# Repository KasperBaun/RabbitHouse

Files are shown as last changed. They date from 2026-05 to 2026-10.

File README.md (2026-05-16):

# OpenSCAD rabbit house

This repository contains OpenSCAD code for a rabbit house.  
The design includes a main house structure and an attached run for the rabbits to exercise.  

## Requirements
- The rabbits must have a cool place to hide should the weather be hot.
- The rabbits must have a dry place to hide should the weather be rainy.
- The rabbits must have a place to exercise and play. It should be possible for them to do binkies and run at full speed.
- The rabbits must be protected from predators, such as cats and birds of prey.
- The rabbits must be protected from the wind, especially in the winter.
- The rabbits must be protected from the sun, especially in the summer.
- The rabbits must have access to fresh air and natural light.
- The rabbits must have access to food and water.
- The rabbits must have access to a litter box or a designated area for waste.

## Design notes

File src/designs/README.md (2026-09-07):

# `designs/` — Active design source

L-shaped rabbit house + run. House gets a gable roof; yard gets a mesh lid
(or a mono-pitch for solid covers).
See `CLAUDE.md` (repo root) for full architecture, conventions, and zone split rules.

## Layout

```
designs/
  config.scad                # constants (RH_*, G_*) + roof-geometry helpers — read first
  ground.scad                # SHARED — grass / terrain
  roof_plates_skifer.scad    # cover: gable naturskifer (house only; per-layer entries)
  roof_plates_tagpap.scad    # cover: OSB + tagpap (house + yard)
  roof_plates_eternit.scad   # cover: C18 + Cembrit B7 (house + yard)
  roof_plates_polycarb.scad  # cover: polycarb slab (yard only)
  roof_plates_mesh.scad      # cover: welded-wire lid (yard default)
  house/                     # HUS-zone (X=0..2000, Y=0..3000) — gable roof + kælder
    foundation.scad basement.scad floor.scad framing.scad openings.scad
    roof.scad roof_gable.scad roof/haneband.scad
    roof_plates.scad cladding/cladding.scad + variants
  yard/                      # YARD-zone (X=2000..6000, Y=1000..3000) — mesh-top run
    foundation.scad framing.scad openings.scad
    roof.scad roof_plates.scad mesh.scad
```

## House cover options (`house_roof_cover` in `main.scad`)

| Cover | Roof shape | Slope | Materials |
|---|---|---|---|
| `skifer`  | Gable (35°) | n/a | genbrugs-naturskifer 30×60 i dobbelt dækning på 38×73 lægter + 25×50 afstandslister |
| `tagpap`  | Mono-pitch (4,6°) | 8 % fald | 18 mm OSB + 4 mm tagpap + alu sternkapsler |
| `eternit` | Mono-pitch (~14°) | 25 % fald (steeper eh_back) | 38×73 C18 lægter + Cembrit B7 |

## Yard cover options (`yard_roof_cover` in `main.scad`)

`mesh` (default — wire lid straight on the top plates), `polycarb`, `tagpap`, or `eternit`.

## Toggles

Top of `main.scad`: set `house_roof_cover`, `yard_roof_cover`,
`cladding_type`.
Comment/uncomment individual `Render*()` calls below to isolate a building system.

`PALETTE` is the palette vector threaded into every house `Render*()` call:
the cladding, casings, corner boards, soffit and vindskeder are painted black
as built, while structural timber (studs, spær, afstandslister, taglægter)
stays natural and the front door leaf is bare plywood.

With `house_roof_cover == "skifer"` the roof is rendered **step by step** — one
call per arbejdsplan work step (`RenderHouseRoofSpaer` → `-Udhaeng` → `-Sofit`
→ `-Undertag` → `-Afstandslister` → `-Laegter` → `-Stern` → `-Fodblik` →
`-Skifer` → `-Vindskeder` → `-Rygning`).
Comment calls in/out to preview each build stage.

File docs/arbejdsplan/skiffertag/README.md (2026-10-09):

# Skiffertag — byggeplan

> Saddeltag 35°, kip langs husets dybde. Genbrugs-naturskifer 30×60 cm i
> klassisk dobbelt dækning på lægter over diffusionsåbent banevareundertag.
> Reference: [`guide-naturskifertag.md`](../../../guide-naturskifertag.md) —
> **ved tvivl gælder guiden**, og ved konflikt med skiferleverandørens
> anvisning gælder leverandøren.

## Hvor er vi nu

| # | Skridt | Status |
|---|---|---|
| 1 | [Spær](01-spaer.md) | ✅ rejst |
| 1a | [**Udhængsspær + klodser**](01a-udhaengsspaer.md) | ⚠️ **ny — skal op før 1b/2** |
| 1b | [Sofit](01b-sofit.md) | ⚠️ **omprojekteret: 4 sider, ventilerede lameller** |
| 2 | [Undertag](02-undertag.md) | ⚠️ lagt, men skal **forlænges ud i gavludhænget** |
| 3 | [Afstandslister](03-afstandslister.md) | ⚠️ sat, men mangler **2 lister over udhængsspærene** |
| 4 | [**Lægter**](04-laegter.md) | ⬅️ **næste skridt — og det mest kritiske** |
| 5 | [Sternbrædder](05-stern.md) | ⚠️ lav stern — skal op **før L1** |
| 6 | [Tagfodsblik, fuglegitter + tagrende](06-fodblik.md) | ⚠️ blikket skal på **før L1** |
| 7 | [Sortering af sten](07-sortering.md) | kan gøres parallelt med 4–6 |
| 8 | [Læg skifer](08-skifer.md) | |
| 9 | [Dobbelt vindskede](09-vindskeder.md) | |
| 10 | [Rygning](10-rygning.md) | |

Skridtene matcher 1:1 `Render*`-kaldene i `src/main.scad` — kommentér de
efterfølgende kald ud for at se hvert byggetrin i 3D.

> **Ændring (2026-09-07): gavludhænget bliver bygget færdigt.** Udhænget blev
> båret alene af de udkragede lægter, og de ligger 28 mm over spærplanet. Derfor
> kunne undertaget ikke føres ud, og tagskægget var kun lukket ved de to
> tagfødder. Der kommer nu **ét udhængsspær pr. gavl i spærplanet**
> ([1a](01a-udhaengsspaer.md)); så løber undertaget helt ud, sofitten lukker
> **alle fire** tagskæg ([1b](01b-sofit.md)), og lægterne får anlæg i spidsen.
> Samtidig går stern og vindskede-underbræt fra 25×150 til **25×200**, så de
> dækker spærende + sofitlamel. Trin 1–3 står som bygget og skal
> eftermonteres/forlænges — se de enkelte sider.

> **Ændring (2026-10-09): lægteafstand 255 mm, lægter 38×73, tagrende.**
> Pladerne er hullet **245 mm fra overkanten** og sømmes derfor i lægten
> *under* den, overkanten hviler på. Med den gamle plan (225 mm) ville sømmet
> ramme pladen nedenunder. Planen er nu Komproments standard: 255 mm, pladens
> overkant midt på lægten, overlæg 90 mm. Der kommer tagrende, så forkanten
> ligger 50 mm forbi L1. Lægteplan: [04](04-laegter.md), rækker: [08](08-skifer.md).
> **Rækkefølgen ved tagfoden er stern → tagfodsblik → undertag ud over blikket
> → L1** — nummereringen 4–6 er historisk.

## Nøglemål (kontrolleret)

| Mål | Værdi | Kommer af |
|---|---|---|
| Taghældning | 35° | `G_PITCH_DEG` |
| Skråflade, spærende → kip | **1500 mm** | spærets overkant, jf. skæretegningen |
| Lægteafstand på skråfladen | **255 mm** | pladerne er hullet 245 mm fra overkanten |
| Overlæg (plade *n* over *n−2*) | **90 mm** | 600 − 2 × 255 |
| Rækker pr. tagflade | 7 = række 1 (skåret, skjult) + 4 hele + 2 skårne i toppen | |
| Plader pr. række | **11** | 3340 mm med 1–5 mm fuger |
| Lægter pr. tagflade | **7** (L1–L7), T1 **38×73** | |
| Gavludhæng, bærende | **145 mm** pr. side | udhængsspær + lægteudkragning |
| Udhængsspær + undertag, bredde | **3290 mm** | 3000 + 2 × 145 |
| Lægtelængde | **3290 mm** | 3000 + 2 × 145 udkragning |
| Skiferfladens bredde | **3340 mm** | 3000 + 2 × 170 (til vindskedens yderside) |
| Yderste tagkant | **3390 mm** | 3000 + 2 × 195 (overliggerens yderside) |
| Sofit, tagfod | 280 mm skråmål | 229 vandret / cos 35° — 5 lameller |
| Sofit, gavl | 97 mm | 145 udhæng − 48 mm beklædningstykkelse — 2 lameller |
| Stern / vindskede-underbræt | **25×200** | 63 stak + 95 spær + 21 sofit = 179 skal dækkes |
| Skiferforkant forbi spærenden (L1's underkant) | **50 mm** | 25 mm foran sternen, ned i tagrenden |

### Hvorfor 255 mm

Pladerne er hullet 245 mm fra overkanten. Hver plade sømmes derfor i lægten
under den, dens overkant hviler på, og sømmet skal gå fri af overkanten på
pladen nedenunder. Det kræver en lægteafstand over 245 mm — leverandøren
skriver "lægteafstand altid 255 mm".

| Lægteafstand | Sømmet i forhold til pladen under | Overlæg | Plader i alt |
|---|---|---|---|
| **255 mm** (valgt) | 10 mm fri | **90 mm** | **132** |
| 225 mm (den gamle plan) | 20 mm nede i pladen — umuligt | 150 mm | 168 |

Prisen er margen: 90 mm overlæg er guidens minimum ved 35°, ikke mere. Den
gamle plan forudsatte huller 25–40 mm fra overkanten; de 25–40 mm er afstanden
fra **side**kanten.

## De tre tjek — afklaret

**1. Skråfladen S = 1500 mm. ✅ Bekræftet — du skal ikke måle om.**
Den er regnet ud af dine egne skæretegninger,
[01-spaer-tegninger.html](01-spaer-tegninger.html): spæremnet er et
parallelogram med lige lange kanter på **1500 mm** og lodrette snit i begge
ender. Hælmærket sidder 280 mm fra fodenden langs underkanten, hvilket giver
280 × cos 35° = 229 mm vandret udhæng, og 1500 × cos 35° = 1229 mm vandret
fra fodende til kip — altså præcis kip 1000 mm inde fra vægydersiden.
Geometrien lukker.

> Fugleudskæringen sænker hele taget ~38 mm i forhold til den teoretiske
> linje (det står også på tegningen). Det er en ren lodret forskydning og
> ændrer **ikke** skråfladen — lægteplanen måles fra spærenden og er
> upåvirket.

**2. Sømdimension.** Måles når stenene er hjemme: 4–8 mm sten → 2,8×40
kobbersøm, tykkere/rustik → 3,0×50. Bestil ~500 stk. Det eneste ufravigelige
er at de skal være **kobber**, ikke galvaniserede.

**3. Ventilationsspalten. ✅ Afklaret — der skal ikke ændres noget.**
De 63 mm er rigeligt, fordi 70 mm-kravet slet ikke gælder dette hulrum.
Der er to hulrum i en tagkonstruktion, og de har hver sit krav:

| Hulrum | Krav | Dit tag |
|---|---|---|
| **Over** undertaget (afstandsliste → tagdækning) | **min. 25 mm** | 25 + 38 = **63 mm** ✅ |
| **Under** undertaget (undertag → isolering), kun i en *ventileret* konstruktion | 50 mm ved fast undertag, **70 mm** ved banevare | findes ikke her |

De 70 mm er afstanden mellem undertag og **isolering** — ikke mellem undertag
og skifer. Taget her har ingen isolering oppe mod undertaget (arbejdsplanens
§8 isolerer kun vægge og evt. gulv), så det nederste hulrum eksisterer ikke,
og kravet gælder ikke. Afstandslisten på 25 mm er nøjagtig det, en
banevare kræver ovenpå. **Lægterne kan gå på nu.**

### Det der derimod skal være i orden: at luften kan komme IND og UD

Spaltehøjden er ikke problemet — gennemstrømningen er. Kanalen der lufter er
de **25 mm mellem afstandslisterne, under lægterne**, og den skal være åben i
begge ender:

- **Tagfod (indtag):** kanalen løber ud under L1 til tagkanten.
  Tagfodsblikket ligger under undertaget og over den lave sterns top, så de
  25 mm under L1 står åbne. **Fuglegitteret skal sidde her — i
  afstandsliste-gabet under L1.** Sofittens spalter
  ([01b](01b-sofit.md)) sidder i et *andet* hulrum, under undertaget, og
  erstatter ikke gitteret her.
- **Kip (aftræk):** L7 sidder 10 mm under kippen. Kanalerne løber
  *under* lægterne og mødes i kippen mellem de to L7. De skal ud under rygningsbrædderne, der er
  klodset op på 15 mm lister — **lad rygningens ender være åbne** (eller brug
  en ventileret rygning), ellers står luften stille.

> **Hvis du alligevel isolerer taget:** læg isoleringen **helt op mod**
> undertaget (uventileret konstruktion) — det kræver at undertaget er
> diffusionsåbent, og at der er en tæt dampspærre indvendigt. Læg den
> **aldrig** med en luftspalte på under 70 mm under banevaren; med 95 mm spær
> ville der kun blive 25 mm isolering tilbage, og det er værre end ingenting.
> Der lå mineraluld i et spærfag ved tagfoden på billedet — afklar om det er
> isolering eller bare en prop.

## Lægteplan (skridt 4 — det kritiske)

Mål på skråfladen fra L1's underkant (= spærenden). Pladens overkant ligger
**midt på lægten**; pladen sømmes i lægten under. Klodser, tegninger og
fremgangsmåde: [04-laegter.md](04-laegter.md).

| Lægte | Midte | Pladens top hviler her | Sømmes her |
|---|---|---|---|
| L1 | 36,5 (underkant 0) | — | række 1 (345 mm, skåret af bunden) |
| L2 | **295** | række 1 | række 2 (hel) |
| L3 | **550** | række 2 | række 3 (hel) |
| L4 | **805** | række 3 | række 4 (hel) |
| L5 | **1060** | række 4 | række 5 (hel) |
| L6 | **1315** | række 5 | række 6 (470 mm, skåret af toppen) |
| L7 | 1453,5 (overkant 1490) | række 6 | række 7 (~255 mm = resten fra række 1, nye huller) |

Kontrollen på planen: hvert søm sidder 46,5 mm over lægtens underkant og
10 mm over overkanten på pladen nedenunder.

## Indkøb — det der mangler

| Materiale | Dimension | Køb | Skridt |
|---|---|---|---|
| Konstruktionstræ C24, udhængsspær | 45×95 mm | **2 stk à 3,6 m** (4 × 1500; klodser af afkortet) | 1a |
| Skruer, udhængsspær/klodser | 5,0×80 | 48 stk + 2 hulplader | 1a |
| Høvlet forskalling m/fas, sofitlameller | 21×45 mm (jem & fix 25×50) | **22 stk à 2,4 m** (~45 m brugt) | 1b |
| Insektnet, rustfrit/alu ≤ 2 mm | 300 / 100 mm bredt | ~7 m + ~6 m | 1b |
| Afstandslister, ekstra over udhængsspær | 25×50 mm | 4 stk à 1,5 m (6 m) | 3 |
| Taglægter T1 | 38×73 mm | **14 stk à 3,6 m** (14 × 3290 brugt) | 4 |
| Søm til lægter | 100 mm | ~170 stk (2 pr. lægte × spær) | 4 |
| Sternbrædder | 25×200 mm | 2 stk à 3,6 m | 5 |
| Tagfodsblik, sort/antracit | — | 7 m | 6 |
| Fuglegitter, ventileret, sort | — | 7 m | 6 |
| Tagrende m. rendejern, endebunde, nedløb | — | 2 × ~3,4 m | 6 |
| Opklodsningsliste | 10×25 mm trykimp. | 7 m | 6 |
| **Genbrugs-naturskifer** | 30×60 cm | **165 stk** (132 i taget + ~25 % genbrugsspild) | 7, 8 |
| **Kobbersøm, riflet** | 2,8×40 mm (se tjek 2) | **500 stk ≈ 1,5 kg** (308 brugt) | 8 |
| Kip-liste (kun hvis toprækken vipper) | 8×25 mm | 7 m | 8 |
| Vindskede, underbræt | 25×200 mm | 4 stk à ~1,9 m (8 m) | 9 |
| Vindskede, overligger | 25×150 mm | 4 stk à ~1,9 m (8 m) | 9 |
| Rygningsbrædder | 25×150 mm | 2 stk à 3,4 m | 10 |
| Opklodsningslister, rygning | 15 mm | rest-træ | 10 |
| Zink-rygning | — | 3,5 m | 10 |
| Skruer m. tætningsskive | — | 1 pak | 10 |

Brædderne til randafslutningen: **25×200 ca. 15 m** (stern + vindskede-underbræt)
og **25×150 ca. 15 m** (overligger + rygning) — køb hver dimension samlet. Beregningen af de 132 plader: 11 pr. række (3340 mm inkl. fuger),
7 rækker pr. tagflade, 2 tagflader = 154 stykker — men række 7 skæres af
resterne fra række 1, så der går 6 × 11 × 2 plader til.

**Køb ALDRIG galvaniserede søm til skiferen — kun kobber.** Et skifertag
holder 100+ år; galvaniserede søm gør ikke.

## Sikkerhed (gælder alle skridt)

- Arbejd fra stillads/platform og fra lægterne — **betræd aldrig færdig
  dækning**. Stenene revner usynligt under punktlast.
- Støvmaske + briller ved hugning/skæring af sten.
- Sten løftes op i små bundter; sortér altid på jorden (skridt 7).

## Valg der er truffet — og som guiden ville gøre anderledes

- **Tagrende ved begge tagfødder** (ændret 2026-10-09 — før var den fravalgt).
  Tagfodsblik og skiferforkant ender i renden, se [06](06-fodblik.md).
- **Ingen skiferkit i randzonen.** Guidens §6.6 anbefaler T-kitning af de 3
  yderste sten ved gavlene *selv med undertag*. Det er fravalgt her, fordi
  undertaget og den lukkede dobbelte vindskede tager fygesne og slagregn.
  Overlægget er nu 90 mm (minimum ved 35°), så margenen er mindre end i den
  gamle plan — genovervej kitning, hvis huset står vindudsat.

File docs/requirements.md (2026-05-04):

# Rabbit House — Requirements

One-line, ID-traceable requirements for the rabbit-house build modelled in this repo.
Each `REQ-NNN` is atomic so it can be cited from the PRD, code comments, or build notes.
Where a number is grounded in an external welfare standard, the source is cited inline.

Conventions:
- IDs are stable; never renumber. Add new ones at the end of their section.
- "Rabbit zone" = the meshed enclosure on the left/front (`rabbit_x0`..`rabbit_x1`).
- "Sleeping zone" = the insulated nest box / shelter inside the rabbit zone.

## A. Animal welfare & space

- **REQ-001** — The rabbit zone must give the rabbits continuous 24/7 access to a connected enclosure of at least 3.0 m × 2.0 m × 1.0 m. (src: RWAF minimum)
- **REQ-002** — The rabbit zone must allow each rabbit to take three full hops in a straight line and to stand fully upright on its hind legs without head contact. (src: RWAF)
- **REQ-003** — The structure must house at least one bonded pair; rabbits must never be kept singly in this build.
- **REQ-004** — The rabbit zone must provide separated functional areas for sleeping, eating, drinking, and toileting.
- **REQ-005** — At least one hiding shelter must be available per rabbit, plus one spare (the "n+1" rule), permanently accessible.
- **REQ-006** — The rabbit zone must include at least one elevated platform or lookout the rabbits can jump onto, for vertical enrichment.
- **REQ-007** — A safe digging substrate (sand pit or soil tray) must be available so the rabbits can dig without compromising the perimeter.

## B. Predator protection

- **REQ-008** — All boundaries between the rabbit zone and the outside world must be covered with welded wire mesh of aperture ≤ 25 mm × 13 mm and gauge ≥ 19 (≈ 1.0 mm wire). (src: The Rabbit House, RWAF)
- **REQ-009** — The rabbit-zone perimeter must defeat burrowing predators, either by a buried wire skirt ≥ 300 mm deep or a horizontal apron ≥ 500 mm wide pinned at ground level.
- **REQ-010** — Every gate, hatch, and door into the rabbit zone must use a two-stage lockable latch that resists raccoon, fox, and child opening.
- **REQ-011** — The sluice must operate as an airlock: the inner door and outer door must never be open simultaneously.
- **REQ-012** — The roof above the rabbit zone must fully enclose against aerial predators (hawks, owls) and climbing predators (cats, martens, rats).
- **REQ-013** — No mesh aperture, edge gap, or trim seam in the rabbit zone may exceed 12 mm at any point.
- **REQ-014** — Mesh must be fastened with screwed staples or wire, not stapled with a tacker, on faces a fox can pull at.

## C. Weather & climate (Nordic / temperate-maritime)

- **REQ-015** — The structure must shelter the rabbits from wind, driving rain, direct sun, and snow at all hours of the year.
- **REQ-016** — The sleeping zone must remain dry and draught-free during sustained west-/south-westerly wind and rain.
- **REQ-017** — The roof and overhangs must shed water away from every wall and away from the sleeping zone.
- **REQ-018** — The roof must support a snow load of at least 1.0 kN/m² without deflection, consistent with Nordic minimums.
- **REQ-019** — At least one shaded sub-zone with internal air temperature ≤ 25 °C must exist in the rabbit area at all summer hours; rabbits suffer heat stress above 25 °C.
- **REQ-020** — The build must include an insulated, draught-free nest box usable down to −10 °C ambient.
- **REQ-021** — The foundation must lift the floor ≥ 100 mm above finished grade to keep the floor dry in heavy rain. (existing: `base_height = 120 mm` — meets this.)

## D. Ventilation & air quality

- **REQ-022** — The rabbit zone must support continuous cross-ventilation without exposing the sleeping zone to direct draught. (src: RSPCA)
- **REQ-023** — High and low ventilation openings must exist on opposite walls so warm, ammonia-laden air can rise out and fresh air can replace it.
- **REQ-024** — No part of the rabbit zone may depend on a single closable opening as its only air exchange.

## E. Floor, drainage & substrate

- **REQ-025** — Surface water inside the rabbit zone must drain so no puddle persists more than 30 minutes after heavy rain.
- **REQ-026** — The site must slope (or be regraded to slope) away from the structure at ≥ 1:50 on all sides.
- **REQ-027** — The rabbit floor must be dig-proof: a solid slab, a buried mesh layer, or a wire base under any loose substrate.
- **REQ-028** — Every substrate in rabbit contact must be non-toxic, low-dust, and chew-safe.

## F. Materials & toxicity

- **REQ-029** — No pressure-treated, CCA-treated, or creosoted wood may be used anywhere a rabbit can chew, lick, or rub against it.
- **REQ-030** — All paints, stains, and sealants in the rabbit zone must be fully cured, food-safe, and free of lead, solvent VOCs, and zinc-rich primers in chew range.
- **REQ-031** — All mesh in the rabbit zone must be galvanised-after-welding (GAW) or vinyl-coated, with cut edges deburred or capped to remove zinc flakes and burrs.
- **REQ-032** — Any insulation reachable by rabbits must sit behind a chew-proof inner skin.
- **REQ-033** — No plant from the rabbit-toxic list (yew, oleander, foxglove, lily, ivy, rhododendron, laburnum) may grow within the rabbit zone or overhang it.

## G. Maintenance & human access

- **REQ-034** — A human must be able to walk fully upright into the rabbit zone through a door ≥ 800 mm wide and ≥ 1900 mm high. (existing sluice: 800 × 2100 mm — meets this.)
- **REQ-035** — Every surface inside the rabbit zone must tolerate hosing and standard pet-safe disinfectant for daily cleaning.
- **REQ-036** — Daily droppings clean-up and food/water refill must be achievable by one adult in ≤ 15 minutes.
- **REQ-037** — A removable or hinged-access tray, panel, or floor section must exist beneath any zone where droppings concentrate.
- **REQ-038** — All lighting fixtures and electrical cabling inside the rabbit zone must be either out of rabbit reach or shielded behind chew-proof conduit.

## H. Reserved (former human seating area)

The original Section H covered a human seating area included in the v1
design. That scope was removed in the v2 redesign. IDs `REQ-039` through
`REQ-042` remain reserved and will not be reused.

## H2. House-yard v2 (gabled shelter + polycarbonate run)

Added 2026-04-29 alongside the introduction of the `house_yard_v2` design.
The v2 right-side zone is no longer a human area — it is a 4 m × 3 m
mesh-walled rabbit run with a translucent roof, attached to a 2 m × 3 m
solid gabled rabbit shelter on the left.

- **REQ-049** — The airlock vestibule must double as bedding/hay storage and provide ≥ 0.5 m³ usable storage volume.
- **REQ-050** — The transparent run roof must be ≥ 10 mm twin-wall polycarbonate, UV-stable, and fixed with chew/pry-resistant fasteners that defeat the same predator load as REQ-008/REQ-012.
- **REQ-051** — The pet door in the house↔run partition must remain permanently passable; it is not a sluice and must not be lockable in service. The combined house+run is the rabbit zone of REQ-001.
- **REQ-052** — The house roof ridge runs along the X axis at Y=`width`/2; gable end walls are at X=0 and X=2000, both cladded as triangles. The X=2000 partition gable is the wind-bracing wall the run roof leans against. Eaves run along X at Y=0 (front) and Y=`width` (back).
- **REQ-053** — The run roof must drain to a gutter on the back (Y=`width`) edge; no water may discharge against the partition at X=2000.

## H3. House-yard v3 (unified mono-pitch + ground-plug yard)

Added 2026-05-03 alongside the introduction of the `house_yard_v3` design.
v3 keeps the v2 zoning (2 m × 3 m solid house + 4 m × 3 m mesh yard) but
replaces the gabled shelter and translucent run roof with **one continuous
mono-pitch roof** spanning the entire footprint, and replaces the v2 full
slab with a **slab-under-house-only + ground-plug-yard** foundation.

Updated 2026-05-04: human entry was rerouted through the yard (REQ-059..062),
and yard exterior siding was specified as mesh-only (no clad strip).

- **REQ-054** — A single mono-pitch roof must span the entire 6 m × 3 m
  footprint (house + yard) with no break at the partition. Drop runs
  front-to-back; the drainage gutter sits on the back (Y=`width`) eave.
- **REQ-055** — The concrete slab must extend ONLY under the house
  (X=0..`house_len`); the yard floor must remain natural ground.
- **REQ-056** — Yard corner posts must transfer load through concrete
  ground plugs (not the slab); each plug sits at least 40 mm below
  grade and 100 mm proud, with a steel post-base bracket isolating
  wood from soil moisture.
- **REQ-057** — The yard interior must be live grass at grade, with
  predator-proofing achieved by the perimeter buried apron skirt
  (REQ-009) — no buried mesh layer is required under the yard floor.
- **REQ-058** — Reserved (former back-wall driving-rain clad strip;
  removed in 2026-05-04 revision in favour of full-height mesh).
- **REQ-059** — The exterior of all three yard walls (front, back,
  right) must be welded-wire mesh only, with no klink-board cladding
  on any yard exterior face. Mesh must meet REQ-008 aperture/wire
  requirements (≤ 25 × 13 mm aperture, ≥ 1 mm wire).
- **REQ-060** — Vertical wood stiles (≈ 60 × 60 mm) must divide the
  mesh walls into approximately 1 m panels for structural rigidity
  and constructible mesh-stretching. The yard mesh door's own L/R
  frame stiles count toward this 1 m rhythm on the front wall.
- **REQ-061** — Human entry to the house must be through the yard:
  an exterior mesh door in the yard front (Y=0) leads into the yard,
  and a separate solid human door in the partition (X=`house_len`)
  leads from the yard into the house. The house has no door on its
  outside face (Y=0).
- **REQ-062** — REQ-011 (airlock semantics) is satisfied by the
  yard-as-vestibule: the yard mesh door is the "outer" stage and the
  partition human door is the "inner" stage, and they must not be
  open simultaneously when rabbits are unconfined in the yard.

## I. Safety

- **REQ-043** — No element reachable by rabbits or humans may have a sharp edge, exposed nail, splinter, or pinch point.
- **REQ-044** — All hinges, latches, and fasteners exposed to weather must be rated for outdoor use and remain free-moving for at least 5 years.
- **REQ-045** — No swallowable loose parts (screws, staples, wire offcuts) may be left in the rabbit zone after construction.

## J. Site, regulation & longevity

- **REQ-046** — Footprint and height must comply with the local jurisdiction's rules for unattached outbuildings before construction begins (in DK, sheds > 10 m² generally need a permit).
- **REQ-047** — The structure must respect the locally required setback distance from neighbouring property lines.
- **REQ-048** — The build must remain serviceable for ≥ 10 years with annual maintenance; every wear part (mesh, latches, lighting) must be replaceable without dismantling structural framing.

## References

- RWAF — Space Recommendations: https://rabbitwelfare.co.uk/space-recommendations/
- RWAF — Outdoor Housing: https://rabbitwelfare.co.uk/outdoor-housing/
- RSPCA — Rabbits' Housing Needs (2018): https://www.rspca.org.uk/documents/1494939/7712578/RSPCA+Rabbit+housing+advice+-+updated+May+2018+(on+website).pdf
- The Rabbit House — Wire Mesh Guide: https://www.therabbithouse.com/outdoor/rabbit-mesh.asp
- RSPCA Australia — Where should I keep my rabbits?: https://kb.rspca.org.au/knowledge-base/where-should-i-keep-my-rabbits/

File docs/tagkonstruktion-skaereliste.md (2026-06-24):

# Skæreliste — Tagkonstruktion

> Implementeret i `src/designs/roof_structure.scad` (`RenderHouseRoof()` + `RenderYardRoof()`) + `roof_plates_tagpap.scad` / `roof_plates_eternit.scad`. Materialelister i [tagkonstruktion_eternit.md](tagkonstruktion_eternit.md) og [tagkonstruktion_tagpap.md](tagkonstruktion_tagpap.md). Variant-sammenligning: [tagkonstruktion.md](tagkonstruktion.md).

Skæreliste pr. element. Mål er millimeter; positioner er i bygningens koordinatsystem (X = længde-akse, Y = front→bag).

## Zone-opdeling

Tag-spær og lookouts opdeles ved X=1500 (partition-linjen). Cover-lagene (OSB-dæk, tagpap, eternit) er én sammenhængende dæk — de straddler hl og holdes "fælles" i materialelisten.

| Zone | Tag-elementer der hører til | Render-modul |
| ---- | --- | --- |
| Hus  | Spær X ≤ 1200 (4 stk) + venstre vindskede + venstre lookouts (3) + venstre side-fascia/soffit + front+bag fascia/soffit [0..hl] | `RenderHouseRoof()`  |
| Yard | Spær X ≥ 1800 (9 stk) + højre vindskede + højre lookouts (3) + højre side-fascia/soffit + front+bag fascia/soffit [hl..ll] | `RenderYardRoof()` |
| Fælles | OSB-dæk (15 plader straddler hl); tagpap baner; alu-inddækning; eternit B7 plader + skruer (bølger straddler hl); C18 lægter | `RenderRoofPlates(cover)` |

## Konventioner

- **Fugleudskæring** (= bird's mouth): trekantet kile saves ud af spær-bunden ved bæreflader, så spæret får et fladt sæde på V1's og V2's *flade* toprem.
- På V3 og V5's *skrå* toprem (kun gable-spæret rører dem) er der ingen udskæring — toprem er allerede skåret til samme hældning som spær-bunden, så de matcher fladt mod fladt.
- "Bæreflade" = de 95 mm hvor spæret krydser en toprem.
- Sæde-snit = vandret savsnit, hæl-snit = lodret savsnit. Ved vores lave hældning (4,6°) er hæl-snittet 0 mm — det er reelt bare en lille kile.

## Sammendrag

| Vare | Antal | Hus | Yard | Fælles | Brug |
| --- | ----- | --- | ---- | --- | --- |
| **Træværk** | | | | | |
| Reglar 47×100×3000 mm gran C24 | 13 | 4 | 9 | | Spær (11 regulære + 2 vindskede) |
| OSB-3 plade TG4 18 mm 2397×600 mm | 15 | | | 15 | Tagdæk ~19 m² — plader straddler hl |
| Imp. stern 25×125×3600 mm gran | 6 | 1 | 3 | 2 | Sternbræt hele perimeter — front+bag straddler hl |
| **Tagdækning** | | | | | |
| Phønix Selvbyggerpap 1×5 m | 5 | | | 5 | Selvklæbende, ~5 m²/rulle |
| TagSealer 300 ml Phønix | 3 | | | 3 | Bitumen-fugemasse |
| **Sternkapsler (cap over sternbræt-top)** | | | | | |
| Sternkapsel lige alu 35×25×1000 mm | 13 | | | 13 | Front + bag eaves — sektioner straddler hl |
| Sternkapsel skrå kant alu 35×25×1000 mm | 6 | 3 | 3 | | Venstre side (hus) + højre side (yard) |
| **Beslag og fastgørelse** | | | | | |
| Vinkelbeslag 90×90×40 mm 20-pak | 3 | 1 | 2 | | ~14 brackets på hus-spær, ~34 på yard-spær |
| OSB/spær-skruer 5×80 mm | 250 | | | 250 | OSB på spær + vinkelbeslag-fastgørelse |
| Rustfri tagskruer m. EPDM-pakning | 1 pk  | | | 1 pk | Alu-profiler på OSB (~50 stk) |
| Galvaniseret tagpapsøm | 1 æsk | | | 1 æsk  | Selvbyggerpap på OSB (~150 stk) |

---

## Spær (13 stk — ALLE skæres identisk)

**Råstof:** 45×95×3000 mm gran C24, skæres til **2910 mm** langs slopen.

**Markering på hvert spær (mål fra front-ende):**

| Position på spær | Hvad det er |
| --- | --- |
| 0..220 mm | Front-overhang (stikker ud over V1) |
| 220..315 mm | V1 bæreflade — **fugleudskæring her**  |
| 315..2625 mm | Fri span over bygnings-indre |
| 2625..2720 mm | V2 bæreflade — **fugleudskæring her**  |
| 2720..2910 mm | Bag-overhang (stikker ud over V2) |

**Fugleudskæring (samme ved begge bæreflader, spejlvendt):**

| Mål | Værdi |
| --- | --- |
| Længde langs spær | 95 mm (= toprem-dybde) |
| Største dybde | 7,6 mm ved bæringens indre kant |
| Mindste dybde | 0 mm ved bæringens ydre kant |
| Form | Trekantet kile — sav vandret ind så dybden vokser jævnt |

Ved V1-bæringen er det den indre kant (mod bygningen, position 315 mm) der er 7,6 mm dyb; ved V2-bæringen er det den indre kant (position 2625 mm) der er 7,6 mm dyb. Med andre ord: kilen bliver dybere INDAD mod bygningens midte.

**X-positioner for de 13 spær (på tværs af bygningen):**

| Type | Antal | Zone | X-positioner |
| --- | ----- | ---- | --- |
| Vindskede V | 1 | Hus  | X = -220 |
| Gable V3 | 1 | Hus  | X = 0 (hviler også fladt på V3's skrå toprem hele vejen) |
| Indre (hus) | 2 | Hus  | X = 600, 1200 |
| Indre (yard)| 7 | Yard | X = 1800, 2400, 3000, 3600, 4200, 4800, 5400 |
| Gable V5 | 1 | Yard | X = 5955 (hviler også fladt på V5's skrå toprem) |
| Vindskede H | 1 | Yard | X = 6175 |

**Vinkelbeslag pr. spær:**

- **Regulære spær (11 stk):** 2 vinkelbeslag pr. bæreflade — én på hver side af spæret. Total 4 pr. spær = 44 stk.
- **Vindskede-spær (2 stk):** 1 vinkelbeslag pr. bæreflade på indersiden af spæret (ydersiden er i luften past toprem-forlængelsens ende). Total 2 pr. spær = 4 stk.

Horisontal flange skrues i toprem-toppen; vertikal flange skrues i spær-siden.

---

## OSB-tagdæk (15 plader TG4 18 mm 2397 × 600 mm)

Plader lægges med deres **lange side (2397 mm) PÅ TVÆRS af spær** (= langs X-aksen). Pladens **600 mm bredde matcher spær c/c 600 EXACT** — plade-kanter lander automatisk på spær-centerlinier uden trimning. TG4 har tand-og-not på alle 4 sider, så samlinger glider sammen og er selv-tætnende.

**Layout — 3 plader pr. række × 5 rækker:**

```
        ┌──────┬──────┬──┐  Y=2900 (bag-overhang slut)
        │  R5 (cut 500) │  ← cut sidste række til 500 mm
        ├──────┼──────┼──┤  Y=2400
        │  R4 (3 plader)│
        ├──────┼──────┼──┤  Y=1800
        │  R3           │
        ├──────┼──────┼──┤  Y=1200
        │  R2           │
        ├──────┼──────┼──┤  Y=600
        │  R1           │
        └──────┴──────┴──┘  Y=0 (front-overhang slut)
        X=0   X=2397 X=4794 X=6440
```

**Cuts pr. række (langs X = 6440 mm):**
- Plade 1: 2397 mm fuld (X=0..2397)
- Plade 2: 2397 mm fuld (X=2397..4794)
- Plade 3: skæres til 1646 mm fra fuld 2397 (X=4794..6440, spild 751 mm)

**Cuts langs Y (5 rækker à 600 mm = 3000 mm; tagflade er 2900 mm):**
- Rækker 1-4: 600 mm fulde
- Række 5: skæres til 500 mm bredde fra fuld 600 (spild 100 mm pr. plade i sidste række)

**Skruer:** 5×80 skruer c/c 150 mm langs alle plade-kanter (= langs samlingerne, gennem TG ind i spær) + c/c 300 mm i pladens midte. ~10 skruer pr. plade × 15 plader ≈ 150 skruer i alt.

- Tagflade total: 6440 × 2900 mm ≈ 18,7 m²
- Plade-areal: 2397 × 600 = 1,44 m² pr. plade
- 15 plader × 1,44 m² = 21,6 m² → dækker med ~2,9 m² spild (~14 %)

---

## Sternbræt 25×125 mm imprægneret gran (~19 m)

Sternbræt monteres så **toppen sidder 7 mm over tagpap-toppen** (sternbræt-top = wall_top + 125, tagpap-top = wall_top + 118). Det danner en lille opadgående kant der forhindrer vand i at løbe ud over tagets sider og giver et beskyttet sted til sternkapslen.

| Position | Længde | Note |
| --- | --- | --- |
| Front-eave | 6440 mm | Horisontalt langs hele front-overhang |
| Bag-eave | 6440 mm | Horisontalt langs hele bag-overhang |
| Venstre-eave | 2910 mm | Følger tagets hældning (skrå) |
| Højre-eave | 2910 mm | Samme |
| **Total** | **18,7 m** | 6 stk × 3600 mm dækker med spild |

Skrues fast i spær-ender (front + bag) og vindskede-spær (sider) med 5×80 skruer c/c ~300 mm. Selvbyggerpap rulles op og over sternbræt-toppen og foldes ned over outer-face så vandet drypper af kanten.

---

## Sternkapsler — 2 forskellige typer

Cap'er der glider ned over sternbræt-toppen + den oprullede tagpap-kant. Beskytter sternbræt-træet mod vejret og giver et rent finish.

**Sternkapsel lige alu 35×25×1000 mm** på front + bag eaves (vandret):

| Position | Længde  | Stk |
| --- | --- | --- |
| Front-eave  | 6440 mm | 7 |
| Bag-eave | 6440 mm | 7 |

(7 stk pr. eave: 6 fulde × 1 m = 6 m + 7. stk overlapper 50 mm for at nå de 6,44 m.)

**Sternkapsel skrå kant alu 35×25×1000 mm** på venstre + højre sider (skrå med taget):

| Position | Længde  | Stk |
| --- | --- | --- |
| Venstre-eave | 2910 mm | 3 |
| Højre-eave | 2910 mm | 3 |

Glides ned over sternbræt-toppen (25 mm kapsel-bredde matcher 25 mm sternbræt-tykkelse). Skrues fast gennem topfladen ind i sternbræt-toppen med rustfri tagskruer c/c ~500 mm. **VIGTIGT:** Læg en stribe TagSealer (bitumen-fugemasse, IKKE silikone) UNDER sternkapselen før montering — tætningslag mellem den oprullede tagpap og alu-cap'en. Overlap mellem to sternkapsler: 50 mm, topstykket OVENPÅ bundstykket i vand-strømmens retning.

---

## Tjek

- **Spær:** 13 × 2910 mm = 37,8 m brugt af 13 × 3000 mm = 39 m stock → ~1,2 m spild
- **OSB:** 15 plader TG4 × 1,44 m² = 21,6 m² brugt af 18,7 m² tagflade → ~2,9 m² spild (~14 %). TG4's 600 mm bredde matcher spær c/c 600 så plade-samlinger lander automatisk på spær-centerlinier
- **Selvbyggerpap:** 5 ruller × 5 m² = 25 m² brugt af 19 m² tagflade → ~6 m² spild til overlap mellem baner
- **Sternbræt 25×125:** ~19 m fra 6 × 3600 mm = 21,6 m stock → ~2,6 m spild. Top 7 mm over tagpap
- **Sternkapsler:** lige 13 stk dækker 13 m (front+bag = 12,9 m); skrå 6 stk dækker 6 m (sider = 5,8 m). ~700 kr billigere end tagfod+vindskede
- **Vinkelbeslag:** 11 regulære × 4 + 2 vindskede × 2 = 48 stk, dækket af 3 × 20-pak = 60 stk
- **TagSealer:** 3 × 300 ml = 900 ml. ~19 m fugelinje under alu-flange + overlap-fuger ≈ 25 m bead → 1 tube pr. ~8 m, så 3 tuber er rigeligt

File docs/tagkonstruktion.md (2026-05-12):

# Tagkonstruktion (v3) — variant-sammenligning

To varianter af tag-dækningen er tilgængelige. Vælg via `roof_cover` i `src/designs/v3/build.scad`.

| Aspekt | Eternit B7 | Tagpap (OSB + selvbyggerpap) |
| --- | --- | --- |
| **Cover** | Cembrit/Swisspearl B7 sortblå bølgeplade, 1100×570 mm | Phønix Selvbyggerpap 2-lags på OSB-3 TG4 18 mm |
| **Hældning** | 14° (`roof_cover = "eternit_14"`) | 4,6° / 8 % (`roof_cover = "tagpap_osb"`) |
| **Bærelag** | C18 lægter 38×73 c/c 460 mm | OSB-3 TG4 18 mm (også diaphragm) |
| **Trim** | Stern uden vinkelrygning (åben top-eave) | Sternbræt + alu sternkapsler på alle 4 eaves |
| **Holdbarhed** | ~70 år, vedligeholdelsesfri | ~10-15 år, omlægning forventes |
| **Vægt** | ~14 kg/m² (tungere — kræver støttende lægter) | ~5 kg/m² (lettere, men OSB bærer hele last) |
| **Sværhedsgrad** | Højere — eksakt c/c 460 mm lægtning, plade-håndtering | Lavere — OSB lægges som almindelige plader, tagpap simpelt |
| **Pris-overslag** | ~9.760 kr (~11.000 kr inkl. spild) | ~10.905 kr (~12.000 kr inkl. spild) |
| **Doc** | [tagkonstruktion_eternit.md](tagkonstruktion_eternit.md) | [tagkonstruktion_tagpap.md](tagkonstruktion_tagpap.md)  |

## Fælles træværk

Følgende elementer er identiske i begge varianter og dokumenteres i hver enkelt fil:

- **Spær** 47×100 C24, 13 stk c/c 600 (11 regulære + 2 vindskede), m. fugleudskæring
- **Sternbræt** 25×125 imprægneret gran, ~19 m langs perimeteren (6 stk × 3,6 m)
- **Vinkelbeslag** 90×90×40 — ~48 stk på spær-bæreflader
- **Sofitt** 18 mm krydsfiner på alle 4 tagskæg-undersider
- **Tagrende** 110 mm + nedløb Ø75 ved bag-eave

## Hvilken skal jeg vælge?

| Hvis du... | Vælg |
|---|---|
| Vil have lang holdbarhed (~70 år) og minimal vedligeholdelse | Eternit B7 |
| Vil have lavest pris og hurtigst byggetid | Tagpap |
| Vil have rent visuelt udtryk uden synlige overlap | Tagpap (eller B7 med stort plade-format 1100×1525) |
| Vil have karakteristisk industri-look med synlige bølger | Eternit B7 |
| Er nervøs for korrekt c/c 460 mm lægtning og plade-skæring | Tagpap |

## Stykkeliste på tværs

Detaljeret skæreliste (spær-positioner, fugleudskæring-mål, vinkelbeslag-fordeling) er fælles og findes i [tagkonstruktion-skaereliste.md](tagkonstruktion-skaereliste.md).

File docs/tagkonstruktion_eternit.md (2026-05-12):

# Tagkonstruktion — Eternit B7 variant

> Implementeret i `src/designs/v3/tagkonstruktion_eternit.scad`
> Vælges med `roof_cover = "eternit_14"` i `src/designs/v3/build.scad` (14° hældning, spec-korrekt geometri).
> Fælles framing/sofitt-moduler i `tagkonstruktion_faelles.scad`.

Ensidet tagflade dækket med **Cembrit/Swisspearl B7 eternit-bølgeplader (sortblå)** på C18 taglægter. Pladen er ~70 år holdbar og vedligeholdelsesfri.

Per Swisspearl montagevejledning (rev. 02.2025) kræver B7 minimum **14° hældning** (standard overlæg). Default-værdien `"eternit_b7"` (4,6°) bruges kun til layout-sammenligning og er **ikke buildbar**.

## Lag (oppefra og ned)

1. **Swisspearl 100 Tagskruer** 6×100 mm m. EPDM-pakning — 2 stk pr. plade i bølgetop
2. **Cembrit B7 bølgeplade** 1100×570 mm, 6,5 mm tyk, montagehøjde 65 mm, sortblå
3. **C18 taglægter** 38×73 mm, c/c præcis **460 mm** (= 570 plade − 110 overlap)
4. **Spær** 47×100 C24 c/c 600 mm
5. **Sternbræt** 25×125 + tagrende på bag-eaven

```
                                    ┌─ Swisspearl 100 tagskrue (2 pr. plade)
                                    │
        B7 ╭─╮ ╭─╮ ╭─╮ ╭─╮ ╭─╮ ╭─╮  ▼   ← sortblå corrugated, 65 mm bølgehøjde
       ───┴─┴─┴─┴─┴─┴─┴─┴─┴─┴─┴─┴─┴────  ← lægte-top (B7 trough hviler her)
       │ C18 lægte 38×73 c/c 460 mm  │
       ├─────────────────────────────┤   ← spær-top
       │  spær 47×100 c/c 600 mm     │
       │                             │
       ├──── V1/V2 toprem ───────────┤   ← wall-top
                                          (lag-stak set fra siden)

Bund-pladen hænger 60 mm ud over back-sternbræt-yderkant (drip i tagrende).
Første lægte sidder a-mål = 510 mm inde fra back-sternbræt-yderkant.
```

## Mål

| Egenskab | Værdi |
| --- | --- |
| Tagflade | 6,44 × 2,95 m (~19 m² incl. overhangs) |
| Hældning | 14° (`roof_cover = "eternit_14"`) |
| Spær | 13 stk 47×100 C24 c/c 600 (11 regulære + 2 vindskede) |
| Overhæng | 220 mm front + 180 mm bag + 220 mm i hver side |
| Lægter | 6 stk 38×73 C18 (~6,44 m hver), c/c 460 mm |
| Tagdække | 49 hele B7 plader (7 rækker × 7 plader bredt) + ~5 % spild |
| Lag over spær | 110 mm (38 lægte + 6,5 plade-trough + 65 bølge-amplitude) |

## Konstruktion

**Spær** 47×100 C24 skæres til ~2910 mm med fugleudskæring ved hver ende (95 mm langs × 7,6 mm dyb trekantet kile — se [tagkonstruktion-skaereliste.md](tagkonstruktion-skaereliste.md)). 11 spær c/c 600 fra X=0 til X=5955; vindskede-spær ved X=-220 og X=6175 hviler på den forlængede V1+V2 toprem. Hvert regulært spær fastgøres med 2 vinkelbeslag pr. bæreflade; vindskede-spær får 1 på indersiden.

**C18 taglægter** 38×73 lægges PERPENDIKULÆRT på spær og sømmes med varmforzinkede sømstifter i hvert spær-krydsningspunkt. Layout er bestemt af B7 plade-geometrien:

- **Første lægte (a-mål)** sidder 510 mm inde fra back-sternbræt-yderkant — det er top-kanten af nederste B7 plade-række. Bund-pladens nederste kant hænger 60 mm ud over sternbrættet ned i tagrenden.
- **Subsequent lægter** c/c **præcis 460 mm** opad mod front (= 570 plade − 110 mm minimum overlæg).
- **Top-pladen** ved front-eaven skæres til pasning (~250 mm høj cut-stykke) og bæres af næst-øverste lægte; kort overhang < 460 mm = ingen separat top-lægte nødvendig.

Resultat: **6 lægter** ved Y = 2195 / 1735 / 1275 / 815 / 355 / −105 (V3-koordinatsystem).

**B7 bølgeplader** lægges fra venstre mod højre, startende med nederste række ved bag-eaven. Hver plade overlapper plade-rækken nedenfor med 110 mm og naboplade med 78 mm (= 1100 − 1022 montagebredde). Plader skrues fast med **Swisspearl 100 Tagskruer 6×100** — 2 pr. plade i bølgetop ved øverste kant. Plade-tælling pr. tagflade: **7 rækker langs slope × 7 plader bredt = 49 plader**.

**Sternbræt** 25×125 langs hele perimeteren skrues fast i spær-enderne. Sternbræt-toppen placeres LIGE UNDER eternit-trough-niveau (lægte-top), så B7 pladen kan dryppe frit forbi sternbræt og ned i tagrenden uden kollision.

**Top-eave (front, høj):** Bemærk — denne variant bruger **ikke vinkelrygning**. Top-cut-pladen ved front-eaven har en åben corrugated kant. Hvis vind-drevet regn er en bekymring, kan kanten lukkes med profil-skumstrimmel eller en hjemmebøjet zink-flange (~60 mm bred), men ikke som fabriksleveret Swisspearl-vinkelrygning.

**Tagrende** 110 mm monteres på back-sternbrættets yder-flade med beslag c/c ~550 mm. Nedløb Ø75 i højre side leder vandet til faldsten eller faskine.

## Materialeliste

Stykkevis skæreliste: [tagkonstruktion-skaereliste.md](tagkonstruktion-skaereliste.md).

| # | Vare | Beskrivelse | Antal | Enhed | Pris/enh | I alt | Note |
| --- | --- | --- | ----- | ----- | --- | --- | ---- |
| | **Træværk** | | | | | | |
| 1 | RAW Spærtræ C24 47×100×3000 mm gran | Spær — 11 regulære + 2 vindskede | 13 | stk | ~85,00 | ~1.105 | est. (Stark) |
| 2 | RAW C18 taglægte 38×73×4200 mm | 6 rækker à ~6,44 m + spild → 11 stk × 4,2 m | 11 | stk | 52,50 | 577,50 | [10-4.dk](https://www.10-4.dk/varer/byggematerialer/trae/laegter/38x73mm-taglaegte-c18-1731038073) |
| 3 | Imp. stern 25×125×3600 mm gran | Sternbræt — hele perimeter (~19 m) | 6 | stk | 82,60 | 495,72 | [xl-byg.dk](https://www.xl-byg.dk/produkt/xl-byg-ru-sternbraet-over-trykimpraegneret-25-x-125-x-3600-mm-1143025122-0360) |
| | **Tagdækning (Cembrit B7 sortblå)** | | | | | | |
| 4 | Swisspearl B7 bølgeplade FK 1100×570 sortblå | 49 hele + ~5 % spild ved hjørne-skæringer | 52 | stk | 95,00 | 4.940 | [bygxtra.dk](https://www.bygxtra.dk/produkter/swisspearl-boelgeplade-b7-fk-i-sortblaa-1100x570-mm-1617012) |
| 5 | Swisspearl 100 Tagskrue 6×100 sortblå (100-pak) | 2 pr. plade × 49 + spild = ~108 | 2 | pak | 425,00 | 850,00 | [davidsen.dk](https://www.davidsen.dk/swisspearl-100-tagskrue-m-taetningsskive-6x100-mm-graa-100-stk-c-id525046-p-51601506116) |
| 6 | Swisspearl PVC Skumstrimmel 4,5 mm | Tværgående tætning ved overlap-samlinger (rulle) | 1 | rulle | ~150 | ~150 | est. |
| | **Vandhåndtering** | | | | | | |
| 7 | Tagrende 110 mm stål/plast (sæt 6,5 m) | Bag-eave inkl. tilbehør | 1 | sæt | ~600 | ~600 | est. |
| 8 | Tagrende-beslag | c/c 550 mm langs bag-eave | 12 | stk | ~30 | ~360 | est. |
| 9 | Endebund tagrende 110 mm | Lukker tagrendens to ender | 2 | stk | ~50 | ~100 | est. |
| 10  | Bladsamler 75-82 mm | Filter ved nedløbsudgang | 1 | stk | ~80 | ~80 | est. |
| 11  | Nedløbsrør Ø75 mm × 3 m | Fra tagrende ned til faldsten | 1 | stk | ~200 | ~200 | est. |
| 12  | Nedløbsbøjning Ø75 mm | Knæ-stykker (top + bund) | 2 | stk | ~80 | ~160 | est. |
| | **Beslag og fastgørelse** | | | | | | |
| 13  | Paslode vinkelbeslag 90×90×40 mm (20-pak)  | 48 nødvendige → 3 pak (60 stk) | 3 | pak | ~150 | ~450 | est. ([wood-online](https://wood-online.dk/shop/paslode-vinkelbeslag-542p.html) enkelt-pris 8,48 kr) |
| 14  | NKT Basic skrue 5×80 ruspert (250-pak) | Vinkelbeslag + sternbræt + lægter på spær | 1 | pak | ~225 | ~225 | est. ([bygxtra](https://www.bygxtra.dk/produkter/nkt-basic-skrue-outdoor-50x8045-mm-ruspert-1000-250-stk-1673216)) |
| 15  | NKT lægtesøm 3,4×80 varmf. (≈210 stk) | 2 søm pr. krydsningspunkt × 6 × 13 ≈ 156 | 1 | pak | ~70 | ~70 | est. |
| | | | | | **Total** | **~9.760** | (≈11.000 inkl. realistisk spild + sofitt-kryds.) |

### Note: plade-format

Cembrit B7 fås også i **1100×1525 mm**. Med større plader bliver der færre rækker langs slope (3 i stedet for 7) og dermed kun ~21 plader i stedet for 49. Pris-pr-m² er lavere, men hver plade er tungere og sværere at håndtere solo. SCAD-modellen viser **1100×570 mm** format — skift både SCAD og BOM hvis du foretrækker det store format.

## Bygge-rækkefølge

1. Skær 11 regulære + 2 vindskede spær til ~2910 mm; indsav fugleudskæring ved hver ende
2. Læg spær c/c 600 mm: regulære på V1+V2 toprem, vindskede på toprem-forlængelsen ved X=-220 og X=6175
3. Skru fast med vinkelbeslag — 2 pr. bæreflade på regulære, 1 på indersiden af vindskede
4. **Mål første lægte-position**: 510 mm inde fra back-sternbræt-yderkant. Søm lægte 38×73 (~6,44 m) på alle spær med varmforzinkede søm 3,4×80 — 2 pr. krydsningspunkt
5. **Læg subsequent lægter** c/c præcis 460 mm opad mod front. Brug en målestok eller kort lægte som "klods" mellem hver lægte. Total 6 lægter
6. Monter sternbrædder 25×125 rundt om hele perimeteren. **Sternbræt-toppen placeres LIGE UNDER lægte-top-niveau** (~7 mm under), så B7 pladen kan dryppe frit forbi
7. **Læg B7 pladerne** fra venstre mod højre, startende med nederste række ved bag-eaven:
   - Hver plade overlapper nedenfor med 110 mm og naboplade med 78 mm (= 1022 mm effektiv montagebredde)
   - Skru hver plade med **2 Swisspearl 100 Tagskruer** i bølgetop ved øverste kant (skruer gennem overlap-zonen fastgør også pladen ovenfor)
   - Per spec: brug HJ/HU plader (pre-borede huller). Hvis FK plader, bor ø10 mm hul i bølgetop først, derefter skru fast vinkelret på tagfladen
   - Top-eave: top-cut-pladen efterlades med åben corrugated kant (eller bøj en zink-flange som top-cap hvis ønsket)
8. Monter tagrende-beslag på bag-sternbrædet c/c 550 mm. Klik tagrende på, sæt endebund i hver ende
9. Monter nedløb: bladsamler ved tagrende-udgang → nedløbsbøjning → 3 m nedløbsrør → bøjning ved bunden → ud til faldsten/faskine

## Vigtigt om B7 installation

**Boring og skæring**: Bor- og skærestøv SKAL fjernes straks med en blød børste — hvis det ligger ude på pladen kan det "brænde" sig fast på overfladen. Brug vinkelsliber med diamant-skive ved skæring; bor med ø10 mm bor altid i bølgetop, aldrig i bølgedal.

**Trædesikkerhed**: B7 plader er IKKE trædesikre færdig-installeret. For vores rabbit-house gælder det IKKE — taget er ikke beregnet til at gå på efter installation.

**Skrue-pakning**: Swisspearl 100 Tagskruer har EPDM-pakning under hovedet — sørg for at den ikke deformeres ved overtilspænding. Skru kun til pakningen er let komprimeret (10-20 %).

**Garanti**: Swisspearl yder 20 års garanti på B7 plader når montagevejledning følges. Skæringer i sider/kanter skal være rene; ingen revner.

## Rendering / verificering

```powershell
pwsh src/scripts/audit_renders.ps1
# → _renders/v3/audit/05_tagkonstruktion.png

# Eller direkte (skift roof_cover i build.scad til "eternit_14" først):
openscad -o b7.png src/main.scad
```

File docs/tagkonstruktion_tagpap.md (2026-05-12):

# Tagkonstruktion — Tagpap (OSB + selvbyggerpap) variant

> Implementeret i `src/designs/v3/tagkonstruktion_tagpap.scad`
> Vælges med `roof_cover = "tagpap_osb"` (eller `"tagpap"`) i `src/designs/v3/build.scad`.
> Fælles framing/sofitt-moduler i `tagkonstruktion_faelles.scad`.

Ensidet tagflade dækket med **Phønix Selvbyggerpap (2-lags)** svejset på 18 mm OSB-3 TG4 plader. Tagpap kører på v3's default-hældning (4,6° / 8 % fald) — minimum-hældning for tagpap er 2,5 % = 1,4°, så vi er rigeligt indenfor spec. Sternbræt-toppen afsluttes med **aluinddækning (sternkapsler)** på alle 4 eaves.

## Lag (oppefra og ned)

1. **Aluinddækning / sternkapsler** 35×25 mm — på alle 4 eaves
2. **Phønix Selvbyggerpap overpap** (svejset til underpap)
3. **Phønix Selvbyggerpap underpap** (mekanisk fastgjort til OSB)
4. **OSB-3 TG4** 18 mm — bærer hele coveret, sømmes på spær
5. **Spær** 47×100 C24 c/c 600 mm
6. **Sternbræt** 25×125 + tagrende på bag-eaven

```
        ╔═══════════════════════════════════╗  ← aluinddækning (sternkapsler)
        ║ Phønix overpap (svejset)          ║  ← 4 mm
        ║ Phønix underpap                   ║  ← 3 mm
        ║ OSB-3 TG4 18 mm                   ║  ← 18 mm
        ╠═══════════════════════════════════╣  ← spær-top
        │  spær 47×100 c/c 600 mm           │
        │                                   │
        ├──── V1/V2 toprem ─────────────────┤   ← wall-top
                                                (lag-stak set fra siden)

Tagpap rulles ud parallelt med tagfaldet, overlap 100 mm langs eave, 80 mm
mellem ruller. Sternkapsler glider ned over sternbræt-top + oprullet tagpap-kant.
```

## Mål

| Egenskab | Værdi |
| --- | --- |
| Tagflade | 6,44 × 2,95 m (~19 m² incl. overhangs) |
| Hældning | 4,6° (`roof_cover = "tagpap_osb"`) |
| Spær | 13 stk 47×100 C24 c/c 600 (11 regulære + 2 vindskede) |
| Overhæng | 220 mm front + 180 mm bag + 220 mm i hver side |
| OSB-bærelag | ~7-8 plader 1220×2440 mm (skæres til pasning) |
| Tagpap | 2 lag (underpap + overpap) × ~19 m² ≈ 4 ruller à 10 m² |
| Aluinddækning | ~19 m langs perimeteren (alle 4 eaves) |
| Lag over spær | ~25 mm (18 OSB + 3 underpap + 4 overpap) |

## Konstruktion

**Spær** 47×100 C24 skæres til ~2910 mm med fugleudskæring ved hver ende (samme som eternit-varianten — se [tagkonstruktion-skaereliste.md](tagkonstruktion-skaereliste.md)). 11 spær c/c 600 fra X=0 til X=5955; vindskede-spær ved X=-220 og X=6175 hviler på den forlængede V1+V2 toprem. Hvert regulært spær fastgøres med 2 vinkelbeslag pr. bæreflade; vindskede-spær får 1 på indersiden.

**OSB-3 TG4 18 mm** lægges direkte på spær-toppen med TG4-noter mod nabopladens. Plader skæres til pasning ved barge-spærene (~220 mm overhang på hver side). OSB sømmes på spær med varmforzinkede 3,1×80 søm c/c ~150 mm langs spær-linjen. OSB-pladen fungerer både som bærelag for tagpap OG som diaphragm der overfører kantilever-moment fra side-overhangene tilbage til de bærende spær — derfor er OSB-tykkelsen vigtig.

**Phønix Selvbyggerpap** rulles ud parallelt med tagfaldet (= med længdeaksen langs X). Underpap fastgøres mekanisk til OSB med tagpapsøm c/c ~250 mm. Overpap svejses eller limes med TagSealer til underpap med 100 mm langs-overlap og 80 mm mellem ruller. Yderkant rulles 50 mm op ad sternbrættet og fastgøres med tagpapsøm; sternkapslen glider derefter ned over toppen som beskyttelse.

**Sternbræt** 25×125 langs hele perimeteren skrues fast i spær-enderne. Sternbræt-toppen sidder ~7 mm over tagpap-toppen (= cover_thick + STERN_LIP) så aluinddækningen får et lille kant at gribe om.

**Aluinddækning / sternkapsler** 35×25 mm cap-profil glides ned over sternbræt-top + den oprullede tagpap-kant. Topflange 25 mm dækker sternbræt-top; outer drop 35 mm hænger ned udvendigt forbi sternbræt-front-fladen. Skrues fast med små tag-papskruer c/c ~400 mm i topflangen.

**Tagrende** 110 mm monteres på back-sternbrættets yder-flade med beslag c/c ~550 mm. Tagpap-kanten ved bag-eaven hænger fri ud over tagrende-midtlinjen for korrekt drip. Nedløb Ø75 i højre side leder vandet til faldsten eller faskine.

## Materialeliste

Stykkevis skæreliste: [tagkonstruktion-skaereliste.md](tagkonstruktion-skaereliste.md).

| # | Vare | Beskrivelse | Antal | Enhed | Pris/enh | I alt | Note |
| --- | --- | --- | ----- | ----- | --- | --- | ---- |
| | **Træværk** | | | | | | |
| 1 | RAW Spærtræ C24 47×100×3000 mm gran | Spær — 11 regulære + 2 vindskede | 13 | stk | ~85,00 | ~1.105 | est. (Stark) |
| 2 | Imp. stern 25×125×3600 mm gran | Sternbræt — hele perimeter (~19 m) | 6 | stk | 82,60 | 495,72 | [xl-byg.dk](https://www.xl-byg.dk/produkt/xl-byg-ru-sternbraet-over-trykimpraegneret-25-x-125-x-3600-mm-1143025122-0360) |
| | **Cover (OSB + tagpap)** | | | | | | |
| 3 | OSB-3 TG4 18 mm 1220×2440 mm | Bærelag — 19 m² / 2,98 m²/plade + spild ≈ 8 plader  | 8 | stk | ~225 | ~1.800 | est. |
| 4 | Phønix Selvbyggerpap rulle (~10 m²) | 2 lag (underpap + overpap) × 19 m² + spild = 4 ruller | 4 | rulle | ~600 | ~2.400 | est. |
| 5 | Phønix TagSealer tube | Lim/svejs ved overlap-samlinger | 3 | stk | ~150 | ~450 | est. |
| | **Aluinddækning / sternkapsler** | | | | | | |
| 6 | Alu sternkapsel 35×25 mm (2-3 m lgd.) | Hele perimeteren (~19 m) — alle 4 eaves | 19 | m | ~120 | ~2.280 | est. |
| 7 | Tag-papskrue m. EPDM (100-pak) | Fastgør alu-cap c/c 400 mm | 1 | pak | ~120 | ~120 | est. |
| | **Vandhåndtering** | | | | | | |
| 8 | Tagrende 110 mm stål/plast (sæt 6,5 m) | Bag-eave inkl. tilbehør | 1 | sæt | ~600 | ~600 | est. |
| 9 | Tagrende-beslag | c/c 550 mm langs bag-eave | 12 | stk | ~30 | ~360 | est. |
| 10  | Endebund tagrende 110 mm | Lukker tagrendens to ender | 2 | stk | ~50 | ~100 | est. |
| 11  | Bladsamler 75-82 mm | Filter ved nedløbsudgang | 1 | stk | ~80 | ~80 | est. |
| 12  | Nedløbsrør Ø75 mm × 3 m | Fra tagrende ned til faldsten | 1 | stk | ~200 | ~200 | est. |
| 13  | Nedløbsbøjning Ø75 mm | Knæ-stykker (top + bund) | 2 | stk | ~80 | ~160 | est. |
| | **Beslag og fastgørelse** | | | | | | |
| 14  | Paslode vinkelbeslag 90×90×40 mm (20-pak)  | 48 nødvendige → 3 pak (60 stk) | 3 | pak | ~150 | ~450 | est. ([wood-online](https://wood-online.dk/shop/paslode-vinkelbeslag-542p.html) enkelt-pris 8,48 kr) |
| 15  | NKT Basic skrue 5×80 ruspert (250-pak) | Vinkelbeslag + sternbræt | 1 | pak | ~225 | ~225 | est. ([bygxtra](https://www.bygxtra.dk/produkter/nkt-basic-skrue-outdoor-50x8045-mm-ruspert-1000-250-stk-1673216)) |
| 16  | Tagpapsøm 25 mm varmforzinket (1 kg ≈ 400 stk) | Underpap + 50 mm op ad sternbræt | 1 | æske  | ~80 | ~80 | est. |
| | | | | | **Total** | **~10.905** | (≈12.000 inkl. realistisk spild + sofitt-kryds.) |

## Bygge-rækkefølge

1. Skær 11 regulære + 2 vindskede spær til ~2910 mm; indsav fugleudskæring ved hver ende
2. Læg spær c/c 600 mm: regulære på V1+V2 toprem, vindskede på toprem-forlængelsen ved X=-220 og X=6175
3. Skru fast med vinkelbeslag — 2 pr. bæreflade på regulære, 1 på indersiden af vindskede
4. Læg OSB-3 TG4 plader på spær-toppen med TG4-noter mod hinanden. Søm fast med 3,1×80 varmforzinket c/c ~150 mm langs spær-linjen
5. Skær OSB til pasning ved barge-spærene (~220 mm side-overhang i hver side)
6. Monter sternbrædder 25×125 rundt om hele perimeteren. **Sternbræt-toppen sidder ~7 mm over OSB-tagpap-toppen** (cover_thick + STERN_LIP)
7. Rul Phønix Selvbyggerpap **underpap** ud parallelt med tagfaldet. Fastgør mekanisk med tagpapsøm c/c ~250 mm. Rul kanten 50 mm op ad sternbrættet i alle 4 sider
8. Rul Phønix Selvbyggerpap **overpap** ud. Svejs eller lim med TagSealer til underpap. Overlap 100 mm langs / 80 mm mellem ruller
9. Monter alu-sternkapsler ovenpå sternbræt-top + oprullet tagpap-kant. Skrues fast med tag-papskrue c/c 400 mm
10. Monter tagrende-beslag på bag-sternbrædet c/c 550 mm. Klik tagrende på, sæt endebund i hver ende
11. Monter nedløb: bladsamler ved tagrende-udgang → nedløbsbøjning → 3 m nedløbsrør → bøjning ved bunden → ud til faldsten/faskine

## Vigtigt om tagpap-installation

**Underlag**: OSB-pladerne SKAL være tørre før tagpap lægges på. Fugt-indhold > 18 % → tagpappen bobler op.

**Svejsning vs. lim**: Phønix Selvbyggerpap kan både svejses (med propan-brænder) eller limes (med TagSealer). For hobby-byg er lim simplere og sikrere — der er ingen åben ild, og du kan lægge pappen alene uden hjælper.

**Sternkapsel-orientering**: Topflange skal pege INDAD (mod tagcenter), drop-flange UDAD. Forkert orientering = vand løber under kapslen.

**Garanti**: Phønix yder 10 års garanti på Selvbyggerpap når montagevejledningen følges — herunder mindst 2,5 % fald (vi har 8 %), korrekt overlap, og fastgørelse iht. spec.

## Rendering / verificering

```powershell
pwsh src/scripts/audit_renders.ps1
# → _renders/v3/audit/05_tagkonstruktion.png

# Eller direkte (skift roof_cover i build.scad til "tagpap_osb"):
openscad -o tagpap.png src/main.scad
```

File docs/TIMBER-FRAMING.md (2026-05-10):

# Timber Framing Guidelines — Rabbit House

## Wood Species

- **Trykimprægneret fyr (pressure-treated pine)** for all structural timber in contact with or near the ground: bundrem, stolper, base frame
- **Gran (spruce)** acceptable for upper framing (toprem, losholter, spær) if kept dry under roof
- **NTR class AB** minimum for outdoor use (green-treated)
- All timber should be **construction graded C18 or C24** (ST or T1 marking in Denmark)

## Standard Dimensions (Danish market)

| Element | Dimension | Notes |
|---|---|---|
| Reglar / studs | 45×95 mm | Standard wall stud, sufficient for non-insulated outbuilding |
| Stolper / corner posts | 120×120 mm | Corners carrying roof load; 45×95 reglar elsewhere |
| Bundrem / bottom plate | 45×95 mm | Flat (lying on wide face), bolted to foundation |
| Toprem / top plate | 45×95 mm | Can double up (2×45×95) on long spans >4m |
| Front beam (remme) | 45×180 mm | Main front beam carrying roof, sized for span |
| Losholte / nogging | 45×95 mm | Horizontal bracing between studs |
| Spær / rafters | 45×95 mm, c/c 600 mm | Mono-pitch rafters; use toprem as bearer at both ends |

## Stud Spacing — Rules of Thumb for Small Outbuildings

This is **not** a dwelling. BR18 dimensional requirements for dwellings do not apply. For a small outbuilding (<50 m²):

### Where studs ARE needed
- **Every corner** of the building
- **Both sides of every opening** (doors, pass-throughs, windows)
- **At wall junctions** (where divider wall meets outer wall)
- **One mid-stud** on any wall span longer than ~2000 mm (stiffness, not code)

### Where studs are NOT needed
- **Mesh walls**: The mesh panel + frame provides lateral bracing. Corner posts and plates are sufficient.
- **Cladded walls with short spans** (<2m between supports): The cladding itself provides racking resistance.
- **Above openings**: A header beam (overligger) carries the load; no stud needed in the opening.

### Cladding support
- Klink cladding (22 mm boards) needs support at max **600 mm c/c** — but this can be horizontal battens (lægter) nailed to a few studs, not studs themselves
- For this project: studs at corners + openings + one mid-stud, then horizontal battens at 600 mm for cladding attachment

## Opening Framing

```
        ┌──── toprem ────────────────┐
        │                            │
   stud │    ┌── header ──┐          │ stud
        │    │            │          │
        │  jamb          jamb        │
        │  stud          stud        │
        │    │   opening  │          │
        │    │            │          │
        └──── bundrem ───────────────┘
```

- **Jamb studs**: Full height 45×95 on each side of opening
- **Header (overligger)**: 45×95 flat above opening, carries load from above
- **Sill (under windows)**: 45×95 flat, not structural

## Fastening

| Connection | Fastener |
|---|---|
| Bundrem to foundation | M10 anchor bolts or concrete screws, 600–1000 mm c/c |
| Stud to bundrem/toprem | Skrånagning (toe-nailing) 2× 3.1×90 mm galv. nails each side, or angle brackets |
| Toprem to stolper | 2× 5.0×100 mm screws + angle bracket |
| Cladding to studs/battens | 2.5×50 mm galv. ring-shank nails, 2 per board per support |
| Mesh to frame | 25 mm galv. staples or U-clips, 150 mm c/c |

## Beslag (steel connectors)

Defined in `lib/primitives/beslag.scad`. Each module renders the connector and emits a BOM row.

| Module | Use | Typical part |
|---|---|---|
| `ankerskrue_m10()` | bundrem → fundablok ring, c/c 1000 | M10 × 120 mm anchor screw |
| `vinkelbeslag()` | stud → bundrem / toprem at corners | BMF 90×90×2 angle bracket |
| `spaersko()` | spær → toprem, both ends | Simpson sloping rafter shoe |
| `bjaelkesko()` | beam → post | Beam joist hanger |
| `stroesko()` | floor strø → ledger | 45×95 joist hanger |

All beslag are hot-dip galvanised steel.

## Roof Load Path

```
  Roof → Toprem (front beam 45×180) → Corner posts (120×120)
                                     → Divider post (120×120)
       → Toprem (back, 45×95)       → Corner posts / mid stud
```

- Mono-pitch (ensidet taghældning): front is high side, back is low side
- Roof drop over 4m width: ~220 mm (≈3° slope, minimum for tagpap/roofing felt)
- All top beams slope from front to back — use `hull()` in OpenSCAD to model this

## This Project's Framing Summary

| Wall | Posts/Studs | Plates | Notes |
|---|---|---|---|
| **Back** | 2 corner + 1 mid | Bundrem + toprem (flat) | Cladded, no openings |
| **Front** | 3 posts (corners + divider) + 1 mid | Bundrem + beam (45×180) | Mesh attached to outside |
| **Left (rabbit)** | 2 corner + 1 mid (if >3m) | Bundrem + sloped toprem | Mesh wall, minimal framing |
| **Right (seating)** | 2 corner + 1 mid + window jambs | Bundrem + sloped toprem | Full cladding + window openings |
| **Divider** | 2 jamb studs at pass-through | Header above opening | Mesh + framed pass-through |

## General Notes

- All dimensions in millimeters
- Timber from standard Danish builders' merchants (Bauhaus, Stark, XL-BYG) comes in these sizes
- Pressure-treated timber must be dried before painting/staining — wait 2–3 months or use wet-on-wet primer
- Leave 5–10 mm air gap between bundrem and any concrete/slab for drainage
- Stainless steel or hot-dip galvanised fasteners only — electro-galv will corrode with treated timber

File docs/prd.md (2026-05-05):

# Rabbit House — Product Requirements Document

## 1. Vision

A garden structure that gives a bonded pair of pet rabbits a safe, enriched,
all-weather home.

The build is modelled in OpenSCAD (`main.scad`) and parameterised across three
size presets in `presets.scad`. This PRD defines the *why* behind the model;
the atomic *what* lives in [`requirements.md`](requirements.md) as `REQ-NNN`
items, cited from this document.

## 2. Goals

- **G1.** Rabbits express natural behaviours 24/7 — hopping, standing upright,
  digging, hiding, jumping up — without ever being shut into a small hutch.
  (REQ-001, REQ-002, REQ-005, REQ-006, REQ-007)
- **G2.** A bonded pair (or two pairs) live safely outdoors year-round in a
  Nordic climate. (REQ-015 to REQ-021)
- **G3.** The structure looks intentional in the garden — built shell,
  cladded back wall, gutter line — not a wire mess on the lawn.
- **G4.** Maintenance fits a 15-minute daily routine for one adult.
  (REQ-034 to REQ-037)

## 3. Non-goals

- Indoor / inside-the-house rabbit housing.
- Breeding or multi-litter colony housing.
- Commercial or farm-scale rabbit production.
- Permanent isolation pens for sick or quarantined animals (a vet trip and a
  carrier handle that case).
- A hutch that only gets opened for "exercise time" — RWAF guidance is
  explicit that this is no longer acceptable.
- A human seating, lounge, or co-occupied space sharing the structure. That
  was v1 scope and has been removed; the v2 right-side zone is a rabbit run.

## 4. Users

| User | Primary needs |
|---|---|
| **Garden owner with one bonded pair**, mid-skill DIY | Safe rabbits, easy daily care, garden that still looks like a garden |
| **Rabbit sitter** during owner absence | Walk-in access, obvious feeding/cleaning routine, predator-proof perimeter she can verify by eye |
| **Vet** doing a home visit | Possible to capture and inspect a rabbit without dismantling anything |

## 5. Size presets

Defined in `presets.scad` and selected in `config.scad` via `preset`.

| Preset | Length × Width × Height | Rabbit-zone length | Notes |
|---|---|---|---|
| `6x3` | 6.0 × 3.0 × 2.5 m | 3.3 m | Tight gardens, 1 bonded pair |
| `7x3` | 7.0 × 3.0 × 2.5 m | 4.0 m | **Default.** 1 bonded pair, generous interior space |
| `8x4` | 8.0 × 4.0 × 2.5 m | 4.5 m | Largest preset; room to scale toward two bonded pairs |

All three presets give the rabbit zone alone more than the RWAF
3.0 × 2.0 × 1.0 m absolute minimum (REQ-001), with substantial vertical
clearance for standing upright (REQ-002).

## 6. Layout principles

Multiple designs coexist in the model — `v1` (the original lean-to),
`v2` (the gabled-house + polycarb-run redesign), and `v3` (unified
mono-pitch over slab-house + grass-yard on plugs). All share these
directional decisions, with design-specific zoning overlaid on top.

- **Front** (`Y = 0`) is the open mesh face onto the garden / human entry.
- **Back** (`Y = width`) is the solid cladded wall, taking prevailing-wind
  and driving-rain duty (REQ-016).
- **Left** (`X = 0`), **Right** (`X = length`).

### `v1` zoning

- Mono-pitch roof; left side X=0..`rabbit_len` is the rabbit zone, right
  side is a human seating area. Sluice sits on the divider between rabbit
  zone and seating zone.

### `v2` zoning

- Left X=0..2000 is a solid gabled rabbit shelter:
  - Front-left corner (X=0..1000, Y=0..1000) is the airlock + bedding
    storage cell, with the only outside human door on its Y=0 face.
  - Insulated nest box against the back wall in the rest-of-house space.
  - High gable louver vent (X=0 face) + low back vent for cross-ventilation.
- Right X=2000..6000 is a mesh-walled rabbit run with a translucent
  polycarbonate roof:
  - Mesh on front (Y=0) and right (X=length) walls; back wall solid clad
    with a high vent strip; left wall is the partition gable.
  - Run roof slopes front-high to back-low, draining to the back gutter.
  - Buried apron skirt 500 mm wide on the three exterior sides for dig
    defeat.
- House↔run rabbit pet door at X=2000, low at Y≈1500 — permanently passable
  so the combined enclosure satisfies REQ-001.
- The two-stage human airlock (outer door on the front, inner door at
  Y=`airlock_d`) is the only human entry into the rabbit zone (REQ-011).

## 7. Constraints

- **Climate:** northern European temperate; design points: winter low ≈ −10 °C,
  summer high ≈ 30 °C, snow load ≥ 1.0 kN/m². (REQ-018, REQ-019, REQ-020)
- **Construction:** hobbyist DIY tools; lumber sized to standard metric stock
  (so wall_thickness, base_height, etc. round to buildable numbers).
- **Materials:** must satisfy the toxicity rules in section F of
  `requirements.md` — no pressure-treated wood in chew range, GAW or
  vinyl-coated mesh, cured paints only.
- **Site:** assumes a private garden. The rabbit zone must function even with
  no power available.

## 8. Success criteria

The build is "done" — by the standards this PRD cares about — when:

1. The rabbits have continuous access to ≥ 3 × 2 × 1 m and can demonstrably
   take 3 hops + stand upright. (REQ-001, REQ-002)
2. The perimeter survives a deliberate fox / cat / rat probe test:
   no aperture > 12 mm, no dig-under, no reach-through. (REQ-008 to REQ-013)
3. The sleeping-zone interior stays between 5 °C and 25 °C across the year
   with seasonal bedding adjustment. (REQ-019, REQ-020)
4. One adult cleans the rabbit zone in ≤ 15 minutes from a cold start.
   (REQ-036)

## 9. Risks & mitigations

| Risk | Likelihood | Impact | Mitigation |
|---|---|---|---|
| Predator digs under the perimeter | Medium | Fatal | Buried skirt or 500 mm apron — REQ-009 |
| Summer heat stroke (rabbits decline > 25 °C) | Medium | Fatal | Shade + cross-ventilation — REQ-019, REQ-022, REQ-023 |
| Mesh too coarse; rat or cat reaches in | Low if specced right | Fatal | 25 × 13 mm × 19 g hardware cloth — REQ-008 |
| Wood-treatment poisoning | Low if specced right | Severe | Material spec — REQ-029, REQ-030 |
| Snow load on lean-to roof | Low | Severe | Engineered to 1.0 kN/m² — REQ-018 |
| Owner absence | Certain (holidays) | Mild | Sitter-friendly walk-in + 15-min routine — REQ-034, REQ-036 |
| Mesh tacker staples pulled by fox | Medium | Fatal | Screwed staples / wire ties — REQ-014 |
| Building permit issue post-build | Medium for `8x4` (32 m²) | Severe | Confirm permit before pouring foundation — REQ-046, REQ-047 |

## 10. Open questions

- **Site orientation:** which façade faces the prevailing wind on the actual
  plot? That decides which side stays solid-cladded vs. meshed.
- **Headcount growth:** is the long-term plan one bonded pair, or two? If
  two, the `8x4` preset is the safer default.
- ~~**Right-zone purpose (v2):** what replaces the v1 human seating area?~~
  Resolved 2026-04-29 — the v2 right-side zone is a 4 m × 3 m mesh-walled
  rabbit run with a translucent polycarbonate roof, attached to a 2 m × 3 m
  gabled solid shelter. See `docs/superpowers/specs/2026-04-29-multi-design-refactor-and-house-yard-v2.md`.
- **Power:** is mains routed to the structure, or is lighting on a solar /
  battery loop? Affects routing in `modules/lighting.scad`.
- **Foundation:** slab, piers, or paver-on-gravel? Drives REQ-021 and
  REQ-027.
- **Run extension:** does the rabbit zone exit into a larger fenced run on
  the lawn for daytime grazing? If yes, REQ-008..REQ-013 apply to that run
  too.

## 11. References

- RWAF — Space Recommendations: https://rabbitwelfare.co.uk/space-recommendations/
- RWAF — Outdoor Housing: https://rabbitwelfare.co.uk/outdoor-housing/
- RSPCA — Rabbits' Housing Needs (2018): https://www.rspca.org.uk/documents/1494939/7712578/RSPCA+Rabbit+housing+advice+-+updated+May+2018+(on+website).pdf
- The Rabbit House — Wire Mesh Guide: https://www.therabbithouse.com/outdoor/rabbit-mesh.asp
- RSPCA Australia — Where should I keep my rabbits?: https://kb.rspca.org.au/knowledge-base/where-should-i-keep-my-rabbits/

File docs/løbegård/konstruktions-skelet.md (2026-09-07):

# Konstruktions-skelet — Løbegård

> Implementeret i `src/designs/yard/framing.scad` (`RenderYardFraming()`).  
> Hus-segmentets pendant ligger i [hus/konstruktions-skelet.md](../hus/konstruktions-skelet.md).

Løbegårdens skelet sidder oven på fundamentet (se [fundament.md](fundament.md))
og består af 4 lag pr. væg. Alle mål i mm.

## Stak gennem en yard-væg

```
z=2220 ┌────── toprem 45×95 ──────┐    toprem-top (= bund af mesh-låg)
       │                          │
z=2175 │                          │    toprem-bund (= stud-top)
       │                          │
       │   stud 45×95 C24         │    stud-længde 2008 mm præcis
       │   c/c 600 mm             │    (192 mm kortere end hus-studs)
       │                          │
z=212  │                          │    stud-bund (= bundrem-top)
       ├────── bundrem 45×95 ─────┤    PT NTR-AB
z=167  ├────── DPC 100×2 ─────────┤    bitumen-murpap
z=122  ╞══════════════════════════╡
z=120  ▒▒▒▒▒▒▒▒▒▒▒▒▒▒▒▒▒▒▒▒▒▒▒▒▒▒▒    sokkel-top
```

`RH_YARD_EH_FRONT = RH_YARD_EH_BACK = 2100` → flad eave på alle 3 yard-vægge,
mesh-låget hviler oven på topremmen. Yardens toprem-top står i **2220** —
altså 8 mm **over** husets vægtop (2212), ikke under.

> ⚠ **Uløst konflikt med husets tagudhæng.** Da husets vægge blev sænket til
> 2000 mm studs faldt `G_EAVE_Z` fra 2412 til 2212, og hele husets højre
> tagskæg fulgte med ned. Ved X = 2229 (spærenden) ligger nu spærunderkant
> 2051,7 — sofit 2030,7 — stern-underkant 2011,7, mens yardens vægge står til
> 2220 og løber X = 2000..6000. Yardens V1/V2 gennemskærer derfor husets
> tagudhæng på de første ~254 mm. Vælg én løsning før løbegården bygges:
>
> 1. **Hold yardens vægge tilbage til X ≥ 2260** — første fag står åbent under
>    husets tagskæg, og vandet fra tagfoden drypper ned uden for yardens
>    vægtop. Ændrer ikke højden, og er formentlig rigtigt uanset.
> 2. **Sænk `RH_YARD_EH_*` til ~1880** så toprem-toppen kommer fri under
>    sofitten. Koster 220 mm frihøjde og sprænger yard-dørens 1950 lysning.
>
> Modellen viser konflikten: fjern kommentarerne foran `// yard`-blokken i
> `src/main.scad` og se V4-samlingen.

## Mål-oversigt

| Egenskab | Værdi |
| --- | --- |
| Yard-fodaftryk | 4000 × 2000 mm (X=2000..6000, Y=1000..3000) |
| Sokkel-top | z = 120 mm |
| Stud-bund | z = 167 mm |
| Stud-top | z = 2175 mm |
| Toprem-top | z = 2220 mm |
| Stud-længde | 2008 mm — samme på alle 3 yard-vægge |
| Stud-sektion | 45 × 95 mm gran C24 |
| Stud c/c | 600 mm |
| Mid-rail | 95 × 40 mm i z = 1197 (= 1030 over gulv)  |

Vægge: **V1[yard]** front-segment (Y=1000..1095, X=2000..6000),
**V2[yard]** bag-segment (Y=2905..3000, X=2000..6000),
**V5** højre (X=5905..6000, Y=1095..2905, 1810 mm langt).

Yarden har INGEN junction-stud mod V4 — V4's V1/V2-hjørnesidder hører til
hus-segmentet og fylder hjørnerne ved X=1955..2000.

---

## V1 — Front-segment (med yard-dør)

**Position:** Y=1000..1095, X=2000..6000 (4000 mm lang).  
**Åbning:** Yard-dør 1070 × 2008 mm centreret om X=4000 (rough opening X=3465..4535).

Yard-dørens rough opening når helt op til topremmen (H = 2008 = stud-længde),
så **topremmen er headeren** — ingen separat header-bjælke eller cripples
over åbningen.

### Elevation (set udefra, –Y mod kameraet)

```
z=2220 ──────────────────────────── mesh-låg hviler ovenpå ────────────────────────────
       ┌──────────────────────────────────────────────────────────────────────────────────┐
z=2175 │                              TOPREM 45×95 — 4000 mm                                │
       │                                       (= header over yard-dør)                    │
       ├──┬──────┬──────┬──────────┬─────────────────────────────────────┬──────┬──┬──┬──┤
       │  │      │      │          │                                     │      │  │  │  │
       │  │      │      │          │                                     │      │  │  │  │
       │ S│  S   │  S   │  YDj     │           Y A R D - D Ø R           │  YDj │ S│ S│ E│
       │  │      │      │          │             åbning                  │      │  │  │  │
       │  │      │      │          │            1070 × 2008              │      │  │  │  │
       │  │      │      │          │                                     │      │  │  │  │
z=1217 ├──────────────────────────┤─────────────────────────────────────┤─────────────────┤  ← mid-rail
z=1177 │  │      │      │          │            (mid-rail springer       │      │  │  │  │  ← (40 mm høj)
       │  │      │      │          │             igennem dør-åbningen)   │      │  │  │  │
       │  │      │      │          │                                     │      │  │  │  │
       │  │      │      │          │                                     │      │  │  │  │
z=212  ╞══╧══════╧══════╧══════════╧═════════════════════════════════════╧══════╧══╧══╧══╡
       │                              BUNDREM 95×45 — 4000 mm                              │
z=167  ├──────────────────────────────────────────────────────────────────────────────────┤
z=122  │░░░░░░░░░░░░░░░░░░░░░░░░░░ DPC 100×2 — 4000 mm ░░░░░░░░░░░░░░░░░░░░░░░░░░░░░░░░░░│
z=120  └──────────────────────────────────────────────────────────────────────────────────┘
        X=2000  2600  3200    3420    3465..4535   4535     5000 5600 5955  6000
                                       (Y-DØR)

  S    = grid-stud c/c 600 (full-h, 2008 mm)
  YDj  = yard-dør jamb (full-h, X=3420..3465 og X=4535..4580)
  E    = end-emit grid-stud (X=5955..6000 — ved V5-hjørnet)
  Mid-rail løber CONTINUOUS gennem dør-åbningen som synlig vandret stiver
```

### Skæreliste — V1[yard]

| # | Element | Sektion | Længde (mm) | Antal | Position |
| - | --- | --- | --- | ----- | --- |
| 1 | DPC murpap | 100×2 | 4000 | 1 | Y=1000..1100, X=2000..6000, z=120 |
| 2 | Bundrem PT | 95×45 | 4000 | 1 | Y=1000..1095, X=2000..6000, z=122..167 |
| 3 | Toprem (gran) | 95×45 | 4000 | 1 | Y=1000..1095, X=2000..6000, z=2175..2220 |
| 4 | Stud — grid | 45×95 | 2008 | 5 | X=2000, 2600, 5000, 5600, 5955 |
| 5 | Stud — yard-dør jamb | 45×95 | 2008 | 2 | X=3420..3465 og X=4535..4580 |
| 6 | Mid-rail (venstre for dør) | 95×40 | 1465 | 1 | X=2000..3465, z=1177..1217 |
| 7 | Mid-rail (højre for dør) | 95×40 | 1465 | 1 | X=4535..6000, z=1177..1217 |

**V1[yard] i alt:** 7 full-height studs + 2 mid-rails.  
**Løbende meter 45×95:** 7·2,008 = **14,06 m**.  
**Løbende meter 95×40:** 2·1,465 = **2,93 m**.

> Topremmen er header. Hvis du vil bygge med separat dør-header, skal du
> sænke `RH_YARD_DOOR_H` (nu = stud-længden) — så genererer koden header
> + cripples som de andre døre.

---

## V2 — Bag-segment (intet)

**Position:** Y=2905..3000, X=2000..6000 (4000 mm lang).  
**Åbninger:** ingen.

Solid bag-væg c/c 600 mm med mid-rail på indersiden.

### Elevation (set udefra, +Y mod kameraet)

```
z=2220 ──────────────────────── mesh-låg hviler ovenpå ─────────────────────────
       ┌───────────────────────────────────────────────────────────────────────┐
z=2175 │                       TOPREM 45×95 — 4000 mm                            │
       ├──┬──────┬──────┬──────┬──────┬──────┬──────┬──────┬──┬──┬─────────────┤
       │  │      │      │      │      │      │      │      │  │  │             │
       │ S│  S   │  S   │  S   │  S   │  S   │  S   │  S   │ S│ E│             │
       │  │      │      │      │      │      │      │      │  │  │             │
z=1217 ├──────────────────────────────────────────────────────────────────────┤  ← mid-rail
z=1177 │  │      │      │      │      │      │      │      │  │  │             │
       │  │      │      │      │      │      │      │      │  │  │             │
z=212  ╞══╧══════╧══════╧══════╧══════╧══════╧══════╧══════╧══╧══╧═════════════╡
       │                       BUNDREM 95×45 — 4000 mm                          │
z=167  ├───────────────────────────────────────────────────────────────────────┤
z=122  │░░░░░░░░░░░░░░░░░░░░ DPC 100×2 — 4000 mm ░░░░░░░░░░░░░░░░░░░░░░░░░░░░░░│
z=120  └───────────────────────────────────────────────────────────────────────┘
        X=2000 2600 3200 3800 4400 5000 5600                        5955 6000

  S = grid-stud c/c 600 (full-h)     E = end-emit grid-stud (X=5955..6000)
```

### Skæreliste — V2[yard]

| # | Element | Sektion | Længde (mm) | Antal | Position |
| - | --- | --- | --- | ----- | --- |
| 1 | DPC murpap | 100×2 | 4000 | 1 | Y=2900..3000, X=2000..6000, z=120 |
| 2 | Bundrem PT | 95×45 | 4000 | 1 | Y=2905..3000, X=2000..6000, z=122..167 |
| 3 | Toprem (gran)  | 95×45 | 4000 | 1 | Y=2905..3000, X=2000..6000, z=2175..2220  |
| 4 | Stud — grid | 45×95 | 2008 | 8 | X=2000, 2600, 3200, 3800, 4400, 5000, 5600, 5955 |
| 5 | Mid-rail | 95×40 | 4000 | 1 | X=2000..6000, z=1177..1217 |

**V2[yard] i alt:** 8 full-height studs + 1 mid-rail.  
**Løbende meter 45×95:** 8·2,008 = **16,06 m**.  
**Løbende meter 95×40:** **4,0 m**.

---

## V5 — Højre (intet)

**Position:** X=5905..6000, Y=1095..2905 (1810 mm lang).  
**Åbninger:** ingen.

Solid Y-væg som butter mellem V1 og V2 inderfladser.

### Elevation (set udefra, +X mod kameraet)

```
z=2220 ─────────────────── mesh-låg hviler ovenpå ────────────────────
       ┌─────────────────────────────────────────────────────────────┐
z=2175 │                  TOPREM 45×95 — 1810 mm                       │
       ├──┬──────┬──────┬─────┬───────────────────────────────────────┤
       │  │      │      │     │                                       │
       │ S│  S   │  S   │  E  │                                       │
       │  │      │      │     │                                       │
z=1217 ├─────────────────────┤────────────────────────────────────────┤  ← mid-rail
z=1177 │  │      │      │     │                                       │
       │  │      │      │     │                                       │
z=212  ╞══╧══════╧══════╧═════╧═══════════════════════════════════════╡
       │                  BUNDREM 95×45 — 1810 mm                       │
z=167  ├─────────────────────────────────────────────────────────────┤
z=122  │░░░░░░░░░░░░░░ DPC 100×2 — 1800 mm ░░░░░░░░░░░░░░░░░░░░░░░░░░│
z=120  └─────────────────────────────────────────────────────────────┘
        Y=1095   1695    2295    2860..2905

  S = grid-stud c/c 600 (full-h)     E = end-emit stud (Y=2860..2905)
```

### Skæreliste — V5

| # | Element | Sektion | Længde (mm) | Antal | Position |
| - | --- | --- | --- | ----- | --- |
| 1 | DPC murpap | 100×2 | 1800 | 1 | X=5900..6000, Y=1100..2900, z=120 |
| 2 | Bundrem PT | 95×45 | 1810 | 1 | X=5905..6000, Y=1095..2905, z=122..167 |
| 3 | Toprem (gran)  | 95×45 | 1810 | 1 | X=5905..6000, Y=1095..2905, z=2175..2220  |
| 4 | Stud — grid | 45×95 | 2008 | 4 | Y=1095, 1695, 2295, 2860 |
| 5 | Mid-rail | 95×40 | 1810 | 1 | Y=1095..2905, z=1177..1217 |

**V5 i alt:** 4 full-height studs + 1 mid-rail.  
**Løbende meter 45×95:** 4·2,008 = **8,03 m**.  
**Løbende meter 95×40:** **1,81 m**.

---

## Cross-rib topremme (mesh-låg understøtning)

Mesh-låget spænder 4 m over yarden (X=2000..6000), så der lægges
4 ekstra topremme tværs over yarden c/c 1000 mm fra V1-side til V2-side
ved X=2000, 3000, 4000 og 5000. Hver rib butter mellem V1 og V2's
inderfladser (Y=1095..2905 = 1810 mm) og sidder i samme højde som V1+V2
topremmen så meshen ligger fladt på toppen.

Rib ved X=2000 sidder lige op ad V4's yard-side og forstærker hus/yard-
overgangen.

```
            X=2000   X=3000   X=4000   X=5000
              │        │        │        │
   Y=2905 ────┴────────┴────────┴────────┴────────  ← V2 toprem
              │        │        │        │
              │ rib    │ rib    │ rib    │ rib       (set ovenfra på yard-loft)
              │ 1810   │ 1810   │ 1810   │ 1810
              │        │        │        │
   Y=1095 ────┴────────┴────────┴────────┴────────  ← V1 toprem
              X=2000   X=3000   X=4000   X=5000
```

### Skæreliste — cross-rib topremme

| # | Element | Sektion | Længde (mm) | Antal | Position |
| - | --- | --- | --- | ----- | --- |
| 1 | Toprem-rib (gran) | 95×45 | 1810 | 4 | X=2000, 3000, 4000, 5000, Y=1095..2905, z=2175..2220 |

**Cross-ribs i alt:** 4 stk. **Løbende meter 95×45:** 4·1,81 = **7,24 m**.

---

## Samlet skæreliste — Løbegård

| Element | Sektion | Længde (mm) | Antal | Total løbende meter |
| --- | --- | --- | ----- | --- |
| DPC murpap (V1+V2 yard) | 100×2 | 4000 | 2 | 8,0 m |
| DPC murpap (V5) | 100×2 | 1800 | 1 | 1,8 m |
| Bundrem PT (V1+V2 yard) | 95×45 | 4000 | 2 | 8,0 m |
| Bundrem PT (V5) | 95×45 | 1810 | 1 | 1,81 m |
| Toprem perimeter (V1+V2 yard) | 95×45 | 4000 | 2 | 8,0 m |
| Toprem (V5) | 95×45 | 1810 | 1 | 1,81 m |
| Toprem cross-rib | 95×45 | 1810 | 4 | 7,24 m |
| Full-height stud (V1 7 + V2 8 + V5 4) | 45×95 | 2008 | 19 | 38,15 m |
| Mid-rail (V1[L+R] + V2 + V5) | 95×40 | (1465/4000/1810) | 4 | 8,74 m |

**Total løbende meter 45×95 gran C24 (studs):** **38,15 m**.  
**Total løbende meter 95×45 PT NTR-AB (bundrem):** **9,81 m**.  
**Total løbende meter 95×45 gran (toprem + cross-ribs):** 8,0 + 1,81 + 7,24 = **17,05 m**.  
**Total løbende meter 95×40 gran (mid-rails):** **8,74 m**.  
**Total DPC bånd 100 mm:** **9,8 m**.

### Yard-segment materialeliste (samlet)

| Vare | Antal | Brug |
| --- | ----- | --- |
| Reglar 45 × 95 × 2400 mm gran C24  | 19 | Studs à 2008 mm (200 mm spild pr. stk) |
| Reglar 45 × 95 × 4200 mm gran C24  | 4 | Topremme V1 + V2 (4000 mm) + 1 rib (1810 mm + spild)  |
| Reglar 45 × 95 × 2400 mm gran C24  | 4 | Cross-ribs + V5 toprem (1810 mm hver) |
| Reglar 45 × 95 × 4200 mm PT NTR-AB | 2 | Bundrem V1 + V2 yard (4000 mm) |
| Reglar 45 × 95 × 2400 mm PT NTR-AB | 1 | Bundrem V5 (1810 mm) |
| Reglar 95 × 40 × 4200 mm gran | 3 | Mid-rails — splejses op til 8,7 m total |
| Bitumen-tape 100 mm × 10 m rulle | 1 | Murpap — én rulle (9,8 m) |
| Ankerskruer M10 × 120 | 11 | Bundrem-til-sokkel c/c 1000 mm (4 V1 + 4 V2 + 3 V5) |
| Vinkelbeslag 90×90 + skruer | 8 | 2 hjørner (V1/V5 + V2/V5) × 4 stk |
| Vinkelbeslag jamb-til-toprem | 4 | Yard-dør jamber (top + bund × 2 jamber) |

---

## Bygge-rækkefølge

1. **DPC** — læg bitumen-tape 100 mm bred ovenpå sokkel-ringen på alle
   yard-vægge (V1+V2 yard-segment + V5).

2. **Bundrem** — bor M10-huller c/c 1000 mm, læg bundrem på plads og
   spænd ankerskruerne. Bundremmen butter mod V4's bundrem ved X=2000.

3. **V5 (højre)** først — 4 studs c/c 600 + end-emit. Top-plade ovenpå.

4. **V1[yard] (front-segment)**:
   - Stil grid-studs X=2000, 2600, 5000, 5600, 5955.
   - Stil yard-dør jamber X=3420 og X=4535.
   - Læg topremmen ovenpå — den BLIVER yard-dør-headeren.
   - Fastgør mid-rails (X=2000..3465 og X=4535..6000) ved z=1177..1217.

5. **V2[yard] (bag-segment)**:
   - Stil 8 grid-studs c/c 600.
   - Top-plade ovenpå.
   - Mid-rail full-length (X=2000..6000).

6. **Cross-rib topremme** — sæt de 4 ribs ved X=2000, 3000, 4000, 5000
   ovenpå V1's og V2's topremme. Hver rib er 1810 mm lang og lukker
   span'et fra V1 til V2.

7. **Mid-rail på V5** — fastgør 1810 mm mid-rail i z=1177..1217 indvendigt
   mellem V1 og V2.

8. **Vinkelbeslag** — fastgør V5 mod V1+V2 og spænd alle samlinger.

---

## Verifikation i OpenSCAD

`src/main.scad` rendrer hele yard-skelettet når `RenderYardFraming()` er
enabled. Tjek inden materialebestilling:

- Toprem flat på alle 3 yard-vægge (mesh-låg oven på)
- Stud-længde 2008 mm ens på V1[yard], V2[yard], V5
- Toprem-top ved z = 2220 mm (= 192 mm under hus-toprem)
- 4 cross-rib topremme synlige tværs over yarden c/c 1000 mm
- Mid-rail springer continuous gennem yard-dør-åbningen som vandret stiver
- Yard-dørens åbning når op til topremmen → ingen separat dør-header

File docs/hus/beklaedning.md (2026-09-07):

# Beklædning — Hus

Beklædningen dækker hus-zonen (X = 0..2000). Eave er flad på alle 4 vægge
(RH_EH_FRONT = RH_EH_BACK = 2092 mm; gable-tag oven på giver fald).

| Nr | Område | Materiale | Funktion |
|---|---|---|---|
| B1 | Hus front (V1, X=0..2000, Y=0) | klink m. ét dør-cutout + lag-stack (ingen vinduer) | vejrbeklædning |
| B2 | Hus bag (V2, X=0..2000, Y=3000) | klink + vindpapir + afstandsliste | vejrbeklædning |
| B3 | Hus venstre (V3, X=0) | klink m. side-vindue-cutout + lag-stack | vejrbeklædning |
| B4 | Hus partition yard-side (V4, X=1548, hele Y=0..3000) | klink m. dør-cutouts + lag-stack | vejrbeklædning yard-side |
| B5 | 4 hjørnetrims | 45×45 lodret tømmer (klink) / 70×70 (bob) | dækker klink-end-grain |
| B6 | Indfatning om alle åbninger | 25×70 foring, står ~12 mm proud af klink | dækker klink-snit ved dør/vinduer |
| B7 | Gavl-trekant V1 + V2 | klink ført op til kip, afkortet mod spær | lukker gavl-enden over eave |
| B8 | Vindskede V1 + V2 (2 pr. gavl) | 25×145 barge langs skrå tag-kant | dækker klink-ender ved rake; tag har 200 mm udhæng |

## Lag-stack (snit gennem hus-væg, klink-variant)

```
        inde                                        ude
         │                                           │
         │    STUD 45×95           VINDPAPIR         │
         │    ┌────────────┐       │ AFSTANDSLISTE   │
         │    │            │       │ │  KLINK        │
         │    │            │██     │ │  ┌──┐         │
         │    │            │█      │ │  │  │░░░      │  ← klink-bræt
         │    │            │█      │ │  │  │░░       │    25 mm tykt
         │    │            │█      │ │  │  │░        │    125 mm højt
         │    │            │█      │ │  │  │░        │    25 mm overlap
         │    │            │█      │ │  └──┘         │    → step 100 mm
         │    └────────────┘       │ │     ░         │
         │                         │ └─    ░         │
         │   stud-yderside    1 mm 22 mm   25 mm     │
                              │     │       │
                              vindp. afstand klink
                              (membran) (klemmeliste 22×45 c/c 600)
```

## Mål

| Egenskab | Værdi |
|---|---|
| Hus-footprint | 2000 × 3000 mm |
| Eave-højde (flad, alle 4 vægge) | RH_EH_FRONT = RH_EH_BACK = 2092 mm |
| Sokkel-top (cladding bund) | Z = RH_BASE_H = 120 mm |
| Vindpapir tykkelse | 1 mm (membran) |
| Afstandsliste | 22 × 45 mm, lodret c/c 600 mm |
| Klink (RH_CLAD) | board_h=125, overlap=25, thick=25, lip=20 mm |
| Klink-step (synlig højde pr. række) | 125 − 25 = **100 mm** |
| Hjørnetrim klink | 45 × 45 mm lodret |
| Hjørnetrim bob | 70 × 70 mm lodret |

## Konstruktion

Vindpapir spændes på
stud-ydersiden over hele væggen, fra bundrem-top op til toprem-bund.
Stiftes med klamper c/c 200.

Afstandsliste (klemmeliste) 22 × 45 mm sættes lodret c/c 600 mm —
matcher stud-c2c så hver liste sidder direkte oven over en stud. Den
klemmer vindpapiret fast og skaber et 22 mm ventileret hulrum bag klink.

Klink-brædder 25 × 125 mm sømmes på afstandslisten. Hvert bræt overlapper
det forrige med 25 mm, så regnvand løber ned forbi samlingen uden at
trænge ind. Synlig højde pr. række = 125 − 25 = 100 mm.

Hjørnetrim 45 × 45 mm lodret tømmer sættes ved hver af de 4 hus-hjørner
— overlapper begge klink-flader så raw end-grain er dækket. Alle 4 trims
går til den flade eave (2092 mm).

Indfatning (foring) 25 × 70 mm sættes rundt om hver åbning — hoveddøren
på V1 (eneste åbning i facaden), side-vinduet på V3, hus-dør + pet-dør på V4. Klinken skæres
ud ~8 mm bredere end selve åbningen, og indfatningen dækker det snit: den
står ~12 mm proud af klink-fladen og lapper ~10 mm ind over åbningen, så
der ikke ses rå klink-snit i lysningen. Dør-blade (V1 + V4) flugter med
klink-fladen, så indfatningen sidder direkte an mod bladet uden dyb lysning.

Partition-væggen (V4) klædes i fuld bredde (Y = 0..3000) kun på YARD-siden
(X ≈ 1548). Hus-siden af partition-væggen står ubeklædt — kaninerne kan
ikke gnave isolering når der ingen adgang er til væg-cavity'et.

## Skæreliste — klink

Vægareal og rækker pr. væg (alle 4 hus-vægge):

| Væg | L × H (flad) | Areal brutto | Åbnings-fradrag | Rækker (H÷100) | Lin.m bræt |
|---|---|---|---|---|---|
| Front V1 | 2000 × 2092 | 4,18 m² | − dør 0,97×2,05 | 21 | 42 m |
| Bag V2 | 2000 × 2092 | 4,18 m² | — | 21 | 42 m |
| Venstre V3 | 3000 × 2092 | 6,28 m² | − vindue 0,86×1,0 | 21 | 63 m |
| Partition V4 | 3000 × 2092 | 6,28 m² | − hus-dør 0,87×2,0 − petdør 0,25×0,3 | 21 | 63 m |
| Gavl-trekant V1 + V2 | 2×(2000 × 700 ÷2) | 1,40 m² | — | ~7 pr. gavl | 14 m |
| **Total** | | **22,3 m² brutto (~20 netto)** | | | **224 m** |

V1 og V2 er **gavl-ender**: klink føres op i trekanten fra eave (z=2212) til
kip (z≈2912, 35° fald), afkortet så toppen følger spærets underside.

**Smart-cut strategi for 4200 mm brædder:**

Hvert 4200 mm bræt skæres til **én 3000 mm række** (V3/V4, 1200 mm scrap)
ELLER **to 2000 mm rækker** (V1/V2, 200 mm scrap). Gavl-trekanternes korte
rækker skæres af 1200 mm-scrappen fra V3/V4-brædderne.

| Behov | Antal rækker | Brædder |
|---|---|---|
| 3000 mm rækker (V3 + V4) | 42 | 42 (1 række pr. bræt) |
| 2000 mm rækker (V1 + V2) | 42 | 21 (2 rækker pr. bræt) |
| Gavl-trekant rækker (V1 + V2) | ~14 | (af 1200 mm scrap) |

→ **63 brædder** + 5 % safety for snit ved åbninger + gavle = **67 stk** anbefalet.

## Materialeliste (klink-variant)

Vindpapir-areal (uden fradrag for åbninger; cuttes efter): vægge + gavle =
20,9 + 1,4 = **22,3 m²** → en 1,5 × 25 m rulle (37,5 m²) rækker; 1,5 × 50 m
er standardlager med god buffer.

| # | Vare | Beskrivelse | Antal | Enhed |
|---|---|---|---|---|
| 1 | Vindpapir Tyvek HouseWrap | 1,5 m × 25/50 m rulle, hus-vægge + gavle ~22,3 m² | 1 | rulle |
| 2 | Afstandsliste 22 × 45 × 2400 mm | Lodret klemmeliste c/c 600. V1+V2: 4+4 = 8 stk; V3+V4: 6+6 = 12 stk | 20 | stk |
| 3 | Klink-brædder 25 × 125 × 4200 mm (gran/lærk) | Vægge + gavle 224 lin.m. Smart cut 3000 \| 2×2000, gavle af scrap → 63 stk + safety | 67 | stk |
| 4 | Hjørnetrim 45 × 45 × 2400 mm | 4 hjørner, klink-end-grain dækning (flad eave 2092) | 4 | stk |
| 5 | Indfatning/foring 25 × 70 × 2400 mm | Om åbninger: V1 dør, V3 vindue, V4 hus-dør + pet-dør (~14 lin.m) | 6 | stk |
| 5b | Vindskede 25 × 145 × 2400 mm | Barge langs begge gavl-skrå (4 stk à ~1220 mm, V1 + V2) | 3 | stk |
| 6 | Klamper 25 mm | Stifter til vindpapir, c/c 200 | 1 | pak |
| 7 | Klink-søm 50 mm rustfri | ~4 søm pr. bræt × 224 lin.m / 1,5 m bræt-snit ≈ 600 stk | 1 | pak |
| 8 | Skruer 4 × 60 mm | Afstandsliste + indfatning | 1 | pak |

## Materialeliste — board-on-board alternativ (1-på-2)

Hvis `cladding_type = "board_on_board"` i `src/main.scad`:

| # | Vare | Beskrivelse | Antal | Enhed |
|---|---|---|---|---|
| 1 | Vindpapir Tyvek HouseWrap | Som klink-variant | 1 | rulle |
| 2 | Afstandsliste 22 × 45 × 4200 mm | **Vandret** klemmeliste c/c 600 (brædder står lodret) | ~20 | stk |
| 3 | Savskåret gran 25 × 150 × 4200 mm | Bagbrædder + forbrædder, c/c 250 → ca. 10 m vægbredde × 2 stk/c2c | ~80 | stk |
| 4 | Hjørnetrim 70 × 70 × 2400 mm | 4 hjørner (større trim pga. 50 mm udstik) | 4 | stk |
| 5+ | Klamper, søm, skruer | Som klink-variant | | |

## Bygge-rækkefølge

1. Spænd vindpapir på stud-ydersiden af alle 4 hus-vægge (V1, V2, V3, V4-yard-side); stift c/c 200, overlap 100 mm i samlinger
2. Cut åbninger ud i vindpapir ved døren (V1), side-vinduet (V3), hus-dør + petdør (V4)
3. Sæt afstandsliste 22 × 45 lodret c/c 600 — ovenpå hver stud, gennem vindpapir, skruet ind i stud
4. Skær klink-brædder pr. skærelisten ovenfor (smart cut: én 3000 mm række eller to 2000 mm rækker pr. bræt)
5. Søm klink-brædder vandret på afstandslisten, nederst først, hver overlapper det underliggende med 25 mm. Flad overkant på alle 4 vægge (2092 mm) — gable-spær sидder ovenpå
6. Skær klinken ~8 mm bredere end hver åbning (rå snit skjules af indfatningen)
7. Sæt indfatning 25 × 70 rundt om hver åbning — dækker klink-snittet, står ~12 mm proud, lapper ~10 mm ind over åbningen
8. Sæt 4 hjørnetrim-stykker (45×45) ved hus-hjørnerne — overlapper begge klink-flader

## Rendering / verificering

```powershell
pwsh src/scripts/audit_renders.ps1
```

Inspect:
- Klink-stack ligger UDEN PÅ studsene (ikke embedded i)
- Hjørnetrims dækker klink-end-grain ved alle 4 hus-hjørner
- Indfatning dækker klink-snittet rundt om alle åbninger; dør-blade flugter med klink-fladen (ingen dyb lysning)
- 21 klink-rækker på alle 4 vægge (flad eave 2092 mm)
- Partition-væggen klædt kun på YARD-siden (X = 1547.5)

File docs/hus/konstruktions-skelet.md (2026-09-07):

# Konstruktions-skelet — Hus

> Implementeret i `src/designs/house/framing.scad` (`RenderHouseFraming()`).  
> Yard-segmentets pendant ligger i [løbegård/konstruktions-skelet.md](../løbegård/konstruktions-skelet.md).

Hus-skelettet sidder oven på fundamentet (se [fundament.md](fundament.md))
og består af 4 lag pr. væg. Alle mål i mm.

## Stak gennem en hus-væg

```
z=2212 ┌────── toprem 45×95 ──────┐    toprem-top (= bund af tag-spær)
       │                          │
z=2167 │                          │    toprem-bund (= stud-top)
       │                          │
       │   stud 45×95 C24         │    stud-længde 2000 mm præcis
       │   c/c 600 mm             │
       │                          │
z=212  │                          │    stud-bund (= bundrem-top)
       ├────── bundrem 45×95 ─────┤    PT NTR-AB (trykimprægneret)
z=167  ├────── DPC 100×2 ─────────┤    bitumen-murpap
z=122  ╞══════════════════════════╡
z=120  ▒▒▒▒▒▒▒▒▒▒▒▒▒▒▒▒▒▒▒▒▒▒▒▒▒▒▒    sokkel-top (fundablok-ring)
```

`RH_BASE_H = 120` (sokkel-top over grade), `RH_DPC_T = 2`, `RH_SILL_H = 45`,
`RH_EH_FRONT = RH_EH_BACK = 2092` → flad eave på alle 4 hus-vægge, gable-spær
hviler oven på topremmen.

## Mål-oversigt

| Egenskab | Værdi |
| --- | --- |
| Hus-fodaftryk | 2000 × 3000 mm (X = 0..2000, Y = 0..3000)  |
| Sokkel-top | z = 120 mm |
| Gulv-top | z = 167 mm (= bundrem-top, DPC + sill) |
| Stud-bund | z = 167 mm |
| Stud-top | z = 2167 mm |
| Toprem-top | z = 2212 mm |
| Stud-længde | 2000 mm — samme på alle 4 hus-vægge |
| Stud-sektion | 45 × 95 mm gran C24 |
| Stud c/c | 600 mm |
| Bundrem-/toprem-sektion | 95 × 45 mm (95 mm bred langs væggens dybde)|

Vægge: **V1** front (Y=0), **V2** bag (Y=2905..3000), **V3** venstre (X=0..95),
**V4** partition (X=1905..2000). V3 og V4 butter mellem V1 og V2's
inderfladser i Y=95..2905 og er begge 2810 mm lange.

---

## V1 — Front (kun hoveddør)

**Position:** Y=0..95, X=0..2000 (2000 mm lang).
**Åbning:** hoveddør — lysning **968 × 2047** mm, X=516..1484, z=120..2167.
Indkøbt dør med udvendige karmmål **948 × 2050**, monteret med 10 mm
montagefuge i hver side.

**Ingen vinduer i facaden.** Det eneste glas/lys i gavlen er den
rombeformede udskæring i selve dørbladet (240 × 280 mm hul med ~45 mm
foring, center 1530 mm over karmbunden) — den står åben som bygget.

To ting adskiller V1 fra de øvrige vægge:

- **Bundremmen er skåret væk under døren.** Karmen står direkte på
  sokkel-/gulvniveau (z=120), ikke oven på bundremmen. Derfor er V1's
  bundrem to stykker à 516 mm i stedet for ét på 2000.
- **Topremmen er dør-overligger.** Lysningen når op til toprem-underkanten
  (z=2167), så der er hverken separat header eller cripples over døren.

Karmen er 2050 høj mod en lysning på 2047 — de 3 mm høvles af topremmens
underside ved montage (eller opmål den byggede væg).

### Elevation (set udefra)

```
z=2212 ────────────────────── tag-spær hviler ovenpå ──────────────────────
       ┌───────────────────────────────────────────────────────────────────┐
z=2167 │        TOPREM 45×95 — 2000 mm   (spænder døren som overligger)     │
       ├──┬──────────┬────┬──────────────────────────┬────┬─────┬────┬─────┤
       │  │          │    │                          │    │     │    │     │
       │K │          │ DJ │      D Ø R  lysning      │ DJ │  S  │    │  J  │
       │  │          │    │        968 × 2047        │    │     │    │     │
       │  │          │    │     (karm 948 × 2050)    │    │     │    │     │
z=167  ╞══╧══════════╧════╡                          ╞════╧═════╧════╧═════╡
       │ BUNDREM 95×45     │   bundrem udskåret       │  BUNDREM 95×45      │
z=122  │      516 mm       │                          │      516 mm         │
z=120  └───────────────────┴──────────────────────────┴─────────────────────┘
        X=0 45          471 516                    1484 1529 1800 1845 1955 2000

  K  = hjørnestud (X=0..45, full-h)          J = junction-stud (X=1955..2000)
  DJ = dør-jamb (full-h, X=471..516 og X=1484..1529)
  S  = grid-stud (X=1800..1845)
  Ingen header, sål eller cripples på V1.
```

### Skæreliste — V1

| # | Element | Sektion | Længde (mm) | Antal | Position |
| - | --- | --- | --- | ----- | --- |
| 1 | DPC murpap | 100×2 | 2000 | 1 | Y=0..100, z=120 (gennemgående, også under dørtærsklen) |
| 2 | Bundrem PT | 95×45 | 516 | 2 | X=0..516 og X=1484..2000, z=122..167 |
| 3 | Toprem (gran, = overligger) | 95×45 | 2000 | 1 | Y=0..95, z=2167..2212 — spænder dør-åbningen |
| 4 | Stud — hjørne (mod V3) | 45×95 | 2000 | 1 | X=0..45 |
| 5 | Stud — dør-jamb | 45×95 | 2000 | 2 | X=471..516 og X=1484..1529 |
| 6 | Stud — grid | 45×95 | 2000 | 1 | X=1800..1845 |
| 7 | Stud — junction (mod V4) | 45×95 | 2000 | 1 | X=1955..2000 |

**V1 i alt:** 5 full-height studs (2000). Ingen cripples, headers eller såle.
**Løbende meter 45×95 i V1:** 5·2,0 = **10,0 m** (ekskl. DPC og bundrem-PT).

---

## V2 — Bag (intet)

**Position:** Y=2905..3000, X=0..2000 (2000 mm lang).  
**Åbninger:** ingen.

Solid væg c/c 600 mm.
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

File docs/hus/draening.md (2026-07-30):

# Dræning og fugtsikring — Hus (kælder)

> **Ikke modelleret.** Denne løsning findes ikke i `src/designs/`. Den er en
> efterbygning på det færdige hus og dokumenteres kun her.
> Se `fundament.md` for den ring, der drænes, og `konstruktions-skelet.md`
> for koterne over terræn.

Kælderrummet står med vand året rundt, værst om vinteren. Årsagen er, at der
aldrig blev projekteret noget under terræn, der kan håndtere vand: intet dræn,
intet kapillarbrydende lag under gulvet, ingen fugtspærre under terræn, intet
fald, ingen sump og ingen ventilation.

To ting følger direkte af det:

1. **Kælderen er et lukket badekar.** Gulvunderside (z = −780) ligger i samme
   kote som rendegrøftens bund, så der er intet drænende lag at lede vand hen i
   — og intet afløb.
2. **Rendegrøften virker som en nedsivningsrende.** 30 cm bred × 80 cm dyb med
   løs tilfyldning og uden dræn i bunden. Den samler overflade- og tagvand og
   leverer det til soklens grusbed og til fugerne mellem fundablokkene.
   Fundablokke er udstøbningsblokke — selv med udstøbte kerner er liggefugerne
   ikke vandtætte.

**Mål:** permanent tørt og ventileret kælderrum. Fugt + urin i et ulufteret rum
giver ammoniak, skimmel og risiko for pododermatitis. Sigt efter 40–60 % RF.
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

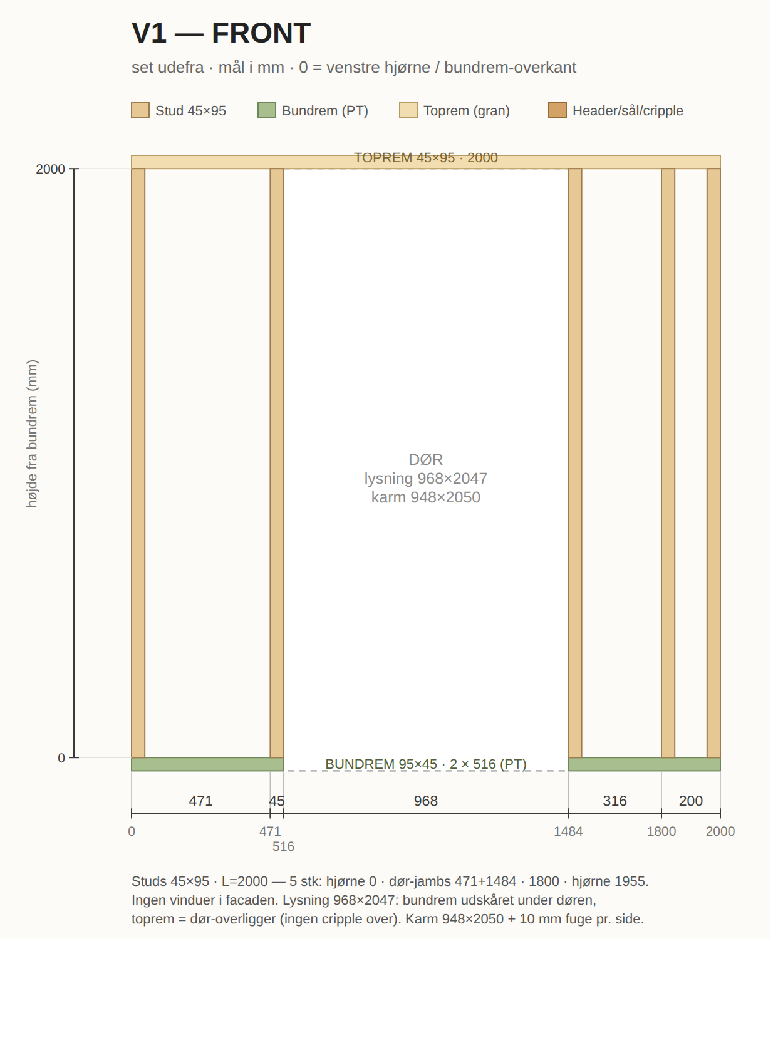
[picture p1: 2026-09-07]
docs/hus/skaereliste/V1-front.png

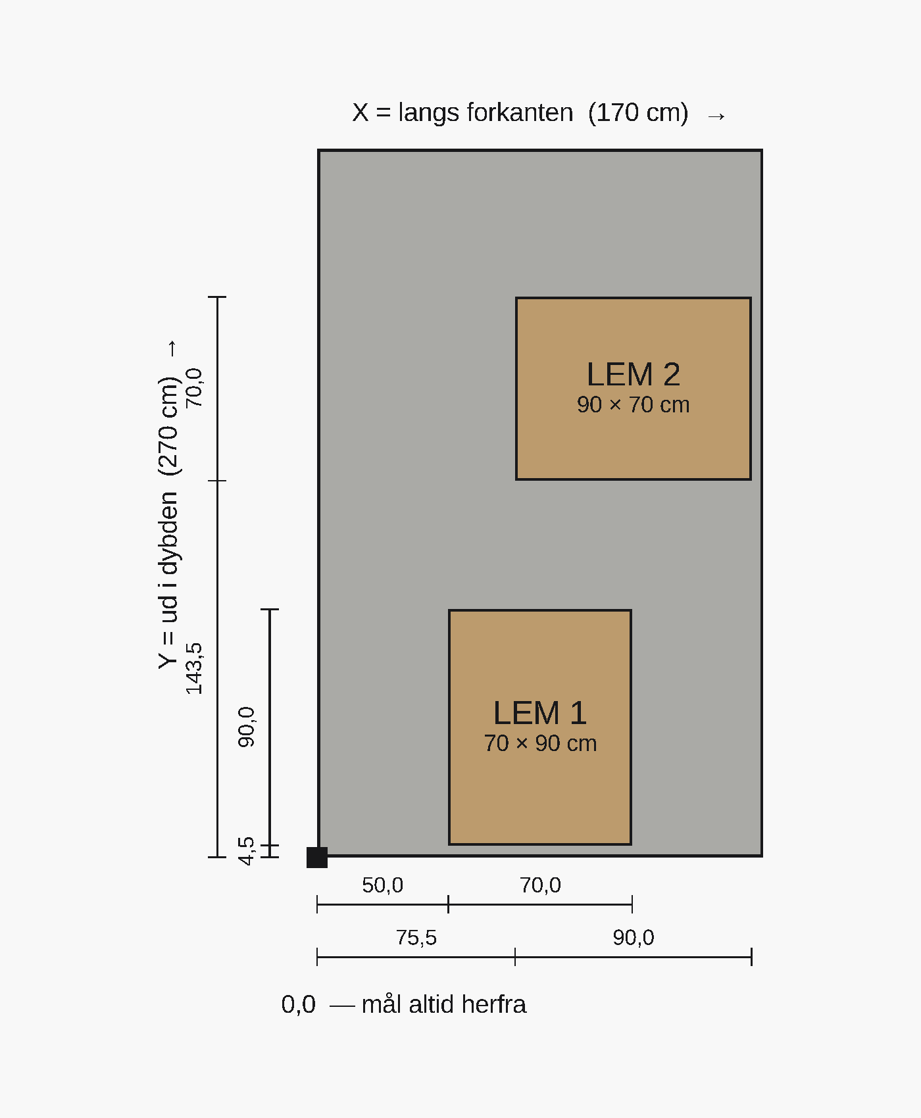
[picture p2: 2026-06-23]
docs/arbejdsplan/img/gulv-opmaaling.png

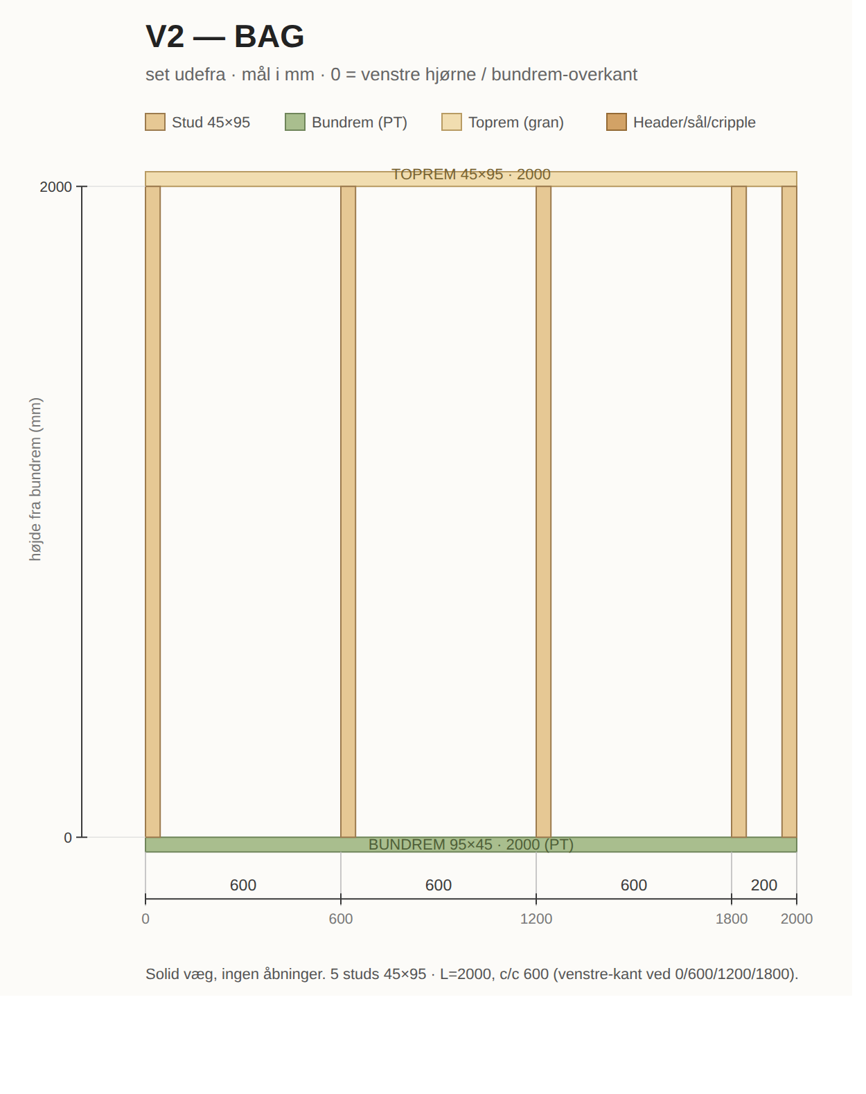
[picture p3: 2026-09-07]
docs/hus/skaereliste/V2-bag.png

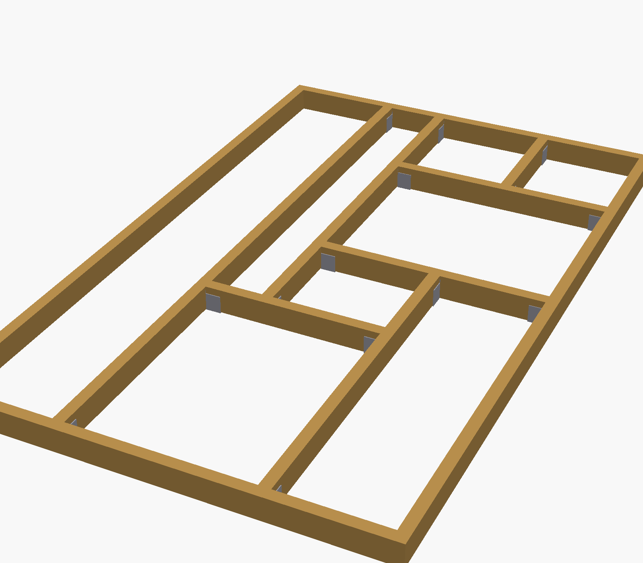
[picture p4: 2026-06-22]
docs/arbejdsplan/img/beslag-3d.png

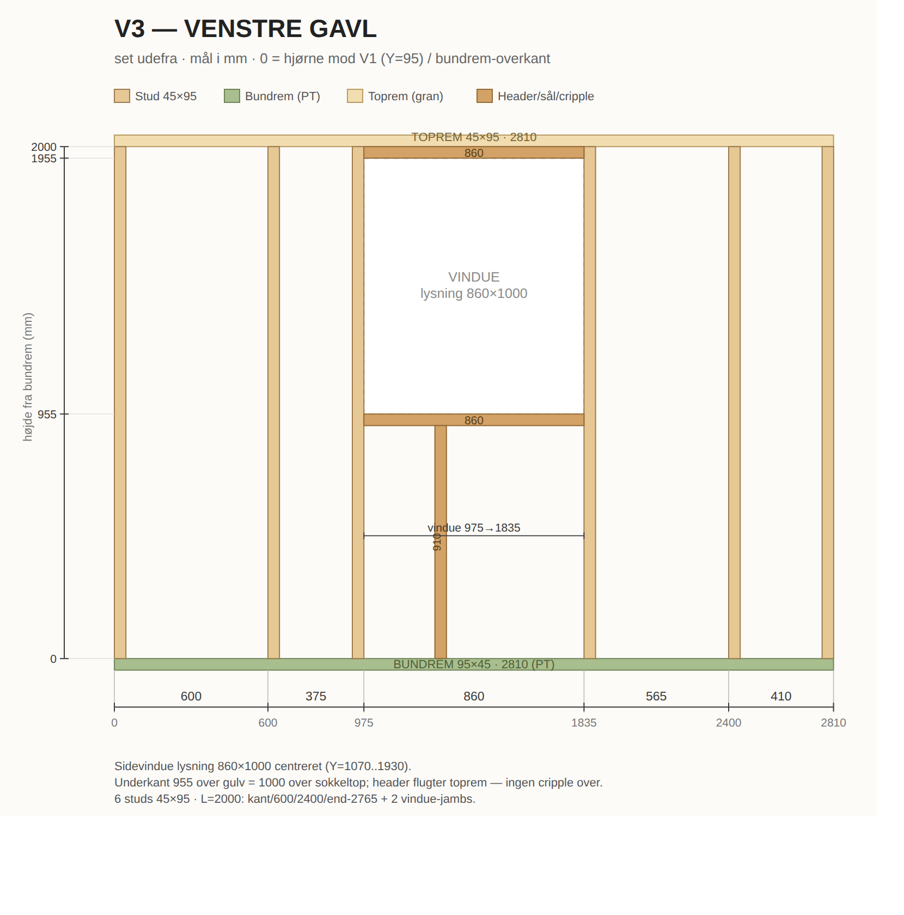
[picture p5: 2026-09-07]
docs/hus/skaereliste/V3-venstre.png

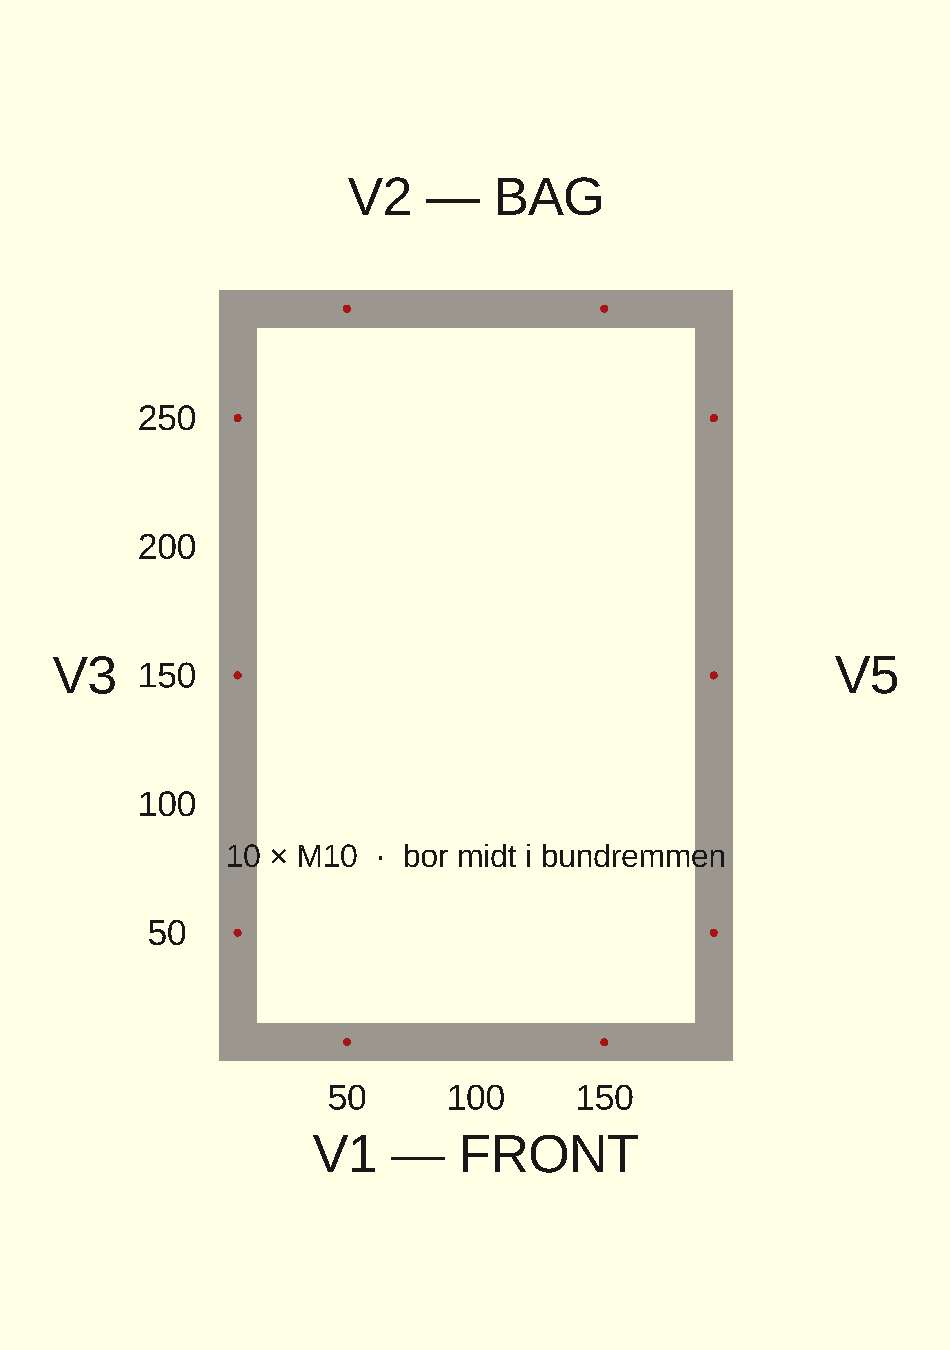
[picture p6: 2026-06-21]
docs/arbejdsplan/img/ankerskruer-plan.png

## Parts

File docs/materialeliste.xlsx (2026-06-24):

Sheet: summary
Rabbit-house BOM — variant selector
Vælg tagdækning: | tagpap
Vælg beklædning: | klink
Valgt konfiguration — totaler
Fundament
Konstruktion
Tagkonstruktion
Beklædning
TOTAL valgt
Sammenligning — alle 4 kombinationer
 | tagpap | eternit_b7 | Δ (eternit − tagpap)
Klink
Board-on-board (1-på-2)
Δ (bob − klink)
Noter
• Dropdowns i B3/B4 styrer totalen i B11 via INDIRECT på sheet-navne.
• Eternit_b7 bruger tungere spær (47×100 C24) end tagpap (men prisen er fra eternit-doc og er et estimat).
• Board-on-board pris er Aros tilbudspris 160 kr/m² (normalpris 225). Klink kommer sortmalet; bob behøver træolie/maling.
• Voliernet og isolering er ens på tværs af beklædningsvarianter.
• Variantvalg i build.scad: roof_cover = "tagpap_osb"|"eternit_b7"; cladding_type = "klink"|"board_on_board".
• Items med pris=tom og noter="TBD …" kræver verifikation før bestilling.

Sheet: hus
Hus — komplet materialeliste (rene Hus-poster + Fælles)
Kategori | Vare | Antal | Enhed | Pris/enh | I alt | Leverandør | Noter | Zone
Fundament
Fundament | Stabilgrus 0-32 mm (hus) | 510 | kg | 0.55 |  | materialepladsen.dk (https://materialepladsen.dk/produkter/grus/Stabilgrus0-32mm) | Under hus-strips (~0,30 m³) | Hus
Fundament | Fundablok 50x20x15 cm (hus) | 80 | stk | 15.75 |  | jemogfix.dk (https://www.jemogfix.dk/fundablok-graa-15-x-20-x-50-cm/4176/9033558/) | 2000x3000 ring, 4 skifter halvstensforbandt — 80 + buffer | Hus
Fundament | Kamstål Ø10 mm × 3 m (hus) | 16 | stk | 45.00 |  | jemogfix.dk (https://www.jemogfix.dk/kamstaal-8-mm-x-3-meter/4164/9042660/) | 2 bund (8 stk for 10 m) + 2 top (8 stk) — lodrette = genbrug af egne metalstænger | Hus
Fundament | Cement 25 kg (hus) | 10 | stk | 75.00 |  | jemogfix.dk (https://www.jemogfix.dk/aalborg-portland-basis-aalborg-cement-25-kg/4170/9814769/) | 1:4 blanding, ~300 L beton | Hus
Fundament | Støbemix 0-16 mm (hus) | 625 | kg | 0.66 |  | materialepladsen.dk (https://materialepladsen.dk/produkter/grus/Stoebemix0-16mm) | ca. 0,38 m³ | Hus
Fundament | Ankerskrue M10 × 120 mm (hus) | 10 | stk | 14.95 |  | jemogfix.dk (https://www.jemogfix.dk/nkt-fasteners-gevindstang-m10-x-1000-mm/5116/9711834/) | est. — bundrem-fast: 2 på V1, 2 på V2, 3 på V3, 3 på V4 | Hus
Fundament | M10 møtrikker + skiver (12-pak) | 2 | pk. | 28.95 |  | jemogfix.dk (https://www.jemogfix.dk/nkt-fasteners-moetrik-elforzinket-m10-12-stk/5118/9513052/) | Fastgør bundrem til ankerskrue ovenfra (1 pak pr. zone) | Fælles
 |  |  |  | Fundament subtotal:
Konstruktion
Konstruktion | Murpap (DPC) | 1 | stk | 99.00 |  | jemogfix.dk (https://www.jemogfix.dk/phoenix-murpap-11-cm-x-20-meter/4210/9036209/) | 11 cm × 20 m — sokkel-isolering, hele perimeter + tværvæg | Fælles
Konstruktion | Bundrem 45×95×3600 PT NTR-AB | 2 | stk | 71.10 |  | jemogfix.dk (https://www.jemogfix.dk/impraegneret-reglar-45-x-95-x-3600-mm/4310/9057360/) | V1 + V2 lange stykker — straddler hl ved splejs | Fælles
Konstruktion | Bundrem 45×95×2400 PT NTR-AB (hus) | 2 | stk | 47.40 |  | jemogfix.dk (https://www.jemogfix.dk/impraegneret-reglar-45-x-95-x-2400-mm/4310/9057358/) | V3 + V4 bundrem | Hus
Konstruktion | Toprem 47×100×3600 C24 gran | 2 | stk | 63.90 |  | jemogfix.dk (https://www.jemogfix.dk/reglar-47-x-100-x-3600-mm/4110/9057297/) | V1 + V2 lange stykker — straddler hl | Fælles
Konstruktion | Reglar 47×100×2400 C24 gran (hus) | 22 | stk | 42.60 |  | jemogfix.dk (https://www.jemogfix.dk/reglar-47-x-100-x-2400-mm/4110/9057295/) | Studs V1[0..hl]+V2[0..hl]+V3+V4 + skrå toprem V3+V4 + headers/cripples | Hus
 |  |  |  | Konstruktion subtotal:
Tagkonstruktion (eternit_b7)
Træværk | Spær 47×100×3000 C24 gran (hus) | 4 | stk | 85.00 |  | Stark (https://www.jemogfix.dk/reglar-47-x-100-x-3000-mm/4110/9057296/) | est. — X<=1200 (incl. vindskede V) | Hus
Træværk | C18 taglægte 38×73×4200 mm (hus) | 6 | stk | 52.50 |  | 10-4.dk (https://www.10-4.dk/varer/byggematerialer/trae/laegter/38x73mm-taglaegte-c18-1731038073) | 6 batten-rækker × 1 stk hus-segment | Hus
Træværk | Imp. sternbræt 25×125×3600 gran (hus) | 2 | stk | 82.60 |  | xl-byg.dk (https://www.xl-byg.dk/produkt/xl-byg-ru-sternbraet-over-trykimpraegneret-25-x-125-x-3600-mm-1143025122-0360) | Venstre side + del af front/bag (~6,4 m) | Hus
Tagdækning | Swisspearl B7 bølgeplade FK 1100×570 sortblå (hus) | 15 | stk | 95.00 |  | bygxtra.dk (https://www.bygxtra.dk/produkter/swisspearl-boelgeplade-b7-fk-i-sortblaa-1100x570-mm-1617012) | 2 plader × 7 rækker + 5 % spild | Hus
Tagdækning | Swisspearl 100 Tagskrue 6×100 (100-pak) (hus) | 1 | pak | 425.00 |  | davidsen.dk (https://www.davidsen.dk/swisspearl-100-tagskrue-m-taetningsskive-6x100-mm-graa-100-stk-c-id525046-p-51601506116) | 2 pr. plade × 14 + spild | Hus
Tagdækning | Swisspearl PVC skumstrimmel 4,5 mm | 1 | rl. |  |  | Cembrit | TBD pris — overlap-tætning, én rulle deler | Fælles
Beslag | Paslode vinkelbeslag 90×90×40 (20-pak) (hus) | 1 | pak |  |  | wood-online.dk (https://wood-online.dk/shop/paslode-vinkelbeslag-542p.html) | TBD pris — ~14 stk på hus-spær | Hus
Beslag | Lægtesøm varmforzinket 2,8×60 |  | stk |  |  | jemogfix.dk | TBD antal + pris | Fælles
 |  |  |  | Tagkonstruktion (eternit_b7) subtotal:
Beklædning (klink)
Beklædning | Klinkbeklædning sortmalet gran 25×125×4200 (pak) | 6 | pak | 497.70 |  | jemogfix.dk (https://www.jemogfix.dk/klinkbeklaedning-sortmalet/4115/9023155/) | Frøslev klink; 4 hus-vægge | Hus
Beklædning | Vindpap (housewrap) | 1 | rl. | 299.00 |  | jemogfix.dk (https://www.jemogfix.dk/phoenix-isoleringspap-rf-650-1-0-x-20-meter/4210/9358237/) | 20 m² pr. rulle; behov ~17,5 m² på 4 hus-vægge | Hus
Beklædning | Klemmelister 25×50×4200 mm | 10 | stk | 28.35 |  | jemogfix.dk (https://www.jemogfix.dk/impraegneret-forskalling-fyr-25-x-50-x-4200-mm/4310/9063674/) | Lodrette afstandslister c/c 600 på hus-vægge | Hus
Beklædning | Hjørnetrim 45×45×2400 mm | 4 | stk | 29.25 |  | jemogfix.dk (https://www.jemogfix.dk/reglar-47-x-50-x-3000-mm/4110/9052623/) | 4 udvendige hus-hjørner | Hus
Beklædning | Isolering mineraluld 95 mm | 20 | m² | 29.61 |  | jemogfix.dk (https://www.jemogfix.dk/glasuld-isover-basic-ruller-95-mm/4180/9039070/) | I hus-stud-rum (4 vægge) | Hus
 |  |  |  | Beklædning (klink) subtotal:
 |  |  |  | Hus-ONLY TOTAL:

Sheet: yard
Yard — komplet materialeliste (rene Yard-poster + Fælles)
Kategori | Vare | Antal | Enhed | Pris/enh | I alt | Leverandør | Noter | Zone
Fundament
Fundament | Stabilgrus 0-32 mm (yard) | 510 | kg | 0.55 |  | materialepladsen.dk (https://materialepladsen.dk/produkter/grus/Stabilgrus0-32mm) | Under yard-strips (~0,30 m³) — 3-sidet 10 m perimeter | Yard
Fundament | Fundablok 50x20x15 cm (yard) | 86 | stk | 15.75 |  | jemogfix.dk (https://www.jemogfix.dk/fundablok-graa-15-x-20-x-50-cm/4176/9033558/) | 3-sidet ring (V4 = hus), 4 skifter halvstensforbandt — 80 + 6 buffer | Yard
Fundament | Kamstål Ø10 mm × 3 m (yard) | 16 | stk | 45.00 |  | jemogfix.dk (https://www.jemogfix.dk/kamstaal-8-mm-x-3-meter/4164/9042660/) | 2 bund (8 stk for 10 m) + 2 top (8 stk) — lodrette = genbrug af egne metalstænger | Yard
Fundament | Cement 25 kg (yard) | 10 | stk | 75.00 |  | jemogfix.dk (https://www.jemogfix.dk/aalborg-portland-basis-aalborg-cement-25-kg/4170/9814769/) | 1:4 blanding, ~300 L beton | Yard
Fundament | Støbemix 0-16 mm (yard) | 625 | kg | 0.66 |  | materialepladsen.dk (https://materialepladsen.dk/produkter/grus/Stoebemix0-16mm) | ca. 0,38 m³ | Yard
Fundament | Ankerskrue M10 × 120 mm (yard) | 10 | stk | 14.95 |  | jemogfix.dk (https://www.jemogfix.dk/nkt-fasteners-gevindstang-m10-x-1000-mm/5116/9711834/) | est. — 4 på V1, 4 på V2, 2 på V5 | Yard
Fundament | M10 møtrikker + skiver (12-pak) | 2 | pk. | 28.95 |  | jemogfix.dk (https://www.jemogfix.dk/nkt-fasteners-moetrik-elforzinket-m10-12-stk/5118/9513052/) | Fastgør bundrem til ankerskrue ovenfra (1 pak pr. zone) | Fælles
 |  |  |  | Fundament subtotal:
Konstruktion
Konstruktion | Murpap (DPC) | 1 | stk | 99.00 |  | jemogfix.dk (https://www.jemogfix.dk/phoenix-murpap-11-cm-x-20-meter/4210/9036209/) | 11 cm × 20 m — sokkel-isolering, hele perimeter + tværvæg | Fælles
Konstruktion | Bundrem 45×95×3600 PT NTR-AB | 2 | stk | 71.10 |  | jemogfix.dk (https://www.jemogfix.dk/impraegneret-reglar-45-x-95-x-3600-mm/4310/9057360/) | V1 + V2 lange stykker — straddler hl ved splejs | Fælles
Konstruktion | Bundrem 45×95×2400 PT NTR-AB (yard) | 3 | stk | 47.40 |  | jemogfix.dk (https://www.jemogfix.dk/impraegneret-reglar-45-x-95-x-2400-mm/4310/9057358/) | V1[2] + V2[2] + V5 bundrem | Yard
Konstruktion | Toprem 47×100×3600 C24 gran | 2 | stk | 63.90 |  | jemogfix.dk (https://www.jemogfix.dk/reglar-47-x-100-x-3600-mm/4110/9057297/) | V1 + V2 lange stykker — straddler hl | Fælles
Konstruktion | Toprem 47×100×3600 C24 gran (yard) | 2 | stk | 63.90 |  | jemogfix.dk (https://www.jemogfix.dk/reglar-47-x-100-x-3600-mm/4110/9057297/) | V1[2] + V2[2] yard-segment toprem | Yard
Konstruktion | Reglar 47×100×2400 C24 gran (yard) | 20 | stk | 42.60 |  | jemogfix.dk (https://www.jemogfix.dk/reglar-47-x-100-x-2400-mm/4110/9057295/) | Studs V1[hl..ll]+V2[hl..ll]+V5 + skrå toprem V5 + yard-dør jamber | Yard
 |  |  |  | Konstruktion subtotal:
Tagkonstruktion (eternit_b7)
Træværk | Spær 47×100×3000 C24 gran (yard) | 9 | stk | 85.00 |  | Stark (https://www.jemogfix.dk/reglar-47-x-100-x-3000-mm/4110/9057296/) | est. — X>=1800 | Yard
Træværk | C18 taglægte 38×73×4200 mm (yard) | 12 | stk | 52.50 |  | 10-4.dk (https://www.10-4.dk/varer/byggematerialer/trae/laegter/38x73mm-taglaegte-c18-1731038073) | 6 batten-rækker × 2 stk yard-segment | Yard
Træværk | Imp. sternbræt 25×125×3600 gran (yard) | 4 | stk | 82.60 |  | xl-byg.dk (https://www.xl-byg.dk/produkt/xl-byg-ru-sternbraet-over-trykimpraegneret-25-x-125-x-3600-mm-1143025122-0360) | Højre side + resten af front/bag (~12,4 m) | Yard
Tagdækning | Swisspearl B7 bølgeplade FK 1100×570 sortblå (yard) | 37 | stk | 95.00 |  | bygxtra.dk (https://www.bygxtra.dk/produkter/swisspearl-boelgeplade-b7-fk-i-sortblaa-1100x570-mm-1617012) | 5 plader × 7 rækker + 5 % spild | Yard
Tagdækning | Swisspearl 100 Tagskrue 6×100 (100-pak) (yard) | 2 | pak | 425.00 |  | davidsen.dk (https://www.davidsen.dk/swisspearl-100-tagskrue-m-taetningsskive-6x100-mm-graa-100-stk-c-id525046-p-51601506116) | 2 pr. plade × 35 + spild | Yard
Tagdækning | Swisspearl PVC skumstrimmel 4,5 mm | 1 | rl. |  |  | Cembrit | TBD pris — overlap-tætning, én rulle deler | Fælles
Beslag | Paslode vinkelbeslag 90×90×40 (20-pak) (yard) | 2 | pak |  |  | wood-online.dk (https://wood-online.dk/shop/paslode-vinkelbeslag-542p.html) | TBD pris — ~34 stk på yard-spær | Yard
Beslag | Lægtesøm varmforzinket 2,8×60 |  | stk |  |  | jemogfix.dk | TBD antal + pris | Fælles
 |  |  |  | Tagkonstruktion (eternit_b7) subtotal:
Beklædning / voliere (klink)
Voliere | Voliernet welded 13×13 mm | 2 | stk | 1350.00 |  | (ukendt) | 1×10 m + 1×25 m — yard front+back+right | Yard
Voliere | Klamper til voliernet |  | stk |  |  | jemogfix.dk | TBD antal + pris | Yard
 |  |  |  | Beklædning / voliere (klink) subtotal:
 |  |  |  | Yard-ONLY TOTAL:

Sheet: sammenligning_beklaedning
Beklædning — prissammenligning ved 16 m² netto facadeareal
Produkt | Mønster | Materiale | Antal | Enhed | Pris/enh | Material kr | Behandl. kr | TOTAL | Δ vs billigst | Leverandør | Note
Imp. klinkbeklædning gran 25×125×3600 | Klink horisontal | Trykimp. gran (ubehandlet ud over imp.) | 43 | stk | 60.30 kr |  | 0 kr |  |  | jemogfix.dk (https://www.jemogfix.dk/impraegneret-klinkbeklaedning-gran-25-x-125-x-3600-mm/) | Billigste klink. Grøn-grålig fra start; kan males sort senere (+~450 kr)
Klinkbeklædning sortmalet gran 25×125×4200 (6-pak) | Klink horisontal | Gran, færdig sortmalet vandbaseret RAL 9005 | 6 | pak | 497.70 kr |  | 0 kr |  | 393.30 kr | jemogfix.dk (https://www.jemogfix.dk/klinkbeklaedning-sortmalet/4115/9023155/) | Klar til at montere. Klassisk skur/sommerhus-look. 6 stk pr. pak = 25,2 m linear
Aros 1-på-2 svensk gran 25×150 savskåret | 1-på-2 lodret (bob) | Savskåret svensk gran (FSC) | 16 | m² | 160.00 kr |  | 450 kr |  | 417.10 kr | arossavvaerk.dk (https://arossavvaerk.dk/vare/1-paa-2-beklaedning-svensk-gran/) | Tilbudspris 160 (normal 225). Rustic look. Behandling påkrævet før montage
Beklædning lodret sort 25×125×3000 (4-pak) | Klink lodret | Skandinavisk gran (FSC), færdig sortmalet vandbaseret | 13 | pak | 359.40 kr |  | 0 kr |  | 2079.30 kr | jemogfix.dk (https://www.jemogfix.dk/beklaedning-lodret-sort-25-x-125-x-3000-mm-4-pk/4115/9064083/) | Lodret klink-profil, færdig sort. 4 stk pr. pak = 12 m linear. Moderne lade-look
Høvlet forskalling fyr 22×100×3600 UBEHANDLET | 1-på-2 lodret (bob) | Fyr, høvlet, ubehandlet | 120 | stk | 35.82 kr |  | 600 kr |  | 2305.50 kr | jemogfix.dk (https://www.jemogfix.dk/hoevlet-forskalling-22-x-100-x-3600-mm/4230/9057349/) | Jemogfix advarer mod udendørs ubehandlet. Kræver Gori/Pinotex × 3 lag
Imprægneret høvlet fyr 25×125×3600 | 1-på-2 lodret (bob) | Trykimp. fyr, høvlet | 81 | stk | 63.90 kr |  | 0 kr |  | 2583.00 kr | jemogfix.dk (https://www.jemogfix.dk/impraegnerede-braedder-fyr-25-x-125-x-3600-mm/) | Udendørs-godkendt. Grøn-brun farve fra imp. Kan males (+~450 kr)
Læsevejledning
• Antal er beregnet for 16 m² netto vægareal (4 hus-vægge minus side-vindue + dør + kanindør).
• Behandl. kr = ekstra behandlingsomkostning (træolie/maling) der KRÆVES før montage. 0 hvis produktet er færdigbehandlet eller trykimp.
• Klink-produkter har færdig profil (overlapper indbygget). 1-på-2 (bob) bruger to lag rå brædder; kræver mere arbejde at montere.
• Mønster-farven matcher beklædnings-sheet i resten af workbook'en: blå = klink, grøn = bob, gul = lodret klink.
• TOTAL inkluderer IKKE: voliernet, vindpap, klemmelister, isolering, hjørnetrim (~2.000-2.500 kr fælles, se beklaedning_* sheets).

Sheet: fundament
Kategori | Vare | Antal | Enhed | Pris pr. enhed (DKK) | I alt (DKK) | Leverandør | Noter | Zone
Fundament | Stabilgrus 0-32 mm (hus) | 510 | kg | 0.55 |  | materialepladsen.dk (https://materialepladsen.dk/produkter/grus/Stabilgrus0-32mm) | Under hus-strips (~0,30 m³) | Hus
Fundament | Stabilgrus 0-32 mm (yard) | 510 | kg | 0.55 |  | materialepladsen.dk (https://materialepladsen.dk/produkter/grus/Stabilgrus0-32mm) | Under yard-strips (~0,30 m³) — 3-sidet 10 m perimeter | Yard
Fundament | Fundablok 50x20x15 cm (hus) | 80 | stk | 15.75 |  | jemogfix.dk (https://www.jemogfix.dk/fundablok-graa-15-x-20-x-50-cm/4176/9033558/) | 2000x3000 ring, 4 skifter halvstensforbandt — 80 + buffer | Hus
Fundament | Fundablok 50x20x15 cm (yard) | 80 | stk | 15.75 |  | jemogfix.dk (https://www.jemogfix.dk/fundablok-graa-15-x-20-x-50-cm/4176/9033558/) | 3-sidet ring (V4 = hus), 4 skifter halvstensforbandt — 80 + 6 buffer | Yard
Fundament | Kamstål Ø10 mm × 3 m (hus) | 16 | stk | 45.00 |  | jemogfix.dk (https://www.jemogfix.dk/kamstaal-8-mm-x-3-meter/4164/9042660/) | 2 bund (8 stk for 10 m) + 2 top (8 stk) — lodrette = genbrug af egne metalstænger | Hus
Fundament | Kamstål Ø10 mm × 3 m (yard) | 16 | stk | 45.00 |  | jemogfix.dk (https://www.jemogfix.dk/kamstaal-8-mm-x-3-meter/4164/9042660/) | 2 bund (8 stk for 10 m) + 2 top (8 stk) — lodrette = genbrug af egne metalstænger | Yard
Fundament | Cement 25 kg (hus) | 10 | stk | 75.00 |  | jemogfix.dk (https://www.jemogfix.dk/aalborg-portland-basis-aalborg-cement-25-kg/4170/9814769/) | 1:4 blanding, ~300 L beton | Hus
Fundament | Cement 25 kg (yard) | 10 | stk | 75.00 |  | jemogfix.dk (https://www.jemogfix.dk/aalborg-portland-basis-aalborg-cement-25-kg/4170/9814769/) | 1:4 blanding, ~300 L beton | Yard
Fundament | Støbemix 0-16 mm (hus) | 625 | kg | 0.66 |  | materialepladsen.dk (https://materialepladsen.dk/produkter/grus/Stoebemix0-16mm) | ca. 0,38 m³ | Hus
Fundament | Støbemix 0-16 mm (yard) | 625 | kg | 0.66 |  | materialepladsen.dk (https://materialepladsen.dk/produkter/grus/Stoebemix0-16mm) | ca. 0,38 m³ | Yard
Fundament | Ankerskrue M10 × 120 mm (hus) | 10 | stk | 14.95 |  | jemogfix.dk (https://www.jemogfix.dk/nkt-fasteners-gevindstang-m10-x-1000-mm/5116/9711834/) | est. — bundrem-fast: 2 på V1, 2 på V2, 3 på V3, 3 på V4 | Hus
Fundament | Ankerskrue M10 × 120 mm (yard) | 10 | stk | 14.95 |  | jemogfix.dk (https://www.jemogfix.dk/nkt-fasteners-gevindstang-m10-x-1000-mm/5116/9711834/) | est. — 4 på V1, 4 på V2, 2 på V5 | Yard
Fundament | M10 møtrikker + skiver (12-pak) | 2 | pk. | 28.95 |  | jemogfix.dk (https://www.jemogfix.dk/nkt-fasteners-moetrik-elforzinket-m10-12-stk/5118/9513052/) | Fastgør bundrem til ankerskrue ovenfra (1 pak pr. zone) | Fælles
Fundament | Armerings-bindetråd 1,4 mm (50 m rl.) | 1 | rl. | 39.95 |  | jemogfix.dk | Til at binde kamstål-overlap og lodrette stænger til vandret armering | Fælles
 |  |  |  | TOTAL
 |  |  |  | heraf Hus
 |  |  |  | heraf Yard
 |  |  |  | heraf Fælles

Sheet: konstruktion
Kategori | Vare | Antal | Enhed | Pris pr. enhed (DKK) | I alt (DKK) | Leverandør | Noter | Zone
Konstruktion | Murpap (DPC) | 1 | stk | 99.00 |  | jemogfix.dk (https://www.jemogfix.dk/phoenix-murpap-11-cm-x-20-meter/4210/9036209/) | 11 cm × 20 m — sokkel-isolering, hele perimeter + tværvæg | Fælles
Konstruktion | Bundrem 45×95×3600 PT NTR-AB | 2 | stk | 71.10 |  | jemogfix.dk (https://www.jemogfix.dk/impraegneret-reglar-45-x-95-x-3600-mm/4310/9057360/) | V1 + V2 lange stykker — straddler hl ved splejs | Fælles
Konstruktion | Bundrem 45×95×2400 PT NTR-AB (hus) | 2 | stk | 47.40 |  | jemogfix.dk (https://www.jemogfix.dk/impraegneret-reglar-45-x-95-x-2400-mm/4310/9057358/) | V3 + V4 bundrem | Hus
Konstruktion | Bundrem 45×95×2400 PT NTR-AB (yard) | 3 | stk | 47.40 |  | jemogfix.dk (https://www.jemogfix.dk/impraegneret-reglar-45-x-95-x-2400-mm/4310/9057358/) | V1[2] + V2[2] + V5 bundrem | Yard
Konstruktion | Toprem 47×100×3600 C24 gran | 2 | stk | 63.90 |  | jemogfix.dk (https://www.jemogfix.dk/reglar-47-x-100-x-3600-mm/4110/9057297/) | V1 + V2 lange stykker — straddler hl | Fælles
Konstruktion | Toprem 47×100×3600 C24 gran (yard) | 2 | stk | 63.90 |  | jemogfix.dk (https://www.jemogfix.dk/reglar-47-x-100-x-3600-mm/4110/9057297/) | V1[2] + V2[2] yard-segment toprem | Yard
Konstruktion | Reglar 47×100×2400 C24 gran (hus) | 22 | stk | 42.60 |  | jemogfix.dk (https://www.jemogfix.dk/reglar-47-x-100-x-2400-mm/4110/9057295/) | Studs V1[0..hl]+V2[0..hl]+V3+V4 + skrå toprem V3+V4 + headers/cripples | Hus
Konstruktion | Reglar 47×100×2400 C24 gran (yard) | 20 | stk | 42.60 |  | jemogfix.dk (https://www.jemogfix.dk/reglar-47-x-100-x-2400-mm/4110/9057295/) | Studs V1[hl..ll]+V2[hl..ll]+V5 + skrå toprem V5 + yard-dør jamber | Yard
 |  |  |  | TOTAL
 |  |  |  | heraf Hus
 |  |  |  | heraf Yard
 |  |  |  | heraf Fælles

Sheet: tagkonstruktion_tagpap
Kategori | Vare | Antal | Enhed | Pris pr. enhed (DKK) | I alt (DKK) | Leverandør | Noter | Zone
Træværk | Spær 47×100×3000 C24 gran (hus) | 4 | stk | 53.25 |  | jemogfix.dk (https://www.jemogfix.dk/reglar-47-x-100-x-3000-mm/4110/9057296/) | X=-220, 0, 600, 1200 (incl. vindskede V) | Hus
Træværk | Spær 47×100×3000 C24 gran (yard) | 9 | stk | 53.25 |  | jemogfix.dk (https://www.jemogfix.dk/reglar-47-x-100-x-3000-mm/4110/9057296/) | X=1800..5400 + V5 gable + vindskede H | Yard
Træværk | OSB-3 TG4 18 mm 2397×600 mm (hus) | 5 | stk | 129.00 |  | jemogfix.dk (https://www.jemogfix.dk/osb-3-plade-tg4-18-mm-2397-x-600-mm/4138/9050213/) | Plade 1 i hver række — dækker [-220..2177] | Hus
Træværk | OSB-3 TG4 18 mm 2397×600 mm (yard) | 10 | stk | 129.00 |  | jemogfix.dk (https://www.jemogfix.dk/osb-3-plade-tg4-18-mm-2397-x-600-mm/4138/9050213/) | Plade 2+3 i hver række — dækker [2177..6220] | Yard
Træværk | Sternbræt imp. 21×120×3600 gran (hus) | 2 | stk | 92.70 |  | jemogfix.dk (https://www.jemogfix.dk/impraegneret-stern-mellem-21-x-120-x-3600-mm/4321/9057378/) | Venstre side + del af front/bag (~6,4 m) | Hus
Træværk | Sternbræt imp. 21×120×3600 gran (yard) | 4 | stk | 92.70 |  | jemogfix.dk (https://www.jemogfix.dk/impraegneret-stern-mellem-21-x-120-x-3600-mm/4321/9057378/) | Højre side + resten af front/bag (~12,4 m) | Yard
Tagdækning | Phoenix Selvbyggerpap 1×5 m (hus) | 2 | stk | 579.00 |  | jemogfix.dk (https://www.jemogfix.dk/phoenix-selvbyggerpap-1-x-5-meter/4210/9021085/) | ~5 m² hus + spild | Hus
Tagdækning | Phoenix Selvbyggerpap 1×5 m (yard) | 4 | stk | 579.00 |  | jemogfix.dk (https://www.jemogfix.dk/phoenix-selvbyggerpap-1-x-5-meter/4210/9021085/) | ~14 m² yard + spild | Yard
Tagdækning | Phoenix klæbeasfalt 310 ml (hus) | 1 | stk | 69.95 |  | jemogfix.dk (https://www.jemogfix.dk/phoenix-klaebeasfalt-310-ml/4211/9014391/) |  | Hus
Tagdækning | Phoenix klæbeasfalt 310 ml (yard) | 2 | stk | 69.95 |  | jemogfix.dk (https://www.jemogfix.dk/phoenix-klaebeasfalt-310-ml/4211/9014391/) |  | Yard
Tagdækning | Phoenix murpap til tagfod 15 cm × 20 m | 1 | stk | 149.00 |  | jemogfix.dk (https://www.jemogfix.dk/phoenix-murpap-15-cm-x-20-meter/4210/9060998/) | Én rulle dækker begge zoner | Fælles
Aluinddækning | Alu tagfod sort 55×80×1000 mm (hus) | 2 | stk | 39.75 |  | jemogfix.dk (https://www.jemogfix.dk/tagfod-sort-aluminium-55-x-80-x-1000-mm/4210/9058507/) | Front+bag hus-segment + ende-trim | Hus
Aluinddækning | Alu tagfod sort 55×80×1000 mm (yard) | 5 | stk | 39.75 |  | jemogfix.dk (https://www.jemogfix.dk/tagfod-sort-aluminium-55-x-80-x-1000-mm/4210/9058507/) | Front+bag yard-segment + ende-trim | Yard
Aluinddækning | Alu sternkapsel sort 35×25×1000 mm (hus) | 3 | stk | 59.95 |  | jemogfix.dk (https://www.jemogfix.dk/sternkapsel-lige-sort-35-x-25-mm-x-100-cm/4210/9062741/) | Venstre side + front+bag hus | Hus
Aluinddækning | Alu sternkapsel sort 35×25×1000 mm (yard) | 10 | stk | 59.95 |  | jemogfix.dk (https://www.jemogfix.dk/sternkapsel-lige-sort-35-x-25-mm-x-100-cm/4210/9062741/) | Højre side + front+bag yard | Yard
Beslag | Paslode vinkelbeslag 90×90×40 (20-pak) (hus) | 1 | pak |  |  | wood-online.dk (https://wood-online.dk/shop/paslode-vinkelbeslag-542p.html) | TBD pris — ~14 stk på hus-spær | Hus
Beslag | Paslode vinkelbeslag 90×90×40 (20-pak) (yard) | 2 | pak |  |  | wood-online.dk (https://wood-online.dk/shop/paslode-vinkelbeslag-542p.html) | TBD pris — ~34 stk på yard-spær | Yard
Beslag | OSB/spær-skruer 5×80 mm | 250 | stk |  |  | jemogfix.dk | TBD pris — én pakke dækker begge | Fælles
Beslag | Rustfri tagskruer m. EPDM-pakning |  | stk |  |  | jemogfix.dk | TBD antal + pris | Fælles
Beslag | Galvaniseret tagpapsøm 2,6×25 mm (100-pak) | 1 | pk. | 69.95 |  | jemogfix.dk (https://www.jemogfix.dk/alusoem-2-6-x-25-mm-100-stk/4210/9038151/) | Alusøm — én pakke dækker begge | Fælles
 |  |  |  | TOTAL
 |  |  |  | heraf Hus
 |  |  |  | heraf Yard
 |  |  |  | heraf Fælles

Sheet: tagkonstruktion_eternit_b7
Kategori | Vare | Antal | Enhed | Pris pr. enhed (DKK) | I alt (DKK) | Leverandør | Noter | Zone
Træværk | Spær 47×100×3000 C24 gran (hus) | 4 | stk | 85.00 |  | Stark (https://www.jemogfix.dk/reglar-47-x-100-x-3000-mm/4110/9057296/) | est. — X<=1200 (incl. vindskede V) | Hus
Træværk | Spær 47×100×3000 C24 gran (yard) | 9 | stk | 85.00 |  | Stark (https://www.jemogfix.dk/reglar-47-x-100-x-3000-mm/4110/9057296/) | est. — X>=1800 | Yard
Træværk | C18 taglægte 38×73×4200 mm (hus) | 6 | stk | 52.50 |  | 10-4.dk (https://www.10-4.dk/varer/byggematerialer/trae/laegter/38x73mm-taglaegte-c18-1731038073) | 6 batten-rækker × 1 stk hus-segment | Hus
Træværk | C18 taglægte 38×73×4200 mm (yard) | 12 | stk | 52.50 |  | 10-4.dk (https://www.10-4.dk/varer/byggematerialer/trae/laegter/38x73mm-taglaegte-c18-1731038073) | 6 batten-rækker × 2 stk yard-segment | Yard
Træværk | Imp. sternbræt 25×125×3600 gran (hus) | 2 | stk | 82.60 |  | xl-byg.dk (https://www.xl-byg.dk/produkt/xl-byg-ru-sternbraet-over-trykimpraegneret-25-x-125-x-3600-mm-1143025122-0360) | Venstre side + del af front/bag (~6,4 m) | Hus
Træværk | Imp. sternbræt 25×125×3600 gran (yard) | 4 | stk | 82.60 |  | xl-byg.dk (https://www.xl-byg.dk/produkt/xl-byg-ru-sternbraet-over-trykimpraegneret-25-x-125-x-3600-mm-1143025122-0360) | Højre side + resten af front/bag (~12,4 m) | Yard
Tagdækning | Swisspearl B7 bølgeplade FK 1100×570 sortblå (hus) | 15 | stk | 95.00 |  | bygxtra.dk (https://www.bygxtra.dk/produkter/swisspearl-boelgeplade-b7-fk-i-sortblaa-1100x570-mm-1617012) | 2 plader × 7 rækker + 5 % spild | Hus
Tagdækning | Swisspearl B7 bølgeplade FK 1100×570 sortblå (yard) | 37 | stk | 95.00 |  | bygxtra.dk (https://www.bygxtra.dk/produkter/swisspearl-boelgeplade-b7-fk-i-sortblaa-1100x570-mm-1617012) | 5 plader × 7 rækker + 5 % spild | Yard
Tagdækning | Swisspearl 100 Tagskrue 6×100 (100-pak) (hus) | 1 | pak | 425.00 |  | davidsen.dk (https://www.davidsen.dk/swisspearl-100-tagskrue-m-taetningsskive-6x100-mm-graa-100-stk-c-id525046-p-51601506116) | 2 pr. plade × 14 + spild | Hus
Tagdækning | Swisspearl 100 Tagskrue 6×100 (100-pak) (yard) | 2 | pak | 425.00 |  | davidsen.dk (https://www.davidsen.dk/swisspearl-100-tagskrue-m-taetningsskive-6x100-mm-graa-100-stk-c-id525046-p-51601506116) | 2 pr. plade × 35 + spild | Yard
Tagdækning | Swisspearl PVC skumstrimmel 4,5 mm | 1 | rl. |  |  | Cembrit | TBD pris — overlap-tætning, én rulle deler | Fælles
Beslag | Paslode vinkelbeslag 90×90×40 (20-pak) (hus) | 1 | pak |  |  | wood-online.dk (https://wood-online.dk/shop/paslode-vinkelbeslag-542p.html) | TBD pris — ~14 stk på hus-spær | Hus
Beslag | Paslode vinkelbeslag 90×90×40 (20-pak) (yard) | 2 | pak |  |  | wood-online.dk (https://wood-online.dk/shop/paslode-vinkelbeslag-542p.html) | TBD pris — ~34 stk på yard-spær | Yard
Beslag | Lægtesøm varmforzinket 2,8×60 |  | stk |  |  | jemogfix.dk | TBD antal + pris | Fælles
 |  |  |  | TOTAL
 |  |  |  | heraf Hus
 |  |  |  | heraf Yard
 |  |  |  | heraf Fælles

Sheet: beklaedning_klink
Kategori | Vare | Antal | Enhed | Pris pr. enhed (DKK) | I alt (DKK) | Leverandør | Noter | Zone
Voliere | Voliernet welded 13×13 mm | 2 | stk | 1350.00 |  | (ukendt) | 1×10 m + 1×25 m — yard front+back+right | Yard
Voliere | Klamper til voliernet |  | stk |  |  | jemogfix.dk | TBD antal + pris | Yard
Beklædning | Klinkbeklædning sortmalet gran 25×125×4200 (pak) | 6 | pak | 497.70 |  | jemogfix.dk (https://www.jemogfix.dk/klinkbeklaedning-sortmalet/4115/9023155/) | Frøslev klink; 4 hus-vægge | Hus
Beklædning | Vindpap (housewrap) | 1 | rl. | 299.00 |  | jemogfix.dk (https://www.jemogfix.dk/phoenix-isoleringspap-rf-650-1-0-x-20-meter/4210/9358237/) | 20 m² pr. rulle; behov ~17,5 m² på 4 hus-vægge | Hus
Beklædning | Klemmelister 25×50×4200 mm | 10 | stk | 28.35 |  | jemogfix.dk (https://www.jemogfix.dk/impraegneret-forskalling-fyr-25-x-50-x-4200-mm/4310/9063674/) | Lodrette afstandslister c/c 600 på hus-vægge | Hus
Beklædning | Hjørnetrim 45×45×2400 mm | 4 | stk | 29.25 |  | jemogfix.dk (https://www.jemogfix.dk/reglar-47-x-50-x-3000-mm/4110/9052623/) | 4 udvendige hus-hjørner | Hus
Beklædning | Isolering mineraluld 95 mm | 20 | m² | 29.61 |  | jemogfix.dk (https://www.jemogfix.dk/glasuld-isover-basic-ruller-95-mm/4180/9039070/) | I hus-stud-rum (4 vægge) | Hus
 |  |  |  | TOTAL
 |  |  |  | heraf Hus
 |  |  |  | heraf Yard
 |  |  |  | heraf Fælles

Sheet: beklaedning_board_on_board
Kategori | Vare | Antal | Enhed | Pris pr. enhed (DKK) | I alt (DKK) | Leverandør | Noter | Zone
Voliere | Voliernet welded 13×13 mm | 2 | stk | 1350.00 |  | (ukendt) | 1×10 m + 1×25 m — yard front+back+right | Yard
Voliere | Klamper til voliernet |  | stk |  |  | jemogfix.dk | TBD antal + pris | Yard
Beklædning | 1-på-2 svensk gran 25×150 savskåret | 16 | m² | 160.00 |  | arossavvaerk.dk (https://arossavvaerk.dk/vare/1-paa-2-beklaedning-svensk-gran/) | Aros tilbudspris; normal 225 kr/m² — hus-vægge | Hus
Beklædning | Træolie/maling til naturligt træ | 3 | L |  |  | (vælg selv) | TBD — Gori/Cuprinol/Pinotex; klink er sortmalet | Hus
Beklædning | Vindpap (housewrap) | 1 | rl. | 299.00 |  | jemogfix.dk (https://www.jemogfix.dk/phoenix-isoleringspap-rf-650-1-0-x-20-meter/4210/9358237/) | Samme som klink — hus-vægge | Hus
Beklædning | Klemmelister 25×50×4200 mm | 10 | stk | 28.35 |  | jemogfix.dk (https://www.jemogfix.dk/impraegneret-forskalling-fyr-25-x-50-x-4200-mm/4310/9063674/) | Vandrette afstandslister c/c 600 på hus-vægge | Hus
Beklædning | Hjørnetrim 70×70×2400 trykimp. | 4 | stk |  |  | jemogfix.dk | TBD — større end klink (bob stickout 50 mm) | Hus
Beklædning | Isolering mineraluld 95 mm | 20 | m² | 29.61 |  | jemogfix.dk (https://www.jemogfix.dk/glasuld-isover-basic-ruller-95-mm/4180/9039070/) | Samme som klink — hus-stud-rum | Hus
Beklædning | Rustfri A4 facadeskruer 4×60 |  | pk. |  |  | jemogfix.dk | TBD antal + pris — flere end klink (2 lag) | Hus
 |  |  |  | TOTAL
 |  |  |  | heraf Hus
 |  |  |  | heraf Yard
 |  |  |  | heraf Fælles

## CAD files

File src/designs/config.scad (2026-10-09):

// Rabbit-house constants. All dimensions in mm.
//
// Layout (L-shape — house front sticks out 1000 mm past yard front):
//   X 0..2000    = house  (gable roof, skifer)            Y 0..3000
//   X 2000..6000 = yard   (mesh-top run)                  Y 1000..3000
//   Y 3000       = shared back wall (continuous X=0..6000)
//   Y 0..1000    = house-only zone (yard does not extend here)
//
// House and yard have DIFFERENT Y-depths:
//   RH_HOUSE_DEPTH = 3000 (Y=0..3000)
//   RH_YARD_DEPTH  = 2000 (Y=1000..3000) — offset by RH_YARD_Y_OFFSET=1000

RH_LENGTH        = 6000;
RH_HOUSE_DEPTH   = 3000;             // hus Y-dybde
RH_YARD_DEPTH    = 2000;             // yard Y-dybde
RH_YARD_Y_OFFSET = 1000;             // yard front-væg's Y-koordinat
RH_BASE_H        = 120;
RH_WALL_T        = 100;
RH_HOUSE_LEN     = 2000;
RH_RUN_LEN       = RH_LENGTH - RH_HOUSE_LEN;  // 4000

// House wall height from sokkel-top to top-plate top. All 4 walls share
// this single eave — the gable rafters in roof_gable.scad sit on top and
// create the pitch. Stack: DPC 2 + bundrem 45 + 2,0m C24 stud + toprem 45
// = 2092 mm, so a stud is exactly 2000 mm. RH_EH_BACK kept equal to
// RH_EH_FRONT so the legacy mono-pitch helpers (yard still uses them via
// its own RH_YARD_EH_*) degenerate to flat for the house.
//
// Walls lowered to 2000 mm studs: the 2000 mm doors (RH_*_DOOR_H) now equal
// the stud height, so each door header coincides with the top plate (no
// cripple course above the door). Windows keep a shorter cripple-over-header.
RH_EH_FRONT     = 2092;
RH_EH_BACK      = 2092;

// Yard walls are shorter than the house so the run reads as a separate
// (lower) cage against V4. With the mesh-top cover the yard no longer
// sheds water — front and back share a single 2100 eave so V2 and V5
// walls run flat instead of sloping. Front 2100 keeps room for a 1950
// rough opening yard door (~187 cm leaf height after threshold and top
// frame).
RH_YARD_EH_FRONT = 2100;
RH_YARD_EH_BACK  = 2100;

RH_OH_FRONT     = 220;
RH_OH_BACK      = 180;
RH_OH_SIDE      = 220;
RH_ROOF_THICK   = 80;

// Standard Danish timber sizes.
//   95x180 glulam   — yard top beams sloping under roof
//   45x195 reglar   — interior collar tie
//   70x70 KOMPAKT   — mesh-wall stiles
//   45x95 reglar    — yard corner posts (flush at X=ll), sill plates flat
// RH_POST_W is the shared 95 mm "wide" dimension used by sills, beams, and
// the corner reglar's wide axis — single constant keeps wall envelope sizes
// consistent.
RH_POST_W       = 95;
RH_BEAM_H       = 180;
RH_COLLAR_TIE_W = 45;
RH_COLLAR_TIE_H = 195;
RH_SILL_H       = 45;

// Internal door in the partition wall (X=RH_HOUSE_LEN, faces +X into yard).
// Rough opening for a standard 80x200 cm internal door.
// Y=1500 centres door in partition zone (yard only meets V4 at Y=500..3000).
// Door spans Y=1500..2370.
// Rough opening for a 80x200 internal door (leaf 2000, opening +50).
RH_HOUSE_DOOR_W = 870;
RH_HOUSE_DOOR_H = 2000;
RH_HOUSE_DOOR_Y = 1500;

// Rabbit pet door in the partition (faces +X into yard).
// Y=2700 clears the human door (Y=1500..2370) by 330 mm; pet door spans
// Y=2700..2950, ending 50 mm before the back wall at Y=3000.
RH_PET_DOOR_W   = 250;
RH_PET_DOOR_H   = 300;
RH_PET_DOOR_Y   = 2700;

// Yard outdoor door on the front (Y=0, opens outward).
// Rough opening = full stud height (WALL_TOP_HIGH - PLATE_HEIGHT - STUD_BOTTOM_Z
// = 2008). Top plate doubles as the header — no separate header + cripple
// stack above the opening, same pattern as the V4 partition door. Leaf is
// 2008 − 30 threshold − 50 top frame = 1928 mm.
// X centred on the 4 m front wall: (hl + ll - W) / 2 = 3465.
RH_YARD_DOOR_W  = 1070;
RH_YARD_DOOR_H  = 2008;
RH_YARD_DOOR_X  = 3465;

// Insulated nest box (against the back wall, inside the house).
RH_NEST_X       = 200;
RH_NEST_Y       = 1500;
RH_NEST_W       = 800;
RH_NEST_D       = 900;
RH_NEST_H       = 600;

// Side window on the left exterior wall V3 (X=0, faces -X) — den frie
// langside; løbegården ligger på V4-siden. To-rammet vindue (to lige høje
// rammer over hinanden), hvid karm.
//
// Målt af byggefoto (klink-skifter à 100 mm som målestok), IKKE opmålt:
//   lysning ca. 860 bred × 1000 høj, underkant 1000 mm over sokkeltop
//   (= 955 over gulv), overkant tæt under topremmen.
// Med Z=955 og H=1000 lander overliggeren (45) præcis under toprem-
// underkanten (kote 2167) — ingen cripple over vinduet.
// TODO: ret W/H/Y til vinduets faktiske karmmål + placering når de er
// opmålt (læg montagefuge til karmmålet ligesom ved hoveddøren).
RH_SIDE_WIN_W   = 860;
RH_SIDE_WIN_H   = 1000;
RH_SIDE_WIN_Y   = (RH_HOUSE_DEPTH - RH_SIDE_WIN_W) / 2;   // = 1070, centreret
RH_SIDE_WIN_Z   = 955;                                    // over gulv (RH_FLOOR_TOP)

// Front entry door on V1 (Y=0, faces -Y). Indkøbt dør, udvendige karmmål
// 948 × 2050 mm (B × H).
//
// Lysning (rough opening) = karm + 10 mm montagefuge i hver side.
// Bundremmen er skåret væk under døren, så karmen står direkte på sokkel-
// /gulvniveau (Z = RH_BASE_H = 120) — samme kote som gulvbrættets overside.
// Toprem = overligger (underkant Z = 2167), så den frie lysningshøjde er
// RH_EH_FRONT − RH_SILL_H = 2047 mm.
//
// NB: karmen er 2050 høj, lysningen 2047 — de 3 mm høvles af topremmens
// underside ved montage (eller opmål den byggede væg: er studs'ene i
// virkeligheden 2003+ mm, forsvinder differencen).
RH_FRONT_DOOR_KARM_W = 948;                        // udvendigt karmmål, bredde
RH_FRONT_DOOR_KARM_H = 2050;                       // udvendigt karmmål, højde
RH_FRONT_DOOR_FUGE   = 10;                         // montagefuge pr. side

RH_FRONT_DOOR_W = RH_FRONT_DOOR_KARM_W + 2 * RH_FRONT_DOOR_FUGE;  // = 968
RH_FRONT_DOOR_H = RH_EH_FRONT - RH_SILL_H;                        // = 2047
RH_FRONT_DOOR_Z = RH_BASE_H;                       // = 120, karmens underkant
RH_FRONT_DOOR_X = (RH_HOUSE_LEN - RH_FRONT_DOOR_W) / 2;           // = 516

// Rudeudskæring i dørbladet — rombe ("harlekin") i bladets øverste tredjedel,
// centreret i bredden, med en geringsskåret foring af lyst træ hele vejen
// rundt. Hullet står ÅBENT som bygget (ingen rude i endnu) — sæt
// RH_FRONT_DOOR_LIGHT_GLAZED = true når der isættes glas.
// Mål skaleret af byggefoto, ikke opmålt.
RH_FRONT_DOOR_LIGHT_W      = 240;    // hullets bredde (vandret diagonal)
RH_FRONT_DOOR_LIGHT_H      = 280;    // hullets højde (lodret diagonal)
RH_FRONT_DOOR_LIGHT_Z      = 1530;   // hullets centerkote over karmbund
RH_FRONT_DOOR_LIGHT_LINING = 45;     // foringens bredde uden om hullet
RH_FRONT_DOOR_LIGHT_GLAZED = false;

// V1 har INGEN vinduer — facaden er blank beklædning på begge sider af
// døren, og eneste glas i gavlen er ruden i dørbladet.

// Yard mesh — fine welded wire (predator-proof per REQ-008).
// 13 mm aperture x 1 mm wire (gauge 19 GAW).
RH_MESH_SPACING = 13;
RH_MESH_BAR     = 1;
RH_MESH_FRAME   = 40;
RH_MESH_DEPTH   = 20;
RH_MESH = mesh_spec(spacing = RH_MESH_SPACING, bar   = RH_MESH_BAR,
                    frame   = RH_MESH_FRAME,   depth = RH_MESH_DEPTH);

// Klink cladding profile: 25x125 mm spruce/larch boards, 25 mm overlap,
// step 100 mm. Standard Stark/Bauhaus stock in 4200 mm lengths. Overrides
// the library's DEFAULT_CLAD (24x150 with 40 mm overlap).
RH_CLAD = clad_spec(board_h=125, overlap=25, thick=25, lip=20);

// Board-on-board (1-på-2) profile: 25x150 mm savskåret gran, 25 mm overlap
// per side, 100 mm back-board gap → 250 mm c/c pitch, 50 mm total stickout.
// Standard Aros Savværk / Frøslev / Silvan stock (sold as raw boards).
RH_CLAD_BOB = bob_spec(board_w=150, board_t=25, overlap=25, back_gap=100);

// Vertical wood stiles along yard mesh walls (~1 m c/c).
RH_STILE_W       = 70;
RH_STILE_SPACING = 1000;

// Horizontal mid-rail across yard mesh panels, dividing each into stacked
// ~1 m sections. The yard door's internal mid-rail uses the same Z so the
// line is continuous across the whole front wall.
RH_MID_RAIL_Z_OFFSET = 1000;
RH_MID_RAIL_H        = 40;

// Rafter constants.
RH_RAFTER_W   = 45;
RH_RAFTER_H   = 95;
RH_RAFTER_C2C = 600;

// Fascia board thickness (25x125 pressure-treated spruce, all four eaves).
RH_FASCIA_T   = 25;
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

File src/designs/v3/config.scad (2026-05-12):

// House-yard v3 — constants.
//
// Layout (mm):
//   X 0..1500    = solid mono-pitch house (rabbit shelter + insulated nest
//                  box). Human entry is from inside the yard.
//   X 1500..6000 = mesh-walled yard. Human entry via a mesh door on the
//                  front. (Foundation: continuous fundablok ring around
//                  whole 6×2.5 m perimeter; see Phase 1 spec.)
//   Y 0          = front (open garden face / human entry / high eave)
//   Y 2500       = back (prevailing-wind side / low eave / gutter)
//
// Roof: ONE continuous mono-pitch slab spans the entire 6 m × 2.5 m footprint,
// sloping front-to-back. Wall-face heights are eh_front=2600, eh_back=2200
// (drop 400 over 2500 = 9.09°, 16 % fald). The roof primitive interprets
// `eave_h` and `drop` across the FULL OVERHANG SPAN, so v3 derives a
// corrected origin Z and total drop (see V3_ROOF_*) so the wall tops align
// with the roof underside at the wall faces, not just at the overhang tips.

V3_LENGTH       = 6000;
V3_WIDTH        = 2500;
V3_BASE_H       = 120;
V3_WALL_T       = 100;
V3_HOUSE_LEN    = 1500;
V3_RUN_LEN      = 4500;

// Wall heights, measured from sokkel-top (Z=V3_BASE_H) to roof underside
// at the wall face. EH_FRONT > EH_BACK gives a mono-pitch slope front→back.
// Drop 200 over 2500 = 4,6° (8 % fald). Tagpap kræver minimum 2,5 cm/m
// = 2,5 % = 1,4° — vores 8 % er rigeligt. Stål og eternit kræver mere
// hældning og virker IKKE med disse højder.
//
// Højder valgt så STANDARD-DØRE passer:
//   V1 (front, EH_FRONT=2400) rummer 95×205 udhusdør (rough opening 1070×2120)
//   V5 (partition, EH_BACK=2200) rummer 80×200 indvendig dør (870×2050)
V3_EH_FRONT     = 2400;
V3_EH_BACK      = 2200;

// Roof overhangs
V3_OH_FRONT     = 220;
V3_OH_BACK      = 180;
V3_OH_SIDE      = 220;
V3_ROOF_THICK   = 80;

// Human door in the partition (X=V3_HOUSE_LEN, faces +X into the yard).
// Rough opening for STANDARD 80×200 cm indvendig dør (= blade 800×2000 +
// karm 50mm hver side + 15mm tolerance på top).
V3_HOUSE_DOOR_W = 870;
V3_HOUSE_DOOR_H = 2050;
V3_HOUSE_DOOR_Y = 200;       // along Y on the partition

// Rabbit pet door (partition at X=V3_HOUSE_LEN, faces +X into yard).
V3_PET_DOOR_W   = 250;
V3_PET_DOOR_H   = 300;
V3_PET_DOOR_Y   = 1500;

// Yard udhusdør (front face Y=0, opens outward to garden).
// Rough opening for STANDARD 95×205 cm udhusdør (= blade 948×2050 +
// karm 60mm hver side + 15mm tolerance på top).
V3_YARD_DOOR_W  = 1070;
V3_YARD_DOOR_H  = 2120;
V3_YARD_DOOR_X  = 3000;      // X along front (left edge of the door)

// Insulated nest box (against back wall, in main house space). With house
// shortened to 1500 mm, X anchor moved from 1100 → 200 so the 800-wide box
// (X=200..1000) fits comfortably inside the partition wall at X=1500.
V3_NEST_X       = 200;
V3_NEST_Y       = 1500;
V3_NEST_W       = 800;
V3_NEST_D       = 900;
V3_NEST_H       = 600;

// Side window on left exterior wall (X=0, faces -X).
// Centreret horizontalt (V3_SIDE_WIN_Y=900 → opening Y=900..1600 i wall Y=95..2405).
// V3_SIDE_WIN_Z=1100 sætter vinduet ved adult-øjenhøjde (vinduebund ~1,1m over gulv).
V3_SIDE_WIN_W   = 700;
V3_SIDE_WIN_H   = 600;
V3_SIDE_WIN_Y   = 900;
V3_SIDE_WIN_Z   = 1100;

// Standard Danish timber sizes used by the yard structure.
//   95×180 limtræ      — yard top beams, sloping under roof (V3_BEAM_H)
//   45×195 reglar      — interior collar tie (V3_COLLAR_TIE_H)
//   70×70 KOMPAKT      — mesh-wall stiles (V3_STILE_W)
//   45×95 reglar       — right-end corner reglar (cross-section 45×95,
//                        outer face flush at X=ll); replaced 95×95 stolper
//                        once the fundablok ring carried the load line
//   45×95 reglar flat  — yard sill plate, 95 wide × 45 tall (V3_SILL_H)
// V3_POST_W is the SHARED 95 mm "wide" dimension used by sills, beams,
// and the corner reglar's wide axis — kept as a single constant so wall
// envelope dimensions stay consistent.
V3_POST_W       = 95;
V3_BEAM_H       = 180;
V3_COLLAR_TIE_W = 45;        // 45×195 reglar laid on edge
V3_COLLAR_TIE_H = 195;
V3_SILL_H       = 45;

// Mesh spec for the yard — fine welded wire (predator-proof per REQ-008).
//   13 mm aperture × 1 mm wire (≈ gauge 19 GAW)
V3_MESH_SPACING = 13;
V3_MESH_BAR     = 1;
V3_MESH_FRAME   = 40;
V3_MESH_DEPTH   = 20;

// Vertical wood stiles every ~1 m along yard mesh walls.
V3_STILE_W      = 70;
V3_STILE_SPACING = 1000;

// Horizontal mid-rail across yard mesh panels — divides each panel into
// stacked ~1 m × 1 m mesh sections for a fence-panel look. The yard door's
// internal mid-rail uses the same Z so the rail line is continuous across
// the whole front wall.
V3_MID_RAIL_Z_OFFSET = 1000;       // above sill top
V3_MID_RAIL_H        = 40;         // matches mesh frame thickness

// Spær (rafter) constants. Shared globally so config can shift the roof
// z-frame up by SPAER_H and place the cover correctly above.
V3_SPAER_W   = 45;
V3_SPAER_H   = 95;
V3_SPAER_C2C = 600;

// Sternbræt-tykkelse (25×125 imprægneret gran). Bruges af alle tag-varianter
// (tagpap-, eternit-) til at placere stern + sternkapsel/vindskede UDVENDIGT
// på spær-endefladerne. Lever i config så både tagkonstruktion_faelles.scad,
// tagkonstruktion_tagpap.scad og tagkonstruktion_eternit.scad ser samme værdi.
V3_STERN_T   = 25;

// Roof geometry helpers. v3_roof_oz / v3_roof_oz_for now return the z of
// the SPÆR TOP (= cover bottom) at the front-eave corner — i.e., they sit
// SPAER_H above the wall-plate top. This means:
//   • spær bottom @ y = wall-plate top         (spær sits on toprem)
//   • spær top    @ y = v3_roof_under_for(y)   (cover sits on spær top)
// Wall-plate top heights are still V3_BASE_H + V3_EH_FRONT (front, HØJ)
// and V3_BASE_H + V3_EH_BACK (back, LOW) — set in konstruktions-skelet.
function v3_span_total() = V3_OH_FRONT + V3_WIDTH + V3_OH_BACK;
function v3_total_drop() =
    (V3_EH_FRONT - V3_EH_BACK) * v3_span_total() / V3_WIDTH;
function v3_roof_oz() =
    V3_BASE_H + V3_EH_FRONT + V3_SPAER_H +
    V3_OH_FRONT * v3_total_drop() / v3_span_total();
// Roof underside z (= spær top z) at any Y. Y=0 is front wall face.
function v3_roof_under(y) =
    v3_roof_oz() - (V3_OH_FRONT + y) * v3_total_drop() / v3_span_total();

// Roof slope per cover type. Eternit B7 normally needs ≥10° (extended
// overlap) or ≥14° (standard). v3's 4,6° is OK for tagpap_osb but for
// eternit_b7 we'd need to lower eh_back further (which also requires
// konstruktions-skelet to re-fit the doors — see todo "Senere").
function v3_eh_back_for(cover) =
      cover == "eternit_10" ? 2160
    : cover == "eternit_14" ? 1976
    : V3_EH_BACK;

// Cover-aware versions. Same SPAER_H lift as the default helpers above.
function v3_total_drop_for(eh_back) =
    (V3_EH_FRONT - eh_back) * v3_span_total() / V3_WIDTH;
function v3_roof_oz_for(eh_back) =
    V3_BASE_H + V3_EH_FRONT + V3_SPAER_H +
    V3_OH_FRONT * v3_total_drop_for(eh_back) / v3_span_total();
function v3_roof_under_for(eh_back, y) =
    v3_roof_oz_for(eh_back) - (V3_OH_FRONT + y) * v3_total_drop_for(eh_back) / v3_span_total();

// DPC tape (murpap) tykkelse mellem sokkel-ring og bundrem. Bundrem bærer
// alt træ-skelettet og sidder PÅ TOP af DPC-båndet, ikke direkte på sokkel
// — derfor lægger gulv-niveau 2 mm højere end ring-toppen.
V3_DPC_T = 2;

// Floor finish (krydsfiner top) — flush med bundrem-toppen så døre lander
// ved gulv-niveau. Bundrem sidder ovenpå DPC-båndet på sokkel-ringen, så
// floor_top = ring_top + DPC + bundrem-tykkelse.
V3_FLOOR_TOP = V3_BASE_H + V3_DPC_T + V3_SILL_H;   // = 120 + 2 + 45 = 167

// Top of the yard sill plate — yard-bundremmen sidder også på DPC-båndet,
// så toppen er identisk med V3_FLOOR_TOP.
V3_YARD_SILL_TOP = V3_FLOOR_TOP;  // = 167

// Beklædning lag-stack tykkelser. Bruges af beklaedning.scad til at lægge
// hver lag udadgående fra stud-fladen. Klink-tykkelse kommer fra V3_CLAD
// (defineret i build.scad) via cs_thick(clad).
V3_VP_T         = 1;     // vindpapir (membran)
V3_AL_T         = 22;    // afstandsliste (22×45 lodret klemmeliste)

// House floor (strøer + krydsfiner inside the fundablok ring).
V3_FLOOR_LEDGER_W   = 95;
V3_FLOOR_LEDGER_H   = 45;
V3_FLOOR_DECK_T     = 18;
V3_FLOOR_JOIST_W    = 45;
V3_FLOOR_JOIST_H    = 95;
V3_FLOOR_JOIST_C2C  = 600;
// Top of krydsfiner = floor finish = bundrem top (V3_FLOOR_TOP=167).
V3_FLOOR_DECK_Z     = V3_FLOOR_TOP - V3_FLOOR_DECK_T;  // = 149 (top of strøer)
// Ledger top = bottom of strøer.
V3_FLOOR_LEDGER_Z   = V3_FLOOR_DECK_Z - V3_FLOOR_JOIST_H;  // = 54

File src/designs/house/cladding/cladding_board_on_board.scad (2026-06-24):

// Board-on-board cladding on the 4 house walls.
// Stickout: housewrap 1 + batten 22 + boards 2 × 25 = 73 mm; trim 70×70.
// All 4 walls share one flat eave (RH_EH_FRONT == RH_EH_BACK) — gable
// rafters above create the pitch.

include <../../../lib/defaults.scad>
include <../../config.scad>
use <../../../lib/primitives/cladding.scad>
use <cladding_common.scad>

module render_cladding_board_on_board(bob = RH_CLAD_BOB,
                                       palette = DEFAULT_PALETTE) {
    hl  = RH_HOUSE_LEN; ww = RH_HOUSE_DEPTH; bh = RH_BASE_H;
    eh  = RH_EH_FRONT;
    sd  = RH_POST_W;    pl  = RH_SILL_H;

    ct      = bs_stickout(bob);                  // 2 × board_t = 50
    s       = RH_HOUSEWRAP_T + RH_COUNTER_BATTEN_T;
    trim_w  = 70;
    o       = s + ct;                             // outer-corner offset
    part_x  = hl;                                 // V4 yard-side outer face

    butt_y0  = sd;
    butt_len = ww - 2 * sd;

    house_dz   = RH_FLOOR_TOP;
    pet_dz     = RH_FLOOR_TOP + 15;

    // -- Housewrap (vindpap on the outside face of the studs).
    render_housewrap([0, -RH_HOUSEWRAP_T, bh], hl, eh - pl, "X");
    render_housewrap([0, ww,              bh], hl, eh - pl, "X");
    render_housewrap([-RH_HOUSEWRAP_T, 0, bh], ww, eh - pl, "Y");
    difference() {
        render_housewrap([part_x, butt_y0, bh], butt_len, eh - pl, "Y");
        translate([part_x - 1, RH_HOUSE_DOOR_Y, house_dz])
            cube([RH_HOUSEWRAP_T + 2, RH_HOUSE_DOOR_W, RH_HOUSE_DOOR_H]);
        translate([part_x - 1, RH_PET_DOOR_Y, pet_dz])
            cube([RH_HOUSEWRAP_T + 2, RH_PET_DOOR_W, RH_PET_DOOR_H]);
    }

    // -- Counter-battens (horizontal — bob boards run vertical).
    render_horizontal_battens([0, -s, bh],                  hl, eh, "X");
    render_horizontal_battens([0, ww + RH_HOUSEWRAP_T, bh], hl, eh, "X");
    render_horizontal_battens([-s, 0, bh], ww, eh, "Y");
    render_horizontal_battens(
        [part_x + RH_HOUSEWRAP_T, butt_y0, bh], butt_len, eh, "Y",
        skip_zs = [[house_dz, house_dz + RH_HOUSE_DOOR_H],
                   [pet_dz,   pet_dz   + RH_PET_DOOR_H]]);

    // -- Bob boards.
    clad_wall_bob_rect([0, -(s + ct), bh], hl, eh, "X", palette, bob);
    clad_wall_bob_rect([0, ww + s,    bh], hl, eh, "X", palette, bob);
    clad_wall_bob_rect([-(s + ct), 0, bh], ww, eh, "Y", palette, bob);
    difference() {
        clad_wall_bob_rect([part_x + s, butt_y0, bh], butt_len, eh, "Y",
                           palette, bob);
        translate([part_x + s - 10, RH_HOUSE_DOOR_Y, house_dz])
            cube([ct + 20, RH_HOUSE_DOOR_W, RH_HOUSE_DOOR_H]);
        translate([part_x + s - 10, RH_PET_DOOR_Y, pet_dz])
            cube([ct + 20, RH_PET_DOOR_W, RH_PET_DOOR_H]);
    }

    // -- Corner trim posts.
    render_corner_post([-o,              -o,              bh], trim_w, eh, palette);
    render_corner_post([hl + o - trim_w, -o,              bh], trim_w, eh, palette);
    render_corner_post([-o,              ww + o - trim_w, bh], trim_w, eh, palette);
    render_corner_post([hl + o - trim_w, ww + o - trim_w, bh], trim_w, eh, palette);
}

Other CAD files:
src/main.scad
_archive/v1/build.scad
_archive/v1/config.scad
_archive/v2/build.scad
_archive/v2/config.scad
designs/house_yard_v2/build.scad
designs/house_yard_v3/build.scad
designs/lean_to_v1/build.scad
docs/arbejdsplan/img/_anchor_scene.scad
docs/arbejdsplan/img/_beslag_view.scad
docs/arbejdsplan/img/_floor_design.scad
docs/arbejdsplan/img/_gulv_setout.scad
docs/arbejdsplan/img/_lem_view.scad
docs/arbejdsplan/img/_trappe_snit.scad
src/designs/ground.scad
src/designs/house/basement.scad
src/designs/house/cladding/cladding.scad
src/designs/house/cladding/cladding_common.scad
src/designs/house/cladding/cladding_klink.scad
src/designs/house/floor.scad
src/designs/house/foundation.scad
src/designs/house/framing.scad
src/designs/house/openings.scad
src/designs/house/roof.scad
src/designs/house/roof/haneband.scad
src/designs/house/roof_gable.scad
src/designs/house/roof_plates.scad
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

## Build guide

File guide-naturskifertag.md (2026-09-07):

# Guide: Oplægning af naturskifertag (dobbelt dækning)

> **Målgruppe:** AI-agent eller person, der skal rådgive om eller planlægge oplægning af tag med naturskifer i Danmark.
> **Scope:** Rektangulær naturskifer lagt i klassisk dobbelt dækning med kobbersøm på lægter eller fast undertag. Facadeskifer, diagonaldækning og krogsystemer er kun kort berørt.
> **Kilder:** Syntese af Cupa Danmarks projekteringsvejledning, Komproments montagevejledning for naturskifertag, Inpros oplægningsvejledning samt almen dansk tagfaglig praksis (TRÆ 54, DUKO, Tekniq Tag- og Facademappen). Ved konflikt mellem denne guide og den konkrete skiferleverandørs anvisninger gælder leverandørens anvisninger.

---

## 0. Parametre agenten skal afklare, før der rådgives konkret

Disse fem parametre styrer stort set alle tal i guiden. Indhent dem først:

1. **Taghældning** (grader) — styrer overlæg, lægteafstand og krav til undertag.
2. **Stenformat** — typisk 60×30, 50×25, 40×20 eller 60×35/65×40 cm (ældre "Port Madoc"-formater). Styrer lægteafstand og forbrug pr. m².
3. **Skifertykkelse** — typisk 4–8 mm (glat spansk skifer) eller 7–12 mm (rustik). Styrer sømdimension og listetykkelser.
4. **Underkonstruktion** — lægter med banevareundertag, lægter på fast undertag (brædder/krydsfiner + tagpap), eller skifer direkte på rupløjede brædder med pap (svensk/københavnsk metode).
5. **Ny eller genbrugsskifer** — genbrugsskifer kræver hårdere sortering, højere spildprocent og kontrol af eksisterende sømhuller.

---

## 1. Sikkerhed og grundregler

- Arbejde på tag kræver stillads og faldsikring efter gældende AT-regler. Skifer er tungt (paller på 1,1–1,5 ton med 25–40 m² tag pr. palle) — planlæg kranløft/materialehejsning.
- **Et skifertag må ikke betrædes under montagen.** Stenene knækker eller revner usynligt under punktlast. Arbejd fra lægterne (eller fra stilladset/tagstiger med trykfordeling ved fast undertag).
- Skifer kan indeholde skjulte revner. Håndtér gerne stenene "kontant" ved sorteringen på jorden, så defekte sten afsløres **før** de sidder på taget.
- Ved skæring: brug støvmaske og øjenværn. Stenstøv skal ikke indåndes.

---

## 2. Materialer

### 2.1 Skiferen
- Naturskifer skal opfylde **EN 12326-1/-2**. Efterspørg bedste klasser: vandabsorption A1, pyrit/urenheder T1, syrebestandighed S1.
- Kontroller ved modtagelse, at alle paller har originale pallemærker (producent, brud/produktnavn, antal, pallenummer). Gem pallemærkerne i kvalitetssikringen — de er også forudsætning for produktgaranti (typisk 30 år).
- Forvent en frasortering på **op til 5 %**. Frasorterede sten bruges som underliggere ved tagfod eller til tilskæringer.

### 2.2 Fastgørelse
- **Kun kobbersøm** (evt. rustfast ved særlige forhold — aldrig almindelige galvaniserede søm til et tag, der skal holde 100+ år). Let riflede søm Ø 2,8–3,0 mm:
  - Skifertykkelse 4–8 mm → **2,8 × 40 mm kobbersøm**
  - Skifertykkelse 7–12 mm → **3,0 × 50 mm kobbersøm**
- **To søm pr. sten.** Alternativ: forlokket skifer i krog-/skinnesystem (leverandørspecifikt, egen vejledning).

### 2.3 Træ
- Taglægter: typisk **T1-lægte 38×73 mm** (dimensioneres efter spærafstand og snelast).
- Afstandslister over undertag: **25×50 mm trykimprægneret**.
- Skiferliste/opklodsningsliste ved tagfod: ca. **10×25 mm** (5–7 mm kan bruges ved tynde sten — formålet er at give startrækken samme hældning som resten af taget).
- Afstandsliste ved kip: ca. **8×25 mm**, så øverste række ikke vipper.
- Underliggende materialer skal i kvalitet matche skiferens levetid (100–150 år). Spar ikke på undertag, lægter og inddækninger.

### 2.4 Kit
- Ved oplægning uden undertag eller i randzoner: **skiferkit på basis af rågummi og polymeriseret vegetabilsk olie** (fx DANA Skiferkit 694). Kit der udtørrer (alm. fugemasse, silikone, bitumen) må ikke bruges.

### 2.5 Inddækninger og tilbehør
- Zink/kobber til rygning, skotrender, grater, fodblik, gennemføringer. Udførelse efter **Tekniq (Dansk VVS) Tag- og Facademappen** — den er reference for alle inddækningsdetaljer.
- Snefangsrør/snestopjern og tagtrin: montér altid **ekstra lægte/bræt som understøtning**, hvor skiferen belastes af beslaget.

---

## 3. Dækningsprincip og geometri

Naturskifer lægges i **dobbelt dækning**: hver sten dækker to underliggende rækker delvist, og de lodrette fuger forskydes en **halv stens bredde** fra række til række. Det betyder:

- På ethvert punkt af taget ligger der mindst to lag skifer; ved overlægget tre lag.
- **Overlægget (O)** er den strækning, hvor sten i række *n* dækker ind over sten i række *n−2*.
- **Lægteafstanden (a)** beregnes af stenlængden (L):

```
a = (L − O) / 2
```

Eksempel: 600 mm sten med 90 mm overlæg → a = (600 − 90) / 2 = **255 mm** (dette er Komproments standard for 30×60-sten; ved anden lægteafstand skal leverandøren kontaktes).

- **Synlig stenhøjde** pr. række = lægteafstanden a.
- **Forbrug pr. m²** = 1 / (a × stenbredde). Eksempel 60×30 med a = 255 mm: 1 / (0,255 × 0,30) ≈ 13,1 stk./m².

### 3.1 Overlæg og lægteafstand som funktion af taghældning

Kravet til overlæg **stiger, når hældningen falder** (mere vandbelastning og slagregn/fygesne-risiko). Vejledende for 60×30-sten (Inpros skema, konsistent med praksis 90–120 mm overlæg):

| Taghældning | Lægteafstand (cm) | Ca. overlæg (mm) | Forbrug (stk./m²) |
|---|---|---|---|
| 20–25° | 24,0 | 120 | 13,9 |
| 25–30° | 24,2 | 116 | 13,7 |
| 30–35° | 25,5 | 90 | 13,1 |
| 35–40° | 26,0 | 80 | 12,8 |
| 40–45° | 26,5 | 70 | 12,6 |

**Regler for agenten:**
- Under 20°: naturskifer anbefales ikke — hverken med udnyttet eller uudnyttet tagrum.
- 20–30°: kræver altid undertag. Fast undertag (brædder/krydsfiner + tagpap) fra 20°; banevareundertag først fra ca. 25°.
- Over 30°: undertag på lægter eller på rupløjede brædder; forlokket standardskifer anvendes typisk fra ca. 30° og op, hvor lægteafstanden er givet på forhånd.
- I udsatte klimazoner (kyst, fritstående, høj bygning) vælges det største overlæg i intervallet. Ved bygninger over 2 m i udsat terræn bør vindsug beregnes.
- Diagonaldækning og rustik skifer: **altid** undertag.

---

## 4. Underkonstruktion

### 4.1 Tre gangbare opbygninger

**A. Lægter + fast undertag (fra 20°):** Spær → krydsfiner eller brædder → tagpap → trykimprægnerede afstandslister 25×50 → lægter 38×73 → skifer.

**B. Lægter + banevareundertag (fra 25°):** Spær → banevare (diffusionsåben eller -tæt, valgt efter DUKO-klassifikation) → afstandslister → lægter → skifer.

**To forskellige hulrum — bland dem ikke sammen.** Det er den klassiske
forvekslingsfejl, og tallene er vidt forskellige:

| Hulrum | Hvor | Krav |
|---|---|---|
| **Over undertaget** | mellem undertag og tagdækning, dannet af afstandslisten | **min. 25 mm afstandsliste** (trykimp.), både ved diffusionsåbent og -tæt undertag — skal give fri afvanding og udluftning fra tagfod til kip |
| **Under undertaget** | mellem undertag og **isolering**, kun i en *ventileret* konstruktion | **min. 50 mm** ved fast undertag, **min. 70 mm** ved banevare (banevaren hænger ned mellem spærene, så der skal mere til for at holde en gennemsnitshøjde på 50 mm) |

Er der **ingen isolering** under undertaget, eller ligger isoleringen tæt op
mod et **diffusionsåbent** undertag (uventileret konstruktion, kræver tæt
dampspærre), findes det nederste hulrum ikke, og 50/70 mm-kravet gælder
ikke. Så er de 25 mm over undertaget hele ventilationen.

**C. Direkte på rupløjede brædder med tagpap (fra 20°):** Spær → rupløjede brædder med fer og not (1–2 mm luft mellem brædderne) → tagpap, der forsegler omkring sømhullerne → skifer sømmet direkte, uden lægter. Traditionel svensk/københavnsk metode.
   - Fordele: ~63 mm lavere indbygningshøjde (sparer lægte 38 + liste 25 mm), fuld fladeunderstøtning af hver sten, enklere detaljer ved kviste og brandkamme, plads til mere isolering eller til at gøre en uventileret konstruktion ventileret.
   - Ulemper: langsommere oplægning (ingen lægter at gå på og deponere sten på); kræver omhyggelig opstregning med kridtsnor direkte på pappen.

### 4.2 Fugt og ventilation
- Diffusionstætte undertage (typisk undertagspap) **skal altid ventileres** på undersiden. Diffusionsåbne undertage kan have isolering helt op mod undertaget, men så skal der ventileres mellem skifer og undertag, og dampspærren skal være udført upåklageligt.
- Tagrum ventileres med åbningsareal på **min. 1/500 af det bebyggede areal**, jævnt fordelt ved tagfod og kip.
- I paralleltage: ventilationsspalte min. 50 mm ved tagflader op til 12 m — større spalte ved længere tagflader.
- Sørg for intakt dampspærre/tæt loft under tagrummet (inkl. tætsluttende loftlem). Uden det risikeres fugtophobning på skiferens underside.
- Vær opmærksom på **kondensdryp**: sort skifer kan ved natudstråling blive koldere end udeluften, og kondens på undersiden kan dryppe (skiferen suger ikke vand). Endnu en grund til undertag.
- Skiferen selv kræver **ingen** ventilation mod underlaget (frostsikker sten), og samlingerne er relativt diffusionsåbne.

### 4.3 Kontrol af underlag før oplægning (udførendes ansvar)
- Tagfladen skal være plan: **maks. 2 mm afvigelse målt med 2 m retskinne**, både på langs og tværs.
- Lægteafstanden skal være kontrolleret mod det krævede overlæg — en tømrerfejl her kan ikke reddes under dækningen.
- Tagfod skal være lægtet korrekt med underlag for begynderrækken (se 6.1).

---

## 5. Sortering og klargøring af skifer

1. **Sortér alle sten i minimum 3 tykkelser** — på jorden, altid før oplægning, og helst af de samme folk, der skal lægge taget. Sortering "på farten" oppe på taget bliver for tilfældig.
2. **Bland sten fra flere paller** samtidig — der er farvespil mellem paller, og blanding giver en ensartet, levende tagflade.
3. **Fordelingen på taget:** tykkeste sten nederst ved tagfod, mellemtykkelse på midten, tyndeste øverst mod kip. (Giver korrekt afvanding og et tag, der "ligger ned".)
4. **Kassér** sten der virker skøre eller "skrukke" (lyder dødt ved bankeprøve). Op til 5 % spild er normalt.
5. Sten med hjørneafskæringer kasseres ikke — de lokkes, så det skårne hjørne vender **op under** den overliggende sten og skjules.
6. Rustik skifer sorteres efter samme princip, blot med accept af større variation.

---

## 6. Oplægning — trin for trin

### 6.1 Lokning (hulning) og sømning
- Sømhuller **lokkes fra bagsiden** med lokkeramme (eller spidsen af en skiferøkse), så der dannes et kegleformet hul på forsiden, hvor sømhovedet forsænkes. Brug ikke lokkeværktøj beregnet til eternit/kunstskifer. Tyk rustik skifer kan lokkes fra forsiden.
- Hullernes placering: **25–40 mm fra skiferkant til hullets centrum** (to huller i stenens overdel, symmetrisk).
- **Sømningens gyldne regel:** Sømmet slås i, til hovedet **netop rører** skiferens overflade. Stenen skal ligge fast, men må under ingen omstændigheder spændes op af sømmet — opspænding er den klassiske årsag til revnede sten og utætte tage. Stenen skal kunne "hænge" på sømmene.

### 6.2 Tagfod (startrækken)
1. Montér **opklodsnings-/skiferliste** på tagfodslægten (ca. 10×25 mm ved 4–8 mm sten; 5–7 mm liste kan bruges ved tynde sten), så begynderrækken får samme hældning som de øvrige rækker og ikke vipper.
2. Læg den **usynlige begynderrække** (underliggerne): halve sten eller hele sten lagt vandret, vendt med **bagsiden opad**, tilskåret så tagdækningen rager **50–70 mm ud i tagrenden** (til midt tagrende).
3. Fodblik føres ud i tagrenden. Ved udhæng: opklodsning under første lægte (tilpasset trykimprægneret liste) pr. maks. c/c 1000 mm, så vand kan løbe uhindret til renden. Evt. ventileret fuglegitter.
4. Første synlige række lægges oven på begynderrækken med forskudte fuger.

### 6.3 Selve dækningen
1. **Prøveudlægning:** Læg et referencefelt, vurdér det, og brug det som facit for resten af taget.
2. **Opstregning:** Streg op med kridtsnor for **hver tredje sten** — både vandret (rækkehøjde = lægteafstand ved fast underlag) og lodret (stenbredder), så løbene holder retning over hele fladen. Ved fast undertag uden lægter er opstregning på pappen obligatorisk.
3. Læg nedefra og op, række for række. Hver række forskydes **½ stenbredde** i forhold til rækken under.
4. **Lodret fugeafstand mellem nabosten: 1–5 mm** (typisk 3–5 mm ved tykkere/rustik sten). Stenene må ikke presses mod hinanden.
5. Hver sten fastgøres med to kobbersøm jf. 6.1. Tilpas løbende: en sten der ikke "falder til", flyttes til en anden række, eller et øverste hjørne hugges af, så den lægger sig plant.
6. **Ved kip:** montér ca. 8×25 mm afstandsliste langs overkanten af øverste lægte, så sidste række ikke vipper. Rygning opbygges typisk med rygningsbrædder (fx 25×150 mm opklodset på 15 mm lister pr. 500 mm) og afdækkes med zink. Ventilationsstudse/ventileret rygning sikrer aftræk ved kip.

### 6.4 Tilskæring og værktøj
- **Klassisk (anbefalet):** skiferøkse mod fladstål som underlag — hugningen giver den karakteristiske **affasede kant på forsiden**. Øksens spids lokker huller; nakken bruges som hammer. Alternativt skifersaks (håndsaks eller til boremaskine) — klip altid **fra bagsiden**, så affasningen kommer på forsiden.
- **Vinkelsliber med diamantklinge:** praktisk mulig og nævnes af nogle leverandører, men Cupa fraråder den til naturskifer — snittet mangler den naturlige affasning (skæringen syner "død"), og der er sikkerheds- og støvhensyn. Brug den højst til skjulte snit; synlige kanter hugges/klippes. Vådskærer er et alternativ til lange, skjulte snit.
- Stationær guillotine fungerer, men kræver mere færdsel på taget.

### 6.5 Tilslutninger, gavle og gennembrud ("indskudt skifer")
- Mål taget op, så det så vidt muligt **går op i hele og halve sten** mod gavle, brandkamme, kviste og ovenlys.
- Hvor det ikke går op: **undgå smalle skiferstrimler** — de kan ikke fastgøres forsvarligt. Brug i stedet:
  - **Halvanden-sten-løsningen:** afsluttende sten tilskæres af en ekstra bred sten (fig. "indskudt skifer"), eller
  - tilskær en hel sten i bredden inde på fladen, så den afsluttende sten bliver **min. halv bredde** — accepter at de lodrette løb brydes lokalt.
- Samme principper gælder ved grater og skotrender.
- **Skotrender:** zinkrende på fast underlag (brædder med fer og not + undertagspap ved fast undertag). Skiferen tilskæres mod renden med tilstrækkelig indbyrdes afstand til afvanding.
- Alle inddækninger (skorsten, ovenlys, taghætter, vindskeder) udføres efter Tag- og Facademappen. Naturskifer og lægter holdes ca. 5 mm fri af metalinddækninger.

### 6.6 Kitning (T-kitning)
Bruges ved oplægning **uden undertag** samt i **randzoner og ved gennembrud** selv med undertag:
- Kun **T-kitning** er acceptabel: en jævn, ca. 50–60 mm bred stribe skiferkit i T-mønster på stenen — vandret hen over sømhovederne og lodret i hele den lodrette fuge under den overliggende sten.
- Den lodrette stribe skal være **lige bred hele vejen**, ellers dannes vandlommer.
- **Randzone** = de 3 yderste sten ved gavl, langs skotrender og (i ekstreme vindzoner) ved rygning. **Gennembrud** = skorsten, ovenlys, taghætter: kit de 3 omgivende sten under, over og ved siden af.
- Kun godkendt skiferkit (vegetabilsk olie/rågummi, fx DANA 694) efter fabrikantens anvisning.

---

## 7. Særtilfælde

### 7.1 Oplægning uden undertag
Historisk korrekt (alle gamle danske skifertage ligger sådan), men accepteres i dag kun, hvor bygningsforhold umuliggør undertag. Risiko for fygesne/slagregnsindtrængen især de første år. Kræver konsekvent T-kitning. Diagonal- og rustikskifer må aldrig lægges uden undertag.

### 7.2 Genbrugsskifer
- Regn med væsentligt højere spild end 5 % — bankeprøv hver sten.
- Eksisterende sømhuller: sten kan vendes/omlokkes, hvis gamle huller ender skjult under overlægget; ellers kasseres stenen.
- Sortér ekstra hårdt i tykkelser og størrelser; gamle tage blander ofte formater.
- Ældre store formater (60×35, 65×40) giver andre lægteafstande — brug formlen i afsnit 3.

### 7.3 Udskiftning af enkeltsten i færdigt tag
Brug specialfjeder ("Fix-a-slate" eller tilsvarende): den nye sten skubbes på plads og holdes af fjederen uden synlig fastgørelse. Alternativt klassisk blyklips/tingle.

---

## 8. Kvalitetssikring — tjekliste

**Modtagekontrol:** varer kontrolleret for transportskade; paller opbevaret stående og stabilt; pallemærker gemt.

**Underlag:** planhed ≤ 2 mm/2 m; lægteafstand målt og dokumenteret; tagfod med opklodsningsliste og underlag for begynderrække; undertag/ventilation efter afsnit 4.

**Udførelse:** sten sorteret i 3 tykkelser og blandet fra flere paller; kobbersøm i korrekt dimension; to søm pr. sten, ingen opspænding; opstregning pr. angivet interval; fuge 1–5 mm; forskydning ½ sten; overlæg iht. hældningstabel; randzoner/gennembrud kittet hvor krævet.

**Dokumentation:** lægteafstand (cm), opstregningsinterval, fastgørelsestype, underkonstruktionstype, m² og skifertype noteres i KS-skema; garanticertifikat rekvireres hos leverandør med pallemærker og faktura.

---

## 9. Drift og vedligehold

Naturskifer kræver reelt ingen vedligeholdelse, men periodisk eftersyn anbefales:
- **Udvendigt:** afskalninger/revner (frost, bevægelse, trafik på taget); fastgørelsernes tilstand; alle inddækninger og fuger ved vindskeder, skorsten, ovenlys, skotrender; afrensning af mos/alger/blade; tagrender, nedløb og tagbrønde.
- **Indvendigt:** undertagets tæthed; skotrender; frie ventilationsåbninger.

---

## 10. Hyppige fejl (agentens røde flag)

1. **Opspændte søm** — sten slået fast i stedet for at hænge. Giver revner og utætheder.
2. **For lille overlæg til hældningen** — taget er "tæt" i tørvejr og utæt i slagregn/fygesne.
3. **Ingen sortering i tykkelser** — bulet tagflade, sten der vipper og knækker.
4. **Smalle strimler ved gavle/ovenlys** — kan ikke fastgøres; brug indskudt skifer/halvanden-sten.
5. **Manglende opklodsningsliste ved tagfod/kip** — første og sidste række vipper.
6. **Færdsel på den færdige dækning** under montage.
7. **Forkerte materialer i periferien** — galvaniserede søm, silikonefuge i stedet for skiferkit, undertag/lægter af ringere levetid end stenen.
8. **Manglende ventilation** ved diffusionstæt undertag → kondens og råd i konstruktionen.

---

## 11. Referencer til videre opslag

- Cupa Danmark: Projekteringsvejledning for naturskifer (cupadanmark.com) — fugtprincipper, opbygninger, lokning/sømning, kitning.
- Komproment: Montagevejledning naturskifertag (komproment.dk) — detaljetegninger for tagfod, kip, skotrende; lægteafstand 255 mm for 30×60.
- Inpro: Montering af skifertag (inpro.dk) — sortering, praktisk oplægning, lægteafstandsskema.
- TRÆ 54 "Undertage" (Træinformation) — fast undertag og ventilation.
- DUKO (Dansk Undertagsklassifikationsordning) — valg af banevareundertag.
- Tekniq/Dansk VVS: Tag- og Facademappen — alle metalinddækninger.
- BYG-ERFA-blade om tagdækning, undertage og skotrender — erfaringsbaserede detaljer.
- "Forskrifter for naturskifermaterialer, udførelse og kvalitetssikring", Plandirektoratet 1999 — historisk reference for københavnske ejendomme.

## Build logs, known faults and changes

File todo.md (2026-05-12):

# Todo

1. ~~fundament.scad og fundament.md~~
2. ~~konstruktions-skelet.scad og konstruktions-skelet.md (murpap, bundrem, reglar, toprem)~~
3. ~~aabninger.scad og aabninger.md (døre og vinduer)~~
4. beklaedning.scad og beklaedning.md (vindpap, klemmelister, klink beklædning i huset, voliernet i løbegården)
5. ~~tagkonstruktion.scad og tagkonstruktion.md~~ (to cover-systemer: tagpap_osb + eternit_b7)

## Senere

- Strøer-gulv (floor joists inde i huset) — egen fil eller del af konstruktions-skelet?
- "yard" → "løbegård" rename på tværs af kodebasen.
- rh_house_cladding/vindpapir bruger flade højder på partition+left-væg (skrå tope).
  Top stikker lidt ud over toprem ved den lave ende; intersection med en sloped wedge ville
  gøre det clean. Lavt prioritet — dækkes visuelt af hjørnetrim og roof-overhang.

Vi har beregnet at der skal købes ca. én rulle 10 meter og én rulle af 25 meter voliernet i målene ½ tomme x 1 tomme med 1,2mm trådtykkelse.
Det koster hhv. 400 og 950 kr. så ca. 1350 kr. i alt for det net der skal bruges i løbegården.

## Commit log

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2026-03-09 fixed issues with framing not following the roof
    [cladding.scad, main.scad, walls.scad]
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2026-03-09 Added guidelines for timber framing and cladding corrected.
    [cladding.scad]
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2026-03-09 Cladding fixed back and right side
    [base.scad, cladding.scad, main.scad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]
2026-03-09 Fixed a bug where interiorpanels covered up the window
    [base.scad]
2026-03-09 Redesigned seating
    [seating.scad]
2026-03-09 Redesigned living space
    [colors.scad, main.scad, seating.scad]
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2026-03-09 Added bottom sill plate where it was missing
    [walls.scad]
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2026-04-30 Refactor into multi-design structure; add house_yard_v2
    Promote the project from a single-design model to a parametric library
    with named designs.
    - lib/ holds purified primitives (cladding, mesh, roof variants,
    framing, openings, foundation) + decor (rabbits, accessories,
    landscape, lighting, v1 furniture). All modules take named arguments
    with defaults; ctx vectors (dims, palette, clad/mesh/stud specs)
    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
    [base.scad, build.scad, cladding.scad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]
2026-05-04 Add house_yard_v3: unified mono-pitch + mesh-only yard
    Third design. Same 2x3 m solid house + 4x3 m yard zoning as v2, but
    reorganised around three ideas:
    - ONE continuous mono-pitch roof spans the entire 6x3 m footprint (no
    gable break at the partition), front-eave 2.6 m / back-eave 2.2 m,
    drainage gutter on the back. House side and partition walls become
    mono-pitch cladded (clad_wall_mono_pitch_with_cutout) with a sloped
    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
    [build.scad, config.scad, main.scad]
2026-05-05 v3: add horizontal mid-rail across yard mesh panels
    Splits each yard mesh panel into stacked ~1 m sections by adding one
    horizontal wood rail at sill_top + 1000 mm. The rail uses the same
    40 mm thickness as the perimeter mesh frame, so it reads as part of
    the same panel system. Combined with the existing 1 m vertical stiles,
    the yard exterior now looks like a real welded-mesh fence-panel
    system with clean ~1 m square sections.
    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
    [build.scad, config.scad]
2026-05-05 Set initial GUI viewport so the model frames on file open
    OpenSCAD's default camera distance assumes a model ~tens of mm in
    size; ours is ~6 m, so it landed as a tiny dot until you manually
    zoomed out. Setting $vpt/$vpr/$vpd at the top of main.scad gives a
    sensible 3/4 starting view that fits all three designs (they share
    the same 6x3 m envelope). CLI --camera= flags still override these
    for batch renders.
    [main.scad]
2026-05-05 v3: add transom mesh above yard door, fix back-corner wood protrusion
    Two visual defects spotted in close-up renders:
    1. The front mesh was split AROUND the yard door's X span, leaving the
    442 mm of wall above the door (z=2098..2540) with no mesh -- a hole
    in the predator perimeter. Added a transom mesh panel filling that
    gap so the welded-wire surface is unbroken.
    2. The partition pseudo-posts at X=hl..hl+fpw=2000..2100 cut straight
    through the partition cladding (X=hl..hl+ct=2000..2024) at the back
    corner, and their outer 76 mm (X=2024..2100) was visible behind the
    house back cladding's edge with no wall covering it -- looking like
    wood protruding through the klink.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
    [build.scad]
2026-05-05 Rename designs to v1/v2/v3; remove decorative landscape blobs in v3
    Rename folders and build modules from the long lean_to_v1 / house_yard_v2 /
    house_yard_v3 names to v1/v2/v3 to match how the designs are actually
    referred to. Update main.scad dispatcher, CLAUDE.md, README.md, prd.md, and
    source comments. Dated specs under docs/superpowers/specs/ are left as
    historical records.
    In v3, drop the green sphere clusters and stone-pebble cluster beside the
    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
    [build.scad, config.scad, main.scad]
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2026-05-05 fixed error with studs pertruding cladding on the back of the house
    [main.scad]
2026-05-06 All yard stiles (front, back, right) now sit flush inside the sill plane instead of straddling the wall line
    [build.scad]
2026-05-06 updated framing in v3 to match timber-framing guides and be more structurally correct.
    [build.scad, config.scad, main.scad]
2026-05-06 v3: snap to standard DK timber sizes, slope end-wall toprems, add BOM extraction
    Visible carpentry fixes:
    - Front and back wall toprems now slope across wall thickness (new h_inner
    param on stud_wall) so the inner edge follows the roof underside instead
    of clipping it by 13 mm.
    - Interior collar tie shortened from y=0..ww to y=sd..ww-sd so it bears on
    the front/back toprems rather than passing through them.
    - Partition cladding gets notched cutouts where the yard front and back
    beams pass through, so beams emerge from clean notches.
    Standard timber sizes (config.scad):
    - V3_POST_W: 100 -> 95 (95x95 stolpe)
    - V3_BEAM_H: 180 (95x180 limtree, was already standard)
    - V3_COLLAR_TIE_W/H: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
    [build.scad, config.scad]
2026-05-09 v3: shrink house to 1500 mm + add fundablok strip foundation
    - V3_HOUSE_LEN 2000 → 1500, V3_RUN_LEN 4000 → 4500. House now occupies
    X=0..1500 (1.5 m); yard fills X=1500..6000 (4.5 m). V3_WIDTH 3000 → 2500
    (footprint 6×2.5 m, perimeter 17 m, slope 9.09°).
    - V3_NEST_X 1100 → 200 so the 800-wide nest box fits inside the shorter
    house; V3_NEST_Y 1900 → 1500 to stay against the back wall after the
    width change.
    - New primitive lib/primitives/fundablok.scad with fundablok_ring(ll, ww,
    courses, partitions_x). Renders a 50×15 cm × N-course concrete strip
    around the perimeter plus optional cross-walls under load-bearing
    partitions. Top of foundation at Z=0 (grade), depth =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
    [build.scad, config.scad, main.scad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]
2026-05-09 v3: drop unused V3_PLUG_* constants now that plugs are gone
    The fundablok ring carries the right-end yard corner-post line, so the
    buried 280×280×900 mm concrete plugs (V3_PLUG_W / V3_PLUG_H / V3_PLUG_BURY)
    were removed from the geometry in the previous commit. Their constants
    were left dangling in config.scad — drop them now and update the comment
    header so it reflects 95×95 posts on brackets (not on plugs).
    CLAUDE.md updated to match: "concrete ground plugs are gone since the
    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
    [config.scad]
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2026-05-09 v3: replace 95x95 yard corner stolper with 45x95 reglar
    Per the Phase 1 spec ("yard-vægge — uden plugs/posts"): the right-end
    yard corners no longer need a 95×95 stolpe now that the continuous
    fundablok ring carries the load line. A 45×95 reglar is sufficient.
    Reglar cross-section: 45 mm thin along X × 95 mm wide along Y. Outer
    face flush at X=hl+rl. Y-envelope is unchanged (Y=0..fpw and ww-fpw..ww),
    so adjacent sills, beams, mesh panel breaks, and stiles all keep their
    existing references to V3_POST_W=95 with no further changes needed.
    Steel post-base bracket sized 61×111 (was 111×111) to match the new
    45×95 reglar. BOM updates: yard_corner_post → yard_corner_reglar with
    materi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
    [build.scad, config.scad]
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2026-05-10 v3: extract wall framing (house + yard) into vaegge.scad
    Move 7 helper modules (v3_house_framing, v3_yard_posts_and_sills,
    v3_yard_top_beams, v3_yard_stiles, v3_yard_mesh_front,
    v3_yard_mesh_back, v3_yard_mesh_right) plus 2 mid-rail helpers into
    designs/v3/vaegge.scad and wrap their calls in a single v3_vaegge()
    module. Also move v3_roof_under() and related geometry functions from
    build.scad into config.scad so vaegge.scad can access them via
    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
    [build.scad, config.scad, vaegge.scad]
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2026-05-10 v3/fundament: replace slab+interior_floor with strøer-on-ledger floor
    [fundament.scad]
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2026-05-10 v3/tagkonstruktion: accept ASCII alias 'staal' for stål (CLI -D mojibake fix)
    [main.scad, tagkonstruktion.scad]
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2026-05-10 v3/vaegge: fix framed_opening_y z references to use z_bp_top (=V3_FLOOR_TOP) not bh
    [vaegge.scad]
2026-05-10 v3/vaegge: fix vindkryds rotation direction (X now sits ON wall, not below)
    Negate the Y-rotation angle for axis="X" diagonals so the cube tips upward
    instead of downward. In OpenSCAD rotate([0,+ang,0]) swings +X toward -Z;
    negating gives the correct UP-and-RIGHT / UP-and-LEFT diagonals. Also
    cleaned up the module with diag_len local variable and added comments.
    [vaegge.scad]
2026-05-10 v3/tagkonstruktion: remove redundant ceiling_rafters_mono (real spaer replace it)
    The old 45x140 c/c 900 ceiling_rafters_mono call was left in after v3_spaer
    (45x95 c/c 600) was added in F3. The two overlapped at the same Z, causing
    duplicate members and visual bleed-through. Remove the old call and its
    two local variables (rafter_eave_h, rafter_drop) that were only used for it.
    [tagkonstruktion.scad]
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2026-05-10 v3/tagkonstruktion: tagrende downspout ends at sokkel level (V3_BASE_H)
    fascia_and_gutter_mono() was called with base_h=0, leaving the downspout
    120 mm short of actual grade (sokkel sits at Z=120). Now passes V3_BASE_H
    so the downspout terminates correctly at the fundablok ring top.
    [tagkonstruktion.scad]
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2026-05-10 minor fixses
    [main.scad, materialeliste.csv]
2026-05-10 docs/v3: add fundament.md describing what fundament.scad implements
    Short prose on the ring + cross-wall + bundrem + strøer floor + apron,
    plus a materials table with quantities (prices to be filled in later)
    and a brief build sequence.
    Sets the template for one .md per .scad file in src/designs/v3/.
2026-05-10 v3: split bundrem + murpap into konstruktions-skelet, slim fundament
    User feedback: fundament.md skal kun beskrive selve betonbaserede
    underlag — bundrem, murpap og resten af træ-skelettet hører til en
    ny konstruktions-skelet.scad/md (træ-skelettet ovenpå sokklen).
    Changes:
    - docs/v3/fundament.md: stripped to 6 materials (stabilgrus 10 cm,
    fundablok, armering, cement, støbemix, ankerskruer); cement/støbemix
    replace færdigblandet beton (bygger blander selv); bindetråd dropped;
    alle træ/beslag/floor-items flyttet eller markeret til andre filer
    - src/designs/v3/konstruktions-skelet.scad: NEW. Holder v3_murpap_ring
    (DPC bitumen-tape) + v3_bundrem_ring (kontinuert bundrem) + s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
    [build.scad, fundament.scad, konstruktions-skelet.scad]
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2026-05-10 v3: nedbryd build til kun fundament + flyt strøer + fix ankerbolt-position
    Per todo.md starter vi med kun at rendere fundamentet og bygger op
    herfra system for system.
    Ændringer:
    - src/designs/v3/build.scad: build_v3() kalder kun v3_fundament(); de
    andre system-kald er kommenteret ud med pejling til todo.md-numre
    (slå til efterhånden som de er rettet til)
    - src/designs/v3/fundament.scad: fjernet v3_stroer_floor, rabbit_floor_grass,
    apron_skirt-kald (de hører ikke til fundamentet). Også fjernet
    helper-modulet v3_stroer_floor — flyttet til konstruktions-skelet.scad
    (per todo.md #2: strøer hører til træ-skelettet)
    - src/designs/v3/konstruktions-skelet.scad: tager imod v3_s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
    [build.scad, fundament.scad, konstruktions-skelet.scad]
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2026-05-10 v3/konstruktions-skelet: tilføj jamb-reglar ved alle åbninger
    Brugerens påpegning: skelettet så "afkappet" ud ved døre/vinduer fordi
    der manglede jamb-reglar — de lodrette reglar der binder hver opnings
    kanter. Jamb-reglar ER reglar (samme dimension, bare på specifik
    position) så de hører hjemme her, ikke i aabninger.
    Tilføjet 8 jamb-reglar (4 åbninger × 2 jambs):
    - Front-væg: yard-dør (V3_YARD_DOOR_X / W)
    - Venstre-væg: side-vindue (V3_SIDE_WIN_Y / W)
    - Partition: human-dør (V3_HOUSE_DOOR_Y / W)
    - Partition: pet-dør (V3_PET_DOOR_Y / W)
    Hver jamb-reglar's INDERFLADE flugter med åbningens kant, så selve
    åbningens lyse-mål er mellem jamb-flader (rough opening = config-v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
    [konstruktions-skelet.scad]
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2026-05-10 v3/konstruktions-skelet: tilføj junction-studs + drop end-stud-gap
    Brugerens kritik: skelettet havde to ting en pro-tømrer aldrig ville lave.
    Fix #1 — Junction-reglar ved T-samlinger:
    Partition-væggen (ved X=hl=1500) mødte front- og bag-væg uden nogen
    perpendikulær reglar i den længdegående væg som partition-væggens
    endestud kunne fastgøres til. Partition-væggen "stod i luften" ved
    endepunkterne. Tilføjet 2 junction-reglar:
    - Front-væg ved X=1500, full HIGH height
    - Bag-væg ved X=1500, full LOW height
    Fix #2 — End-stud-gap på korte vægge:
    Sidemæg + partition er 2500 mm. Sidste grid-reglar endte ved Y=2445,
    end-stud begyndte ved Y=2455 — 10 mm "luftspalte" mellem to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
    [konstruktions-skelet.scad]
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2026-05-10 v3/konstruktions-skelet: butt walls + tilføj framed openings
    To strukturelle fejl bruger pegede på:
    Fix #1 — Vægge må ikke overlappe i den fysiske verden:
    Front + bag-væg løber kontinuert (lange lastebærende vægge). Sidemæg +
    partition BUTTER mod inderfladen af front/bag (Y=95 og Y=ww-95) — de
    går IKKE ind i front/bag's footprint længere.
    - Sill plate, top plate, studs, murpap alle inset til Y=95..ww-95 for
    venstre/højre/partition.
    - Skip-range tjek i _v3_studs_one_wall bruger nu absolut Y/X (origin +
    loop-y) så åbnings-positioner virker uanset wall-origin.
    Fix #2 — Manglende horisontale reglar ved åbningerne:
    Tilføjet v3_framed_opening + v3_framed_openings module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
    [konstruktions-skelet.scad]
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2026-05-10 v3/config: standard dørstørrelser + væghøjder hævet til at rumme dem
    Brugeren bad om standard dørstørrelser så valget ikke giver problemer
    senere (køb af reservedele, udskiftning, kompatibilitet).
    Dørstørrelser:
    - V1 yard-dør: 95×205 cm udhusdør (rough opening 1070×2120)
    Var 850×1900 — for smal+lav til standard udhusdør.
    - V5 human-dør: 80×200 cm indvendig dør (rough opening 870×2050)
    Var 850×2100 — passede ikke i V5's lavere væg-cavity.
    Væghøjder (hæves):
    - V3_EH_FRONT: 2200 → 2400 (V1 cavity 2308mm, rummer udhusdør 2165mm
    + 143mm cripple-margin over header)
    - V3_EH_BACK: 2000 → 2200 (V5 cavity 2108mm, rummer indvendig dør
    2095mm med 13mm gap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
    [config.scad]
2026-05-10 v3/skelet: drop redundante grid-stolper tæt på jamb-reglar
    Brugeren spotted at grid-stolper står 137-272 mm fra vindues-jamb i V3.
    Pro-tømrer ville aldrig have to stolper så tæt — jamb'en er strukturel
    og en grid-stolpe få centimeter ved siden af er bare redundant tømmer.
    Fix: udvid skip_ranges omkring hver åbning med STUD_THICK + JAMB_BUFFER
    (= 45 + 300 = 345 mm) på hver side. Grid-stolper indenfor 300 mm af en
    jamb's yderkant droppes nu.
    Effekt:
    - V1: 12 → 11 stk (1 redundant ved yard-dør højre side)
    - V2: 12 → 12 stk (uændret, ingen åbninger)
    - V3: 6 → 4 stk (2 redundante ved vinduet — det brugeren så)
    - V4: 5 → 5 stk (uændret)
    - V5: 8 → 5 stk (3 redundante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
    [konstruktions-skelet.scad]
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2026-05-10 Removed commentlines from build.scad in v3. they were just noise
    [build.scad]
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2026-05-11 fixed minor stuff
    [build.scad]
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2026-05-11 v3: lookouts erstatter toprem-kantilever + sofitt under alle tagskæg
    V1+V2 toprem klippes tilbage til byggelinjen (X=0..ll). 3 lookouts pr.
    side (45×95 i spær-planet, Y=47,5 / 1250 / 2452,5) kantilevrer fra
    V3/V4-gable-spær og andenrad-spær ud til barge-spæret — textbook
    udlobere i stedet for floating-toprem-shortcut. Notched-through
    gable-spær modelleret som CSG-overlap.
    Sofitt: 18 mm krydsfiner i pal_panel1 (klink-farve), sloped, alle 4
    tagskæg. Front+bag dækker hjørner; sider slutter ved væglinjer.
    Lukker eave-undersiden helt — spær-bunde og lookouts skjult som
    ved rigtig konstruktion.
    [konstruktions-skelet.scad, tagkonstruktion.scad]
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2026-05-11 v3/lookouts: short tværblokke mellem barge og V3/V4-gable (175 mm)
    Lookoutene var unødigt lange — gik fra barge gennem V3/V4-gable forbi
    V1/V2-toprem til andenrad-spær (865 mm). Erstattet med korte tværblokke
    der bare sidder i den 175 mm brede tomgang mellem de to yderste spær.
    Kantilever-moment over side-overhang bæres af OSB som diaphragm
    (standard småhus-konstruktion). Blokken giver lateral fastholdelse
    mellem barge-spær og V3/V4-gable-spær.
    LOOKOUT_INBOARD (645) erstattet af LOOKOUT_LEN (V3_OH_SIDE - V3_SPAER_W
    = 175). Opdateret kommentar i v3_spaer.
    [tagkonstruktion.scad]
2026-05-11 Fix beklaedning: dør-cutouts, sloped tops, korrekt vindpapir-z
    V3 + V5 vægge med skrå toprem havde flade tops på vindpapir og afstandsliste
    hvilket gav synlige gaps mod den skrå toprem.
    Ændringer i beklaedning.scad:
    * Tilføjet `v3_wind_paper_sloped` modul — hull() mellem to thin slabs så
    vindpapiren skråner med tagets fald (matcher toprem-bunden præcist).
    * Tilføjet `_in_any_skip` helper + `skip_ranges` parameter på
    v3_afstandsliste, så lister hvis centerlinie falder i dør/vindue
    droppes (eliminerer liste midt i hus-dør på V5 og side-vindue på V3).
    * v3_afstandsliste bruger nu position-baseret interpolation ved
    lister-FAR-edge (i*c2c + 45) i stedet for index-base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
    [beklaedning.scad]
2026-05-11 fix minor issue
    [build.scad]
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2026-05-12 refactor: archive v1/v2, drop v3 versioning from active design
    Move v1, v2 to _archive/ (frozen, restorable per _archive/README.md).
    Flatten src/designs/v3/* up to src/designs/* and docs/v3/* up to docs/*.
    Rename V3_* constants to RH_*, v3_* modules to rh_*, build_v3 to
    build_house. Fix include paths (../../lib to ../lib after flattening).
    Update main.scad, scripts, CLAUDE.md, README.md, designs/README.md.
    Wall labels V1-V5 in konstruktions-skelet (physical walls in building
    geometry, not version numbers) preserved.
    Verified: openscad renders src/main.scad without errors.
    [aabninger.scad, beklaedning.scad, build.scad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]
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2026-05-12 build.scad: move RH_CLAD and RH_MESH into config.scad
    These are constants (klink profile + yard mesh ctx-vector), not
    orchestration. Moving them to config.scad keeps build.scad strictly an
    orchestrator of Render* calls.
    RH_MESH replaces the default_mesh() helper function — same pattern as
    RH_CLAD: a named ctx-vector constant in config.scad, used directly
    from build.scad.
    [build.scad, config.scad]
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2026-05-12 build.scad: drop redundant clad/mesh/palette args
    RH_CLAD and RH_MESH are now the defaults on RenderCladding and
    RenderOpenings — they're design-fixed constants, not per-render config.
    Add palette=DEFAULT_PALETTE default to RenderRoofPlates dispatcher so it
    can be called without an explicit palette like the other Render* modules.
    build.scad no longer threads a local `pal` alias through every call;
    each module uses its DEFAULT_PALETTE default. The result is a 21-line
    top-level orchestrator with each call carrying only its design-choice
    argument (roof_cover, show_ground).
    [build.scad, cladding.scad, openings.scad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]
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2026-05-12 materialeliste.xlsx: restore hyperlinks + category colors + TBD-marker for estimates
    Regressions fixed from the previous restructure:
    - Restored alle leverandør-hyperlinks fra originalen (klikbare URLer pr.
    vare). Tilføjet nye hyperlinks for eternit (10-4.dk lægter, xl-byg sternbræt,
    bygxtra B7, davidsen tagskruer, wood-online vinkelbeslag) og bob (arossavvaerk
    1-på-2).
    - Genskabt theme-accent farver pr. kategori (column A): fundament=lyseblå,
    konstruktion=fersken, tagpap=lysegrå, eternit_b7=lysegul, klink=lyseblå,
    bob=lysegrøn. Matrix-headerne i summary bruger samme farveskema.
    - Dark navy header-bar, gold TOTAL-rækker, hyperlink-blue+underline på
    leverandør-cellerne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
    [materialeliste.xlsx]
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2026-05-21 Flatten house frame to 2m studs under gable, align V5 on foundation
    - V5 partition wall now sits flush with X=hl (was centered, hung 47.5 mm
    off the foundation strip into yard zone)
    - All 4 house walls share one flat eave at RH_EH=2092 (45+2000+45+DPC),
    so studs are exactly 2 m and the top plate is a single horizontal ring
    - V3 side window removed; partition door RH_HOUSE_DOOR_H reduced to 2000
    so the top plate doubles as the header
    - _gr_top_plates, _gr_knevaeg_v3/v5, _gr_gable_knevaeg_v2 removed from
    roof_gable.scad — no longer a gap to bridge
    - cladding_klink, cladding_board_on_board, cladding_vertical_120 switched
    to clad_wall_rect on all walls; V3 window cutouts removed
    - Ya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
    [cladding_board_on_board.scad, cladding_klink.scad, cladding_vertical_120.scad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]
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2026-05-21 Add V1 front entry door and flanking windows
    V1 (hus forreste væg) får 900×2000 mm dobbelt-lade-dør centreret om X=1000
    og to 415×450 mm kvadratiske vinduer med sål i halv dørhøjde (z=1167 over
    sokkel). Hvert vindue har én dedikeret full-height jamb-stud mod dør-jamben
    (separate stykker træ, ikke fastgjort til dør-karmen) plus outer-cripples
    under sål og over header på hjørnesiden.
    Dør-løvet er bygget som to V-fugede planke-bladser med Z-stiver (top- og
    bund-batten + diagonal) à la lade-dør. Vinduer har simpel karm med
    transparent glas-flade flush med ydervæg.
    Pending docs/konstruktions-skelet.md edits committed med for at lukke det
    gamle dokument inden split til docs/h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
    [config.scad, framing.scad, openings.scad]
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2026-05-22 Real spær construction — hanebånd default, gitterspær reusable
    Replace the hull-of-rafters apex with a buildable spær pattern, choosable
    from main.scad via house_truss = "haneband" | "gitterspaer". Both modules
    live in src/designs/house/roof/ for reuse.
    - haneband.scad: rafter pair + collar tie at 2/3 rise. Rafters meet
    directly at the apex; no ridge board. Hanebånd ends are angle-cut at
    the rafter pitch so the full end face sits flush on the rafter
    underside (no triangular gap at the joint).
    - gitterspaer.scad: king-post W-truss with bottom chord (spændtræ),
    king post (kongepost), two skråtræer + a separate ridge board.
    Strut top ends angle-cut at the rafter pitch; rid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
    [gitterspaer.scad, haneband.scad, main.scad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]
2026-06-20 Add house floor (reglar frame + board deck) + arbejdsplan
    - New src/designs/house/floor.scad: RenderHouseFloorJoists (perimeter
    45x95 reglar frame along V3/V5/V1/V2 + center cross at Y=1500) and
    RenderHouseFloorDeck (~25 mm boards, short way), wired into main.scad
    - config.scad: floor levels — deck top flush with ring top, 45x95 reglar
    - Floor is 25 mm sawn boards instead of plywood (config + CLAUDE.md)
    - ground.scad: cut grass out of the house foundation footprint
    - main.scad: comment out not-yet-built house steps for progress tracking
    - arbejdsplan.md: full build-step checklist
    - Update foundation docs + materialeliste BOM
    [config.scad, floor.scad, ground.scad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]
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2026-06-24 Omdøb hus-væg V5→V4 (global swap V4↔V5)
    Partition bliver V4, yardens højre gavl bliver V5, så huset hedder rent
    V1-V4 og det globale princip "ét nummer = én væg" bevares. Numrene er nu
    geometrisk ordnet langs X: V3 (venstre) → V4 (partition) → V5 (højre).
    Ren label-/dokumentationsændring: kun kommentarer (.scad), markdown (docs),
    .py-kommentarer og 15 xlsx-celler. Ingen kode-symboler eller geometri ændret
    (OpenSCAD-render verificeret identisk). 33 filer, symmetrisk 201/201 diff.
    [_anchor_scene.scad, _floor_design.scad, basement.scad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]
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2026-07-01 V4 flush dør + ret gavl-tag asymmetri
    - V4 hus-dør: samme flush full-width slab-behandling som V1 front-dør
    (blad flugter klink-fladen, indfatning lapper direkte på, ingen dyb
    lysning / jamb-flicker)
    - Tag: V2 gavl-spær sad Y=3000..3045 (stak 45 mm forbi bagvæggen) mens V1
    sad Y=0..45 (flush). Skiferen (Y=0..3000) dækkede derfor V1's vindskede-
    spær men kun V2's inderside → "flush i den ene ende, skæv i den anden".
    Begge gavl-spær sidder nu flush inde i vægfladerne (V2 → 2955..3000).
    [openings.scad, roof_gable.scad]
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
